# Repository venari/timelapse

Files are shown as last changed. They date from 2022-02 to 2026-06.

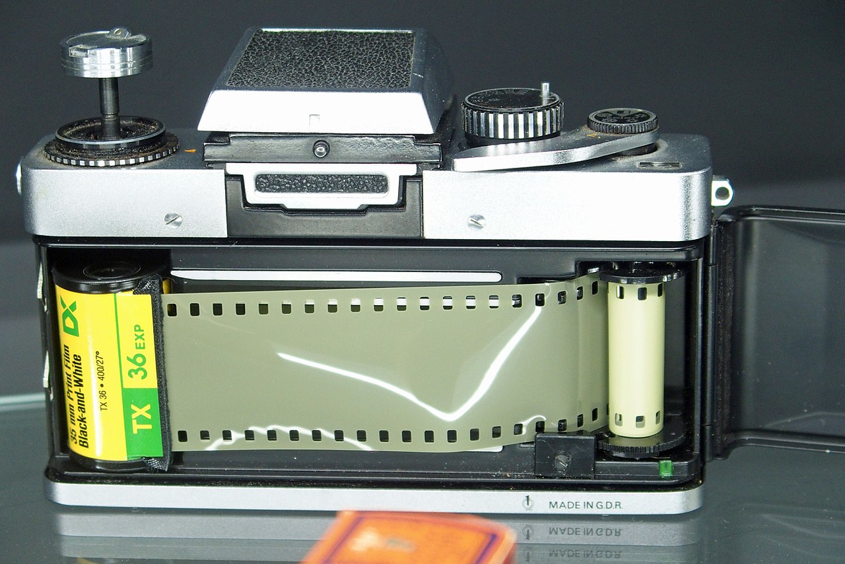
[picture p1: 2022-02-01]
timelapse.api/wwwroot/images/bg-404.jpg

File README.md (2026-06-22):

# timelapse
A set of tools/scripts to automate the taking and creation of timelapse videos and videos with a Raspberry Pi

# Current status of using PiJuice
> [!important]
> In November 2023, I posted an update regards the performance of the PiJuice, even when using PiSupply's own batteries.
>
> However, in the last month (November 2024) I've deployed one further camera that is not using a third party modem board [Waveshare SIM7600-H 4G HAT](https://www.waveshare.com/wiki/SIM7600X_4G_%26_LTE_Cat-1_HAT), but instead has reverted back to a USB thumb modem. Since swapping to this modem, the PiJuice board has behaved perfectly with no missed wakeups or random restarts.
> 
> In addition the ability to purchase PiSupply's PiJuice batteries seems to have returned (even if stock has not).
>
> TL;DR - as long as not combined with either a LiFePO4 battery chemistry or the Waveshare hat above, the PiJuice seems to perform well.
>
> As of June 2026, the PiJuice no longer appears to be being manufactured, an PiSupply appears to have been disolved.
> 
> This project is being migrated to use the PvPi 12V LiFePO4 solar battery charger.
> 
> Documentation will be updated in the coming months.

# PI Setup

Raspberry Pi OS Lite (32 bit - Pi Zero W)
Debian Bookworm - https://downloads.raspberrypi.org/raspios_lite_armhf/images/raspios_lite_armhf-2025-05-13/2025-05-13-raspios-bookworm-armhf-lite.img.xz

Raspberry Pi OS Lite (64 bit - Pi Zero 2 W
Debian Bookworm - https://downloads.raspberrypi.org/raspios_lite_arm64/images/raspios_lite_arm64-2025-05-13/2025-05-13-raspios-bookworm-arm64-lite.img.xz

Burn using Pi Imager. Give a default name, but you can change this inthe install script below.

Set username and password, and authentication methods as desired.

## All versions up to Bullseye.

Mount (reinsert) SD card
<!-- diskutil mount /dev/disk4s1 -->
```
cp ~/wpa_supplicant.conf /Volumes/bootfs
diskutil unmount /Volumes/bootfs
```

If updating the wpa_supplicant file, and you have network access:
```
scp ~/wpa_supplicant.conf pi@[pi name]:~
```
And then on the pi:
```
sudo cp ~/wpa_supplicant.conf /etc/wpa_supplicant/wpa_supplicant.conf
sudo reboot
```

## Bookworm onwards:
Bookworm uses NetorkManager rather than WPA Supplicant.

Ensure you have local wifi network access when you burn the image.

Individual network addition:
```
sudo nmcli dev wifi connect <wifi-ssid> password "<network-password>"
```

```
scp ~/nmcli-connect.sh pi@[pi name]:~
```
And then on the pi:
```
chmod u+x ~/nmcli-connect.sh
sudo ./nmcli-connect.sh
```

Note - this will only connect to WIFI networks that are present, so ensure modem stays with camera.

Turn on and find the pi
Pi Zero W 2:
```
arp -a | grep e4:5f
raspberrypi.lan (192.168.86.37) at e4:5f:1:5a:6e:b3 on en0 ifscope [ethernet]
```

Pi Zero W:
```
arp -a | grep b8:27
raspberrypi.lan (192.168.86.32) at b8:27:eb:94:ac:b1 on en0 ifscope [ethernet]

```

# Install (or update) software, (LiPo and LiFePO4, sedicam v2 configuration) config & code to new Pi:
```
sudo apt-get install byobu -y
byobu-enable
byobu
```
```
bash <(curl -fsSL "https://github.com/venari/timelapse/raw/main/install.sh?$RANDOM")
```

# Connect to intermitently connected Pi and tail log:
```
ssh -o ConnectTimeout=60 -o ConnectionAttempts=30 pi@sediment-pi-zero-w-v1-a 'tail -f -n 100 logs/timelapse.log'
```

Connect to intermitently connected Pi and trigger reboot:
```
ssh -o ConnectTimeout=60 -o ConnectionAttempts=30 pi@sediment-pi-zero-w-v1-a 'sudo reboot now'
```

Copy log files to local machine:
```
scp -o ConnectTimeout=60 -o ConnectionAttempts=30 pi@sediment-pi-zero-w-v1-a:/home/pi/logs/*.* .
```

# Review systemd job status
```
watch --color SYSTEMD_COLORS=1 systemctl status enviro*.service
```

# restart a systemd job
```
sudo systemctl restart envirocam-telemetry
sudo systemctl restart envirocam*
```

# Waveshare SIM6700X GSM/GPRS/GNSS HAT

- Enable Serial Communication
```
sudo raspi-config nonint do_serial 2        # Disable serial login shell and enable serial port hardware
sudo reboot
```

https://core-electronics.com.au/guides/raspberry-pi/raspberry-pi-4g-gps-hat/
```
sudo apt-get install minicom
pip3 install pyserial
wget https://www.waveshare.com/w/upload/2/29/SIM7600X-4G-HAT-Demo.7z
sudo apt-get install p7zip-full

7z x SIM7600X-4G-HAT-Demo.7z -r -o/home/pi

sudo chmod 777 -R /home/pi/SIM7600X-4G-HAT-Demo

sudo nano /etc/rc.local

```
Add following line, just above `exit 0`:

```
sh /home/pi/SIM7600X-4G-HAT-Demo/Raspberry/c/sim7600_4G_hat_init
```

```
cd /home/pi/SIM7600X-4G-HAT-Demo/Raspberry/c/bcm2835
chmod +x configure && ./configure && sudo make && sudo make install
```

Plug in USB cable, testing with minicom
CTRL-A, E to echo
CTRL-A, Q to exit
```
minicom -D /dev/ttyUSB2

AT+CPIN?
+CME ERROR:10 # No SIM card
```

Switch to RNDIS dial up mode
https://www.waveshare.com/wiki/Raspberry_Pi_RNDIS_dial-up_Internet_access
```
AT+CUSBPIDSWITCH=9011,1,1
```

Nope - prevents camera from working...

    Disable HDMI:
    https://picockpit.com/raspberry-pi/raspberry-pi-zero-2-battery/

    sudo raspi-config

    Then, go to Advanced Options -> GL Driver -> Legacy

    Add to /etc/rc.local:
    /usr/bin/tvservice -o

<!-- `camera.lensposition` - 1/distance in metres
- '0' - infinity
- '1': 1m
- `5`: 20cm
- `10`: 10cm -->

<!-- `camera.focus_m`: focus in metres -->

<!-- Add following to /boot/config.txt
```
dtoverlay=imx708
``` -->

# Waveshare 1.54" e-Paper Module
## Not may not work on Bookworm

https://github.com/waveshareteam/e-Paper/blob/master/RaspberryPi_JetsonNano/python/examples/epd_1in54b_V2_test.py

```
    sudo apt-get update
    sudo apt-get install python3-pip
    sudo apt-get install python3-pil
    sudo pip3 install RPi.GPIO
    sudo pip3 install waveshare-epaper
```

Onboard image resizing
```
sudo apt-get install imagemagick

convert pic/image.org.jpg -resize 200x200 -background white -gravity center -extent 200x200 pic/image.jpg 
```

- Enable Serial Communication
```
sudo raspi-config nonint do_spi 0        
sudo reboot
```

# Uptimed service

```
sudo apt-get install uptimed
sudo systemctl enable uptimed
```

# preview image over VNC
https://www.youtube.com/watch?v=dbBWyeHbGs0&ab_channel=WillyKjellstrom

Set screen VNC resolution:
sudo raspi-config
	-> 2 Display Options
		-> D5 VNC Resolution

To disable:
https://help.realvnc.com/hc/en-us/articles/5060068870813-Disabling-direct-capture-on-Raspberry-Pi-using-the-command-line
sudo sed -i '/CaptureTech/d' /root/.vnc/config.d/vncserver-x11
sudo vncserver-x11 -service -reload

Issues in Bullseye on Zero2? https://www.raspberrypi.com/news/bullseye-camera-system/

- related - possibly not - https://github.com/raspberrypi/libcamera-apps/issues/278
- 

# Access Hauwei thumb stick web interface (password is fiddly)
```
ssh -D 8080 pi@sediment-pi-[machine name]
```

Use FoxyProxy and setup proxy to localhost:8080

Browse to http://192.168.1.1/html/index.html or http://192.168.8.1/html/index.html

# On board timelapse generation

```
ffmpeg -r 30 -f image2 -pattern_type glob -i "./<YYYY-MM-DD>*.jpg" -s 1014x760 -vcodec libx264 <YYYY-MM-DD>.mp4
```

# Other timelapse generation examples

```
ffmpeg -r 30 -f image2 -pattern_type glob -i  "*11_2023-01-03*.jpg" -s 3280x1844 -vcodec libx264 output.mp4
```

## Overlay label and date/time in images:
```
mkdir -p mod

label="<Label for bottom left>"

for filename in <filter>_*.jpg; do 
    date_time="$(echo ${filename:3:10} ${filename:14:2}\\:${filename:16:2})"
    ffmpeg -i $filename -y -vf "drawtext=fontfile=/System/Library/Fonts/Avenir.ttc:text='$label':fontcolor=white:fontsize=90:box=1:boxcolor=black@0.3:boxborderw=5:x=10:y=h-th-10,drawtext=fontfile=/System/Library/Fonts/Avenir.ttc:text='$date_time':fontcolor=white:fontsize=90:box=1:boxcolor=black@0.3:boxborderw=5:x=w-tw-10:y=h-th-10" -hide_banner -loglevel error mod/$filename
done

ffmpeg  -pattern_type glob -i "mod/14_*.jpg" -vf "scale='min(1280,iw)':-2,format=yuv420p" -c:v libx264 -preset medium -profile:v main -c:a aac -shortest -movflags +faststart ../Output/<SiteName>.mp4
```

# Video stabilization

https://www.paulirish.com/2021/video-stabilization-with-ffmpeg-and-vidstab/

```
ffmpeg -i unstabilized.mp4 -vf vidstabdetect -f null -
ffmpeg -i unstabilized.mp4 -vf vidstabdetect=shakiness=1:tripod=1 -f null -
ffmpeg -i unstabilized.mp4 -vf vidstabtransform stabilized.mp4
```

Comparison video:
```
# vertically stacked
ffmpeg -i unstabilized.mp4 -i stabilized.mp4  -filter_complex vstack compare-stacked.mp4

# side-by-side
ffmpeg -i unstabilized.mp4 -i stabilized.mp4  -filter_complex hstack compare-sxs.mp4
```

# API Setup
Prerequisites:
- [Dotnet 6](https://dotnet.microsoft.com/en-us/download)
- [EFCore Tooling](https://docs.microsoft.com/en-au/ef/)
```
brew install dotnet-sdk
brew install pgadmin4
dotnet tool install --global dotnet-ef
```

Postgres DB Server:
```

docker pull postgres

mkdir ${HOME}/postgres-data/

docker run -d \
	--name dev-postgres \
	-e POSTGRES_PASSWORD=Pass2020! \
	-v ${HOME}/postgres-data/:/var/lib/postgresql/data \
        -p 5432:5432 \
        postgres

docker exec -it dev-postgres bash        
```

User Secrets:
```
dotnet tool install dotnet-user-secrets
dotnet user-secrets --project timelapse.api init
dotnet user-secrets --project timelapse.api set "ConnectionStrings:DefaultConnection" "Host=localhost;Port=5432;User ID=postgres;Password=Pass2020!;Database=timelapse"
```

When making changes to the objects in the code, add migrations and update the database script:
```
dotnet ef --project timelapse.api migrations add --context "AppDbContext" <migrationName>
dotnet ef --project timelapse.api migrations script -i --context "AppDbContext" -o timelapse.api/Migrations/scripts.sql
```

Updating database:
```
dotnet ef --project timelapse.api database update
```

# Enable Wake Up and set RTC Time

Note - Wake up should be automatically enabled in `saveTelemetry.py`, but you will need to set the RTC time during installation.
```
░░░░░░░░░░░░░░░░░░░░░░░░░░░░░░░░░░░░░░░░░░░░░░░░░░░░░░░░░░░░░░░░░░░░░░░░░░
░░░░░░░░░░░░░░░░░░░░░░░░░░░░░░░░░░░░░░░░░░░░░░░░░░░░░░░░░░░░░░░░░░░░░░░░░░
░░░░░░░░░░░░░░░░░░░░░░░░░░░░░░░░░░░░░░░░░░░░░░░░░░░░░░░░░░░░░░░░░░░░░░░░░░
░░░░░┌───────────────────────── PiJuice CLI ────────────────────────┐░░░░░
░░░░░│  Wakeup Alarm                                                │░░░░░
░░░░░│                                                              │░░░░░
░░░░░│  Status: OK                                                  │░░░░░
░░░░░│  UTC Time: Sun 2000-01-02 19:36:02                           │░░░░░
░░░░░│  [ ] Wakeup enabled                                          │░░░░░
░░░░░│  < Set RTC time    >                                         │░░░░░
░░░░░│                                                              │░░░░░
░░░░░│  (X) Day                      ( ) Weekday                    │░░░░░
░░░░░│  Day: 0                       [ ] Every day                  │░░░░░
░░░░░│  Hour: 0                      [ ] Every hour                 │░░░░░
░░░░░│                                                              │░░░░░
░░░░░│  (X) Minute                   ( ) Minutes period             │░░░░░
░░░░░│  Minute: 0                                                   │░░░░░
░░░░░│  Second: 0                                                   │░░░░░
░░░░░│                                                              │░░░░░
░░░░░│  < Set alarm >                                               │░░░░░
░░░░░│  < Back      >                                               │░░░░░
░░░░░│                                                              │░░░░░
░░░░░└──────────────────────────────────────────────────────────────┘░░░░░
░░░░░░░░░░░░░░░░░░░░░░░░░░░░░░░░░░░░░░░░░░░░░░░░░░░░░░░░░░░░░░░░░░░░░░░░░░
░░░░░░░░░░░░░░░░░░░░░░░░░░░░░░░░░░░░░░░░░░░░░░░░░░░░░░░░░░░░░░░░░░░░░░░░░░
░░░░░░░░░░░░░░░░░░░░░░░░░░░░░░░░░░░░░░░░░░░░░░░░░░░░░░░░░░░░░░░░░░░░░░░░░░
░░░░░░░░░░░░░░░░░░░░░░░░░░░░░░░░░░░░░░░░░░░░░░░░░░░░░░░░░░░░░░░░░░░░░░░░░░
〣 10 0:-*               3m 1.00 1.0GHz 367M13% 14G12% 2022-04-05 02:22:05

░░░░░░░░░░░░░░░░░░░░░░░░░░░░░░░░░░░░░░░░░░░░░░░░░░░░░░░░░░░░░░░░░░░░░░░░░░
░░░░░░░░░░░░░░░░░░░░░░░░░░░░░░░░░░░░░░░░░░░░░░░░░░░░░░░░░░░░░░░░░░░░░░░░░░
░░░░░░░░░░░░░░░░░░░░░░░░░░░░░░░░░░░░░░░░░░░░░░░░░░░░░░░░░░░░░░░░░░░░░░░░░░
░░░░░┌───────────────────────── PiJuice CLI ────────────────────────┐░░░░░
░░░░░│  Wakeup Alarm                                                │░░░░░
░░░░░│                                                              │░░░░░
░░░░░│  Status: OK                                                  │░░░░░
░░░░░│  UTC Time: Tue 2022-04-05 01:23:15                           │░░░░░
░░░░░│  [X] Wakeup enabled                                          │░░░░░  <---
░░░░░│  < Set RTC time    >                                         │░░░░░  <---
░░░░░│                                                              │░░░░░
░░░░░│  (X) Day                      ( ) Weekday                    │░░░░░
░░░░░│  Day: 0                       [ ] Every day                  │░░░░░
░░░░░│  Hour: 0                      [ ] Every hour                 │░░░░░
░░░░░│                                                              │░░░░░
░░░░░│  ( ) Minute                   (X) Minutes period             │░░░░░  <---
░░░░░│  Minute: 10                                                  │░░░░░  <---
░░░░░│  Second: 0                                                   │░░░░░
░░░░░│                                                              │░░░░░
░░░░░│  < Set alarm >                                               │░░░░░
░░░░░│  < Back      >                                               │░░░░░
░░░░░│                                                              │░░░░░
░░░░░└──────────────────────────────────────────────────────────────┘░░░░░
░░░░░░░░░░░░░░░░░░░░░░░░░░░░░░░░░░░░░░░░░░░░░░░░░░░░░░░░░░░░░░░░░░░░░░░░░░
░░░░░░░░░░░░░░░░░░░░░░░░░░░░░░░░░░░░░░░░░░░░░░░░░░░░░░░░░░░░░░░░░░░░░░░░░░
░░░░░░░░░░░░░░░░░░░░░░░░░░░░░░░░░░░░░░░░░░░░░░░░░░░░░░░░░░░░░░░░░░░░░░░░░░
░░░░░░░░░░░░░░░░░░░░░░░░░░░░░░░░░░░░░░░░░░░░░░░░░░░░░░░░░░░░░░░░░░░░░░░░░░
〣 10 0:-*               3m 1.00 1.0GHz 367M13% 14G12% 2022-04-05 02:23:15

```

# Battery min sleep/wake up levels:

```
░░░░░░░░░░░░░░░░░░░░░░░░░░░░░░░░░░░░░░░░░░░░░░░░░░░░░░░░░░░░░░░░░░░░░░░░░░░░░░░░░░░░░
░░░░░░░░░░░░░░░░░░░░░░░░░░░░░░░░░░░░░░░░░░░░░░░░░░░░░░░░░░░░░░░░░░░░░░░░░░░░░░░░░░░░░
░░░░░░░░░░┌───────────────────────── PiJuice CLI ────────────────────────┐░░░░░░░░░░░
░░░░░░░░░░│  System Task                                                 │░░░░░░░░░░░
░░░░░░░░░░│                                                              │░░░░░░░░░░░
░░░░░░░░░░│  [X] System task enabled                                     │░░░░░░░░░░░
░░░░░░░░░░│                                                              │░░░░░░░░░░░
░░░░░░░░░░│  [ ] Watchdog            Expire period          [ ] Restore  │░░░░░░░░░░░
░░░░░░░░░░│                          [minutes]: 4                        │░░░░░░░░░░░
░░░░░░░░░░│                                                              │░░░░░░░░░░░
░░░░░░░░░░│  [X] Wakeup on charge    Trigger level [%]: 20  [X] Restore  │░░░░░░░░░░░
░░░░░░░░░░│                                                              │░░░░░░░░░░░
░░░░░░░░░░│  [X] Min charge          Threshold [%]: 10                   │░░░░░░░░░░░
░░░░░░░░░░│                                                              │░░░░░░░░░░░
░░░░░░░░░░│  [ ] Min battery voltage 3.3                                 │░░░░░░░░░░░
░░░░░░░░░░│                                                              │░░░░░░░░░░░
░░░░░░░░░░│  [X] Software Halt Power Delay period [seconds]: 20          │░░░░░░░░░░░
░░░░░░░░░░│      Off                                                     │░░░░░░░░░░░
░░░░░░░░░░│                                                              │░░░░░░░░░░░
░░░░░░░░░░│  < Refresh        >                                          │░░░░░░░░░░░
░░░░░░░░░░│  < Apply settings >                                          │░░░░░░░░░░░
░░░░░░░░░░└──────────────────────────────────────────────────────────────┘░░░░░░░░░░░
░░░░░░░░░░░░░░░░░░░░░░░░░░░░░░░░░░░░░░░░░░░░░░░░░░░░░░░░░░░░░░░░░░░░░░░░░░░░░░░░░░░░░
░░░░░░░░░░░░░░░░░░░░░░░░░░░░░░░░░░░░░░░░░░░░░░░░░░░░░░░░░░░░░░░░░░░░░░░░░░░░░░░░░░░░░
```

# System Events

```
[X] Low Charge : <SYS_FUNC_HALT_POW_OFF>

```

# Battery Profiles

[Headway 38120s 10ah lifepo4 cell](https://evshop.eu/en/batteries/213-headway-lifepo4-38120s-32v-10ah.html)

```

░░░░░░░░░░░░░░░░░░░░░░░░░░░░░░░░░░░░░░░░░░░░░░░░░░░░░░░░░░░░░░░░░░░░░░░░░░
░░░░░┌───────────────────────── PiJuice CLI ────────────────────────┐░░░░░
░░░░░│  Battery settings                                            │░░░░░
░░░░░│                                                              │░░░░░
░░░░░│  Status: Custom profile by: HOST                             │░░░░░
░░░░░│  < Profile: CUSTOM       >                                   │░░░░░
░░░░░│                                                              │░░░░░
░░░░░│  [X] Custom                                                  │░░░░░  <-- Set to Custom
░░░░░│  Chemistry:                LIFEPO4                           │░░░░░  <-- Set to LIFEPO4
░░░░░│  Capacity [mAh]:           15000                             │░░░░░  <-- Set to 15000
░░░░░│  Charge current [mA]:      2500                              │░░░░░  <-- Set to 2500
░░░░░│  Termination current [mA]: 50                                │░░░░░
░░░░░│  Regulation voltage [mV]:  3600                              │░░░░░  <-- Set to 3600
░░░░░│  Cutoff voltage [mV]:      2500                              │░░░░░  <-- Set to 2500
░░░░░│  Cold temperature [C]:     0                                 │░░░░░
░░░░░│  Cool temperature [C]:     2                                 │░░░░░
░░░░░│  Warm temperature [C]:     49                                │░░░░░
░░░░░│  Hot temperature [C]:      65                                │░░░░░
░░░░░│  NTC B constant [1k]:      3450                              │░░░░░
░░░░░│  NTC resistance [ohm]:     10000                             │░░░░░
░░░░░│  OCV10 [mV]:               3131                              │░░░░░  <-- Set to 3131
░░░░░│  OCV50 [mV]:               3263                              │░░░░░  <-- Set to 3263
░░░░░│  OCV90 [mV]:               3303                              │░░░░░  <-- Set to 3303
░░░░░│  R10 [mOhm]:               91.0                              │░░░░░  <-- Set to 91
░░░░░│  R50 [mOhm]:               83.0                              │░░░░░  <-- Set to 83
░░░░░│  R90 [mOhm]:               76.0                              │░░░░░  <-- Set to 76
░░░░░│                                                              │░░░░░
░░░░░│  < Temperature sense: ON_BOARD    >                          │░░░░░  <-- Set to ON_BOARD
░░░░░│                                                              │░░░░░
░░░░░│  < Rsoc estimation: DIRECT_BY_MCU >                          │░░░░░  <-- Set to DIRECT_BY_MCU
░░░░░│                                                              │░░░░░
░░░░░│  < Refresh        >                                          │░░░░░
░░░░░│  < Apply settings >                                          │░░░░░
░░░░░│  < Back           >                                          │░░░░░
░░░░░└──────────────────────────────────────────────────────────────┘░░░░░
░░░░░░░░░░░░░░░░░░░░░░░░░░░░░░░░░░░░░░░░░░░░░░░░░░░░░░░░░░░░░░░░░░░░░░░░░░
░░░░░░░░░░░░░░░░░░░░░░░░░░░░░░░░░░░░░░░░░░░░░░░░░░░░░░░░░░░░░░░░░░░░░░░░░░

```

# Troubleshooting

## Troubleshooting PiJuice wakeup:

```
python3 /usr/bin/pijuice_log.py --enable WAKEUP_EVT
```

## Troubleshooting non-connecting camera:
- [Tailscale - machines connected in last week](https://login.tailscale.com/admin/machines?refreshed=true&q=lastseen%3A%3C1w)
- [Device Trends](https://timelapse-dev.azurewebsites.net/DeviceTrends)

### Failing to connect to Tailscale or timelapse-dev.azurewebsites.net:
- Consult Sediment camera troubleshooting/maintenance checklist.
- If you have physical access to the Pi.
  - Connect HDMI and USB adaptors, and connect keyboard and monitor.
  - Fire up Pi and watch for any error messages, for example complaining about corrupt filesystems, or kernel panics.
  - Log in as user:`pi`, password:`raspberry`.
    - Check network connection status:
      - `ifconfig`
      - `nmcli`
      - List devices: `nmcli device`
      - List known networks: `nmcli connection`
      - Check wireless is on: `nmcli radio`
      - List available wireless networks: `nmcli device wifi list`
      - Connect to CameraAP network: `nmcli device wifi connect CameraAP password GiveMeTheInternets`
    - If `nmcli` isn't available:
      - List wireless networks: `sudo iwlist wlan0 scan | grep ESSID`
      - To connect to network, edit the `/etc/wpa_supplicant/wpa_supplicant.conf` file to add a section, and then `sudo reboot` to restart:
      ````
      ctrl_interface=DIR=/var/run/wpa_supplicant GROUP=netdev
      update_config=1
      country=NZ

      network={
              ssid="CameraAP"
              psk="GiveMeTheInternets"
      }
      ````
    - Check tailscale status
      - `tailscale netcheck`
  - Further troubleshooting:
    - Check envirocam logs
      - `tail -f logs/intent.log`
      - `tail -f logs/timelapse.log`
      - `tail -f logs/intent.log`
      - `journalctl -u envirocam-telemetry.service`
    - Disconnect modem (to rule out data issues) and connect to working WiFi network, with SSID: `CameraAP`, password: `GiveMeTheInternets`.
    - Disconnect PiJuice to determine if that is causing issues.
    - Try fresh install of Raspbian on new SD card to rule out Pi Zero hardware issue.

# Battery notes

Naccon 3.7V 26650HP 5000mAh
On continuously
Charge from wall charger about 5 hours
Discharge 95 -> 5% about 12 hours.
Discharge 4 -> 1$ about 10 hours.

# Tailscale setup (optional)

Using [tailscale](https://github.com/tailscale/tailscale) to manage updates to pi's:

From https://tailscale.com/download/linux/rpi-bullseye:

```
curl -fsSL https://tailscale.com/install.sh | sh
```

```
sudo tailscale up
```

# To access modem/SMS messages

Use SSH to establish a dynamic port forwarding session to the pi.

```
ssh -D 8080 pi@<device name>
```

Use FoxyProxy to route local traffic on port 8080 through the SSH tunnel.

![Alt text](images/FoxyProxySettings.png)

Then browse to the modem's IP address (e.g. http://192.168.1.1)

# To check code versions
```
pssh --hosts ~/dev/venari/timelapse/hosts.txt -t 900 -i 'cd dev/timelapse; git log -1'
pssh --hosts ~/dev/venari/timelapse/hosts.txt -t 900 -x '-o ConnectTimeout=60 -o ConnectionAttempts=15' -i 'cd dev/timelapse; git log -1;git status'
pssh --hosts ~/dev/venari/timelapse/hosts.txt -t 900 -x '-o ConnectTimeout=60 -o ConnectionAttempts=15' -i 'cd dev/timelapse; git diff'
```

# Credits

3D models

- Raspberry Pi Camera Module v3 STL files: https://www.printables.com/model/368779-raspberry-pi-camera-module-3-v3/

# ESP32 version/links

https://www.waveshare.com/wiki/ESP32-S3-SIM7670G-4G

## Upload issue with CH34X driver
```
"/Users/leighhunt/Library/Arduino15/packages/esp32/tools/esptool_py/4.6/esptool" --chip esp32s3 --port "/dev/cu.usbmodem585A0118141" --baud 921600  --before default_reset --after hard_reset write_flash  -z --flash_mode keep --flash_freq keep --flash_size keep 0x0 "/private/var/folders/fx/2h8qyrk51114f5m1_x5dv7yc0000gn/T/arduino/sketches/E83F322CCBA20806EEF325130EA27172/take_photos.ino.bootloader.bin" 0x8000 "/private/var/folders/fx/2h8qyrk51114f5m1_x5dv7yc0000gn/T/arduino/sketches/E83F322CCBA20806EEF325130EA27172/take_photos.ino.partitions.bin" 0xe000 "/Users/leighhunt/Library/Arduino15/packages/esp32/hardware/esp32/3.0.1/tools/partitions/boot_app0.bin" 0x10000 "/private/var/folders/fx/2h8qyrk51114f5m1_x5dv7yc0000gn/T/arduino/sketches/E83F322CCBA20806EEF325130EA27172/take_photos.ino.bin" 
esptool.py v4.6
Serial port /dev/cu.usbmodem585A0118141
Connecting....
Chip is ESP32-S3 (revision v0.2)
Features: WiFi, BLE
Crystal is 40MHz
MAC: 84:fc:e6:51:84:68
Uploading stub...

A fatal error occurred: Failed to write to target RAM (result was 01070000: Operation timed out)
```

CH343 USB chip stuff: https://www.wch.cn/downloads/CH34XSER_MAC_ZIP.html
Arduino
- Board - ESP32S3 Dev Module
- Port - switch from /dev/cu.usbmodem585A0118141 Serial Port to /dev/cu.wchusbserial585A0118141 
- Serial Moonitor - /dev/cu.wchusbserial585A0118141, 115200 baud

VSCode with ESP-IDF
- Set board to ESP32S3
  - OpenOCD Configuration - ESP32-S3 chip (via ESP-PROG-2) seems to work
- Flash method to UART

Terminal attach to serial port:
```
screen /dev/cu.wchusbserial585A0118141 115200
```

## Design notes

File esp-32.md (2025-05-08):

# XAIO ESP32S3 Sense notes

[Getting Started with Seeed Studio XIAO ESP32S3 (Sense)](https://wiki.seeedstudio.com/xiao_esp32s3_getting_started/)
[Development board](https://wiki.seeedstudio.com/Seeeduino-XIAO-Expansion-Board/)
 - [U8g2 library](https://github.com/olikraus/U8g2_Arduino)
https://wiki.seeedstudio.com/xiao_esp32s3_camera_usage/

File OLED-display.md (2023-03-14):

# OLED display

OLED12864 - Digole 128x64 OLED display
I2C address 0x27.

```
sudo apt-get install i2c-tools
```

```
sudo raspi-config
```

3 Interface Options -> I5 I2C -> Yes

```
$ sudo i2cdetect -l
i2c-1	i2c       	bcm2835 (i2c@7e804000)          	I2C adapter
i2c-2	i2c       	bcm2835 (i2c@7e805000)          	I2C adapter
```

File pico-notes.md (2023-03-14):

# Wifi connect

```
import network
import time

wlan = network.WLAN(network.STA_IF)
wlan.active(True)

ssid = "<SSID>"
pw = "<Password>"

wlan.connect(ssid, pw)

def light_onboard_led():
    led = machine.Pin('LED', machine.Pin.OUT)
    led.on();

timeout = 10
while timeout > 0:
    if wlan.status() >= 3:
        light_onboard_led()
        break
    timeout -= 1
    print('Waiting for connection...')
    time.sleep(1)
   
wlan_status = wlan.status()

print("My IP address is", wlan.ifconfig())
print(wlan_status)
```

# On-board - temp sense

```
import machine
import time

temp_sensor = machine.ADC(4)

while True:
    adc_voltage = temp_sensor.read_u16() * 3.3 / 65535
    cpu_temp = 27 - (adc_voltage - 0.706)/0.001721 # Formula given in RP2040 Datasheet
    print(cpu_temp)
    time.sleep_ms(1_000)
```

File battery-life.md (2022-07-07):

Indicative battery timings:

4 days left charging - average weather but good view of sun - with 40W solar panel. June 23 - 26. 
Powered on continuously for 10 hours/day.
Detached 26th - 12V battery kept it charged until 10am Jun 29, thereafter onboard Lithium Ion took over and lasted a further [] hours.
4pm 26th -> 10am 29th = 2 complete days (including running to 3am on 29th)
Actual powered time: 36 hours from 12V 6.5AH battery.
Duty Cycle 50% (7am-7pm) would give 3 days/72 hours battery life with no sunlight.
Plus around 3 hours on SB-2299 2600mAh LiPo until shutdown. (scanning for updates to upload every 10 seconds)

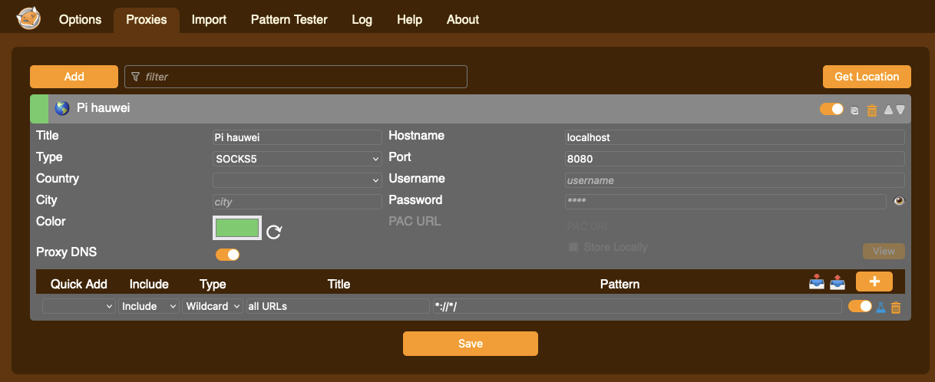
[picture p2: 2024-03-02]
images/FoxyProxySettings.png

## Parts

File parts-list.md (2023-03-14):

Parts list:

| Part | Link 
|---|---
|Enclosure: [Spelsberg TK PS 2518-9-o](https://www.spelsberg.com/industrial-housing/with-/-without-metric-knock-outs/11040801/) (254 x 180 x 90 mm), |via [RS](https://nz.rs-online.com/web/p/general-purpose-enclosures/0220462)
|3D layout enclosure insert | [Tinkercad - Timelapse camera plan v1](https://www.tinkercad.com/things/5YuyqixHnNj)
|18650 Battery | [SB2299 2600mAh Li-ion Protected Battery](https://www.jaycar.co.nz/18650-2600mah-li-ion-protected-battery/p/SB2299)
|18650 Battery Holder | [PH9205 - Single 18650 Battery Holder](https://www.jaycar.co.nz/single-18650-battery-holder/p/PH9205)
|LM2596/XC4514 DC-DC Buck Converter | [Arduino Compatible DC Voltage Regulator](https://www.jaycar.co.nz/arduino-compatible-dc-voltage-regulator/p/XC4514)
|Raspberry Pi Zero 2W |
|PiJuice Zero |
|Camera | [Raspberry Pi Camera Module v3](https://www.pbtech.co.nz/product/SEVRBP0396/Raspberry-Pi-Official-Camera-Module-3-Updated-Vers) 75 degrees
| | [Raspberry Pi Camera Module v3 Wide](https://www.pbtech.co.nz/product/SEVRBP0398/Raspberry-Pi-Official-Camera-Module-3-Wide-Version) 120 degrees
| | [Raspberry Pi Camera Module v3 NoIR](https://www.pbtech.co.nz/product/SEVRBP0397/Raspberry-Pi-Official-Camera-Module-3-NoIR-Updated) 75 degrees
| | [Raspberry Pi Camera Module v3 NoIR Wide](https://www.pbtech.co.nz/product/SEVRBP0399/Raspberry-Pi-Official-Camera-Module-3-NoIR-Wide-Ve) 120 degrees
|Solar Panel option 1 | [ZM9052 - 12V 20W](https://www.jaycar.co.nz/12v-20w-solar-panel-with-clips/p/ZM9052)
|Solar Panel option 2 | [ZM9056 - 12V 40W](https://www.jaycar.co.nz/12v-40w-monocrystalline-solar-panel/p/ZM9056)
|Solar Power connector - socket | [PS1017 - Waterproof IP67 XLR Line Socket](https://www.jaycar.co.nz/waterproof-ip67-xlr-line-socket/p/PS1017)
|Solar Power connector - plug | [PP1014 - IPX6 Surface Mount XLR Male Connector](https://www.jaycar.co.nz/ipx6-surface-mount-xlr-male-connector/p/PP1014)
| Old Parts |
|Camera | [Raspberry Pi HQ Camera](https://www.pbtech.co.nz/product/SEVRBP0263/Raspberry-Pi-HQ-Camera-123-MP-Official-High-Qualit)
|Lens | [CS-Mount 6mm Wide Angle](https://www.pbtech.co.nz/product/SEVRBP0265/Raspberry-Pi-Camera-Lenses-PT361060M3MP12-CS-Mount)
|12V SLA Battery | [SB2485 12V 6.5Ah SLA Battery](https://www.jaycar.co.nz/12v-6-5ah-sla-battery/p/SB2485)

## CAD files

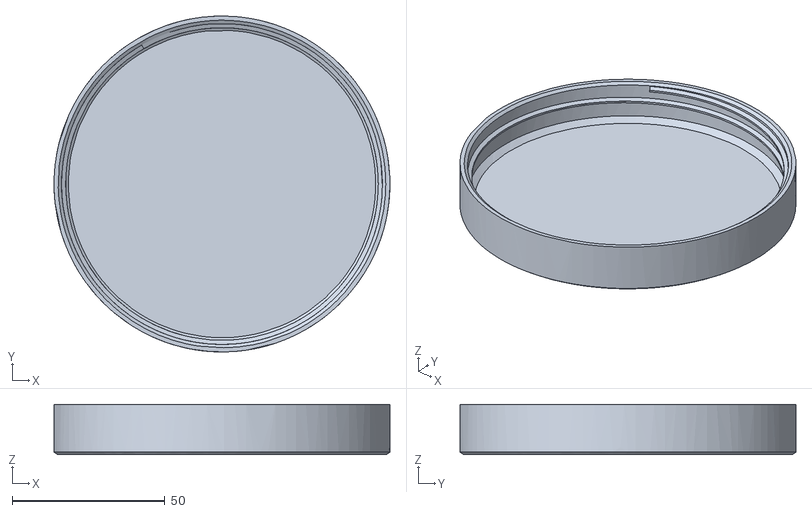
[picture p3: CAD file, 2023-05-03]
3d-models/top cap.110mm.stl
110.0 x 110.0 x 16.4

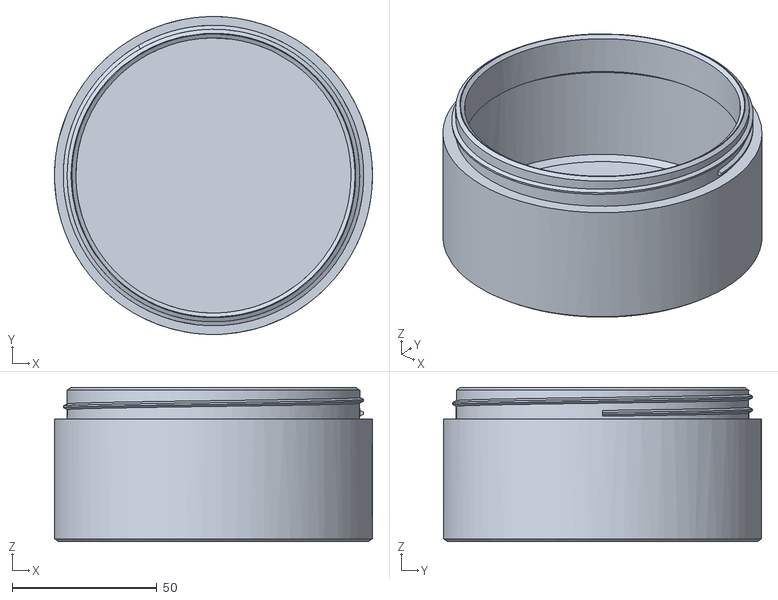
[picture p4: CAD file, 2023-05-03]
3d-models/end cap.110mm.stl
110.0 x 110.0 x 53.4

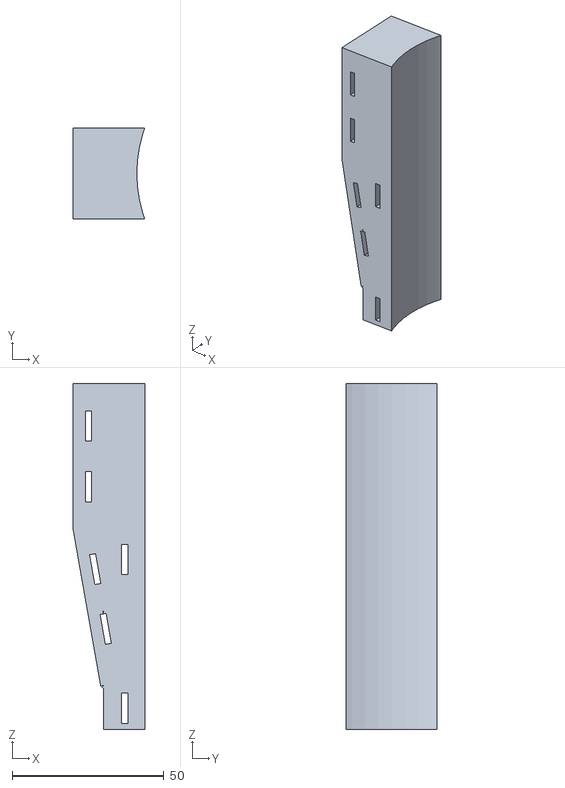
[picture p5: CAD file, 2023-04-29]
3d-models/mount.stl
23.6 x 30.0 x 114.0

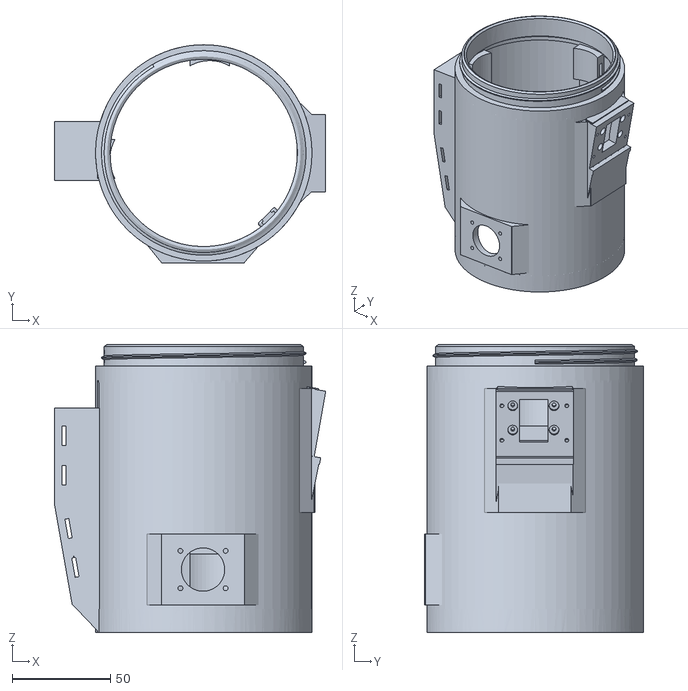
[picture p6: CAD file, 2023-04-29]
3d-models/enclosure.110mm.stl
138.0 x 111.1 x 146.4

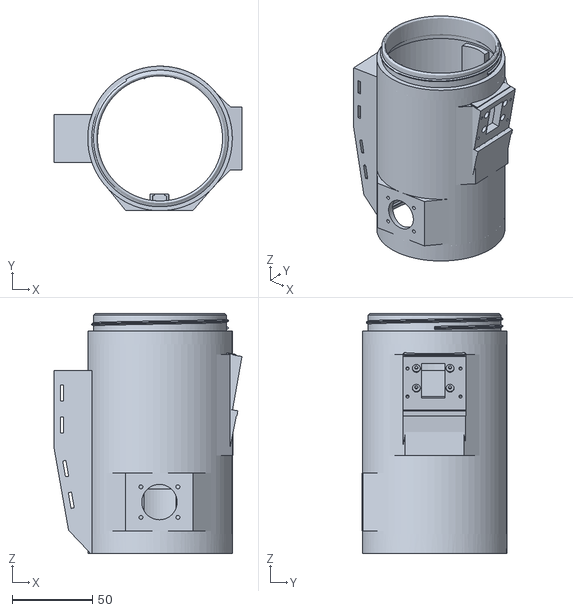
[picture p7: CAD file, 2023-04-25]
3d-models/enclosure.90mm.stl
117.0 x 90.1 x 149.4

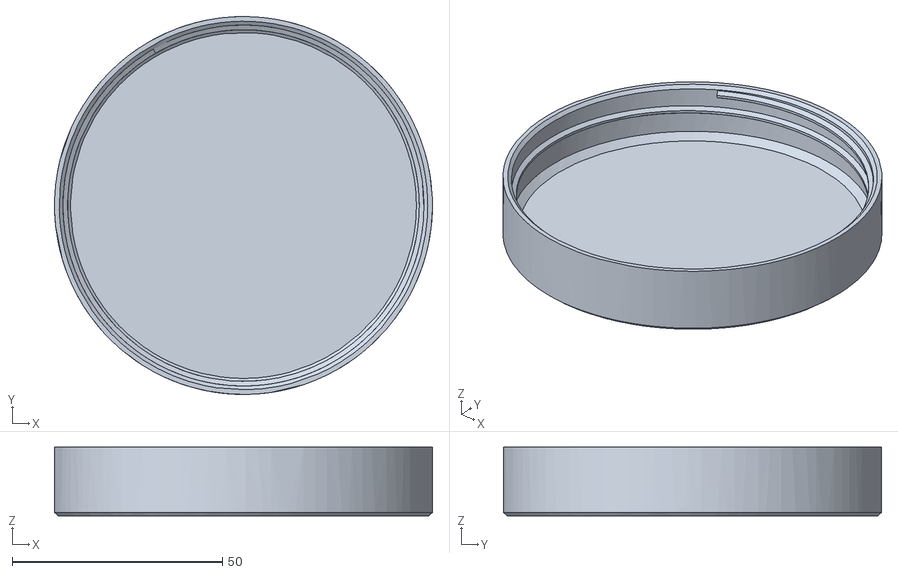
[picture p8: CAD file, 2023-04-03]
3d-models/top cap.90mm.stl
90.0 x 90.0 x 16.4

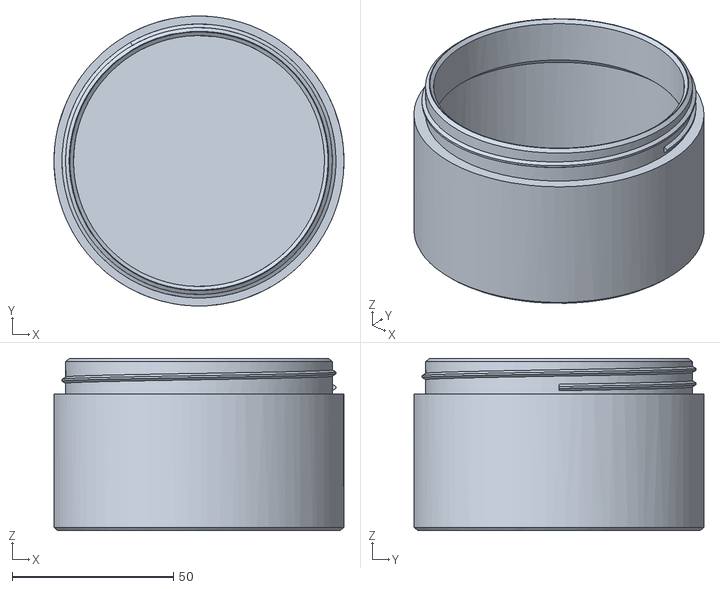
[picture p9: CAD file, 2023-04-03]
3d-models/end cap.90mm.stl
90.0 x 90.0 x 53.4

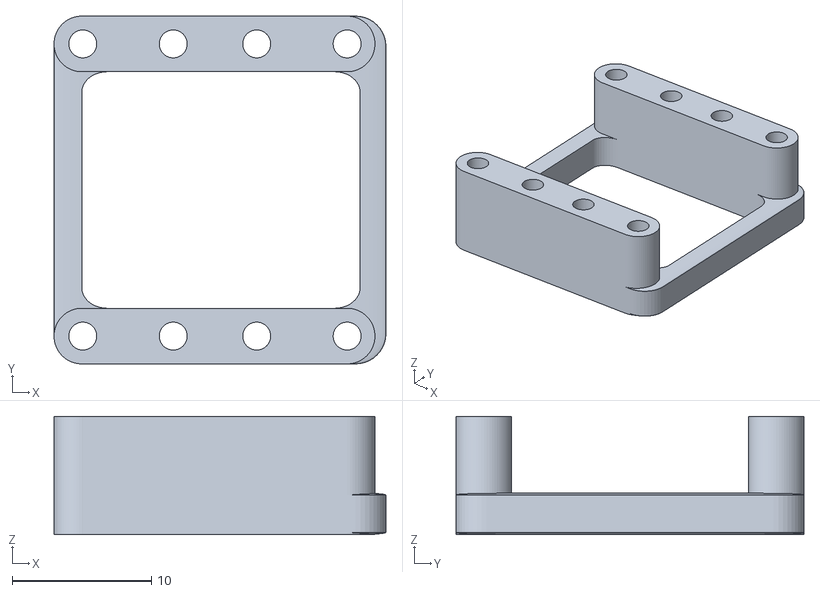
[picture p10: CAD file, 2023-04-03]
3d-models/camera mount.stl
23.9 x 25.0 x 8.50

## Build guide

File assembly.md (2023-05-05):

# Assembly

## Solar Power
Parts:
- [ZM9056 - 12V 40W](https://www.jaycar.co.nz/12v-40w-monocrystalline-solar-panel/p/ZM9056)
- [PS1017 - Waterproof IP67 XLR Line Socket](https://www.jaycar.co.nz/waterproof-ip67-xlr-line-socket/p/PS1017)

1. Cut solar power connectors off solar panel, and solder XLR socker to wires. Positive to Pin <1 - check> and Negative to Pin <check - 2 or 3>
1. Wrap with heat shrink tubing.

## Power in

Parts:
- [PP1014 - IPX6 Surface Mount XLR Male Connector](https://www.jaycar.co.nz/ipx6-surface-mount-xlr-male-connector/p/PP1014)
- LM2596 based [Arduino Compatible DC Voltage Regulator](https://www.jaycar.co.nz/arduino-compatible-dc-voltage-regulator/p/XC4514)
- Terminal block - 2 terminals

1. Connect positive wire between Pin 1 of XLR Male Connector and terminal 1 of terminal block.
1. Connect negative wire between Pin <check - 2 or 3> and terminal 2 of terminal block.
1. Connect another positive wire between terminal 1 of terminal block and Positive IN of LM2596.
1. Connect another negative wire between terminal 2 of terminal block and Negative IN of LM2596.
1. Connect positive wire terminated in Jumper socket to Positive OUT of LM2596. This goes to [Positive Pin of J4](https://github.com/PiSupply/PiJuice/tree/master/Hardware#connectors) on PiJuice Zero.
1. Connect negative wire terminated in Jumper socket to Negative OUT of LM2596. This goes to Negative Pin of J4 on PiJuice Zero.

## Pi mounting

4 x M2.5 x 6 screw
1 x Plastic mount
4 x M2.5 x 6 Pozi Pan (DIN7985)
4 x M2.5 nut (DIN934)
1 x Pi Zero
4 x Pi Juice Zero spacer
1 x Pi Juice Zero
4 x Pi Juice Zero M2.5 screw

## Camera mounting and connecting

4 x M2 x 6 screw 
1 x Camera
1 x Plastic mount

## Mount camera mount to enclosure
<Outside>
4 x M2 x 6 screw 
<enclosure>
1 x Plastic mount
<Inside>

## Mount window to enclosure
Drill out 4 holes in acrylic to 2.5mm so that M2.5 screws can pass through.
<Outside>
4 x M2.5 x 6 Pozi Pan (DIN7985)
<enclosure>

## Cellular 3.3V -> 5V power.

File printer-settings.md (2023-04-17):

Printer settings

PETG Attempt 1

FlashPrint
Printer
 - Material Type - Flashforge-PETG
 - Extruder Temperature - 240
- Raft
 - General 
  - Disable Raft

Not bad, but a bit of stringing on internal walls

PETG Attempt 2

As above, plus:
- General
 - Speed
  - Base Print Speed 50mm/s -> 30mm/s

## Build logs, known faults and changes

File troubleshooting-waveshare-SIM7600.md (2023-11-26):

$ pip3 install atcom

$ atcom --port /dev/ttyUSB2 "AT+CPIN?"
AT+CPIN?
+CPIN: READY

OK

$ python3 dev/timelapse/scripts/PowerOnSIM7600.py 

$ atcom --port /dev/serial0 "AT+CPIN?"
AT+CPIN?
+CPIN: READY

OK

# Set text mode
```
$ atcom --port /dev/serial0 "AT+CMGF=1"

OK

```

# Check message storage
```
$ atcom --port /dev/serial0 "AT+CPMS?"

+CPMS: "SM",10,10,"SM",10,10,"SM",10,10

OK
```

# Read all messages
```
$ atcom --port /dev/serial0 'AT+CMGL="ALL"'
+CMGL: 0,"REC READ","791101017890","","23/09/13,14:38:05+48"
You have no Prepay credit. For easy ways to top up check out one.nz/topup or view your balance and top up from our My One NZ app.
+CMGL: 2,"REC READ","+64xxxxxxxxx","","23/09/14,17:01:14+48"
Hello
+CMGL: 3,"REC READ","+64xxxxxxxxx","","23/09/14,17:17:16+48"
Hello 2

OK
```

# Delete message at index 0
```
$ atcom --port /dev/serial0 'AT+CMGD=0'

OK
```

# Delete all messages
```
$ atcom --port /dev/serial0 'AT+CMGD=0,1'

OK
```

pi@timelapse-camera-ethan:~ $ lsusb
Bus 001 Device 003: ID 1e0e:9011 Qualcomm / Option SimTech, Incorporated
Bus 001 Device 001: ID 1d6b:0002 Linux Foundation 2.0 root hub

https://www.waveshare.com/wiki/Raspberry_Pi_RNDIS_dial-up_Internet_access

ls /dev/ttyUSB*
sudo apt-get install minicom
sudo minicom -D /dev/ttyUSB2

    Send the following command through minicom, then wait for the module to restart

AT+CUSBPIDSWITCH=9011,1,1

```
$ atcom --port /dev/serial0 'AT+CUSBPIDSWITCH=9011,1,1'

OK
```

$ ifconfig
lo: flags=73<UP,LOOPBACK,RUNNING>  mtu 65536
        inet 127.0.0.1  netmask 255.0.0.0
        inet6 ::1  prefixlen 128  scopeid 0x10<host>
        loop  txqueuelen 1000  (Local Loopback)
        RX packets 34  bytes 5388 (5.2 KiB)
        RX errors 0  dropped 0  overruns 0  frame 0
        TX packets 34  bytes 5388 (5.2 KiB)
        TX errors 0  dropped 0 overruns 0  carrier 0  collisions 0

tailscale0: flags=4305<UP,POINTOPOINT,RUNNING,NOARP,MULTICAST>  mtu 1280
        inet 100.99.137.23  netmask 255.255.255.255  destination 100.99.137.23
        inet6 fd7a:115c:a1e0:ab12:4843:cd96:6263:8917  prefixlen 128  scopeid 0x0<global>
        inet6 fe80::5ead:5c8d:818f:9505  prefixlen 64  scopeid 0x20<link>
        unspec 00-00-00-00-00-00-00-00-00-00-00-00-00-00-00-00  txqueuelen 500  (UNSPEC)
        RX packets 336  bytes 32152 (31.3 KiB)
        RX errors 0  dropped 0  overruns 0  frame 0
        TX packets 265  bytes 151544 (147.9 KiB)
        TX errors 0  dropped 0 overruns 0  carrier 0  collisions 0

wlan0: flags=4163<UP,BROADCAST,RUNNING,MULTICAST>  mtu 1500
        inet 172.20.10.189  netmask 255.255.255.0  broadcast 172.20.10.255
        inet6 fe80::3c49:882d:b422:dc54  prefixlen 64  scopeid 0x20<link>
        ether b8:27:eb:f2:b7:bf  txqueuelen 1000  (Ethernet)
        RX packets 1307  bytes 226152 (220.8 KiB)
        RX errors 0  dropped 0  overruns 0  frame 0
        TX packets 2143  bytes 1913408 (1.8 MiB)
        TX errors 0  dropped 0 overruns 0  carrier 0  collisions 0

wwan0: flags=4163<UP,BROADCAST,RUNNING,MULTICAST>  mtu 1500
        inet 169.254.224.15  netmask 255.255.0.0  broadcast 169.254.255.255
        inet6 fe80::745e:2070:1e49:c19b  prefixlen 64  scopeid 0x20<link>
        ether 9a:43:75:56:8f:7e  txqueuelen 1000  (Ethernet)
        RX packets 0  bytes 0 (0.0 B)
        RX errors 0  dropped 0  overruns 0  frame 0
        TX packets 32  bytes 5180 (5.0 KiB)
        TX errors 0  dropped 0 overruns 0  carrier 0  collisions 0

curl -s http://icanhazip.com

Verify IP address is different to wireless network.

sudo apt-get install libqmi-utils

./

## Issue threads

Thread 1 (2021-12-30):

Create script to log power and temperature every ten minutes

leighghunt, 2021-12-30:
Log battery power remaining, and temperature to a CSV log file.

Possibly helpful links:

- https://raspberrypi-guide.github.io/other/boot-automation-pijuice
-

ethandhunt, 2022-01-03:
Runs on restart with cron tab
Appends to log.csv in same dir as file in format yyy-mm-dd hh:mm:ss, battery%, temperatureInCelsius

```py
print('Logging...')

from pijuice import PiJuice
import time
import os

pj = PiJuice(1, 0x14) #?

log = f'{time.strftime("%Y-%m-%d %H:%M:%S", time.localtime())}, {pj.status.GetChargeLevel()["data"]}, {pj.status.GetBatteryTemperature()["data"]}\n'

outFile = os.path.dirname(os.path.realpath(__file__)) + '/log.csv'

with open(outFile, 'a') as f:
    f.write(log)

print('Logging complete')
```

Closed 2022-01-03.

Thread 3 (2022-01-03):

Update battery/temp logging code to also send data to API

leighghunt, 2022-01-03:
Use HTTP POST to send data to API.

I'll update the ticket when address and format are known.

Make sure that URL is configurable - so we have one API URL configured for main site.

Note: Dependant on #2

leighghunt, 2022-01-27:
API endpoints:

- https://timelapse-dev.azurewebsites.net/swagger/index.html

Example curl commands:

### Device:
```
curl -X 'POST' \
  'https://timelapse-dev.azurewebsites.net/api/Devices?Name=Pi%20unit%201&Description=Some%20descriptive%20text' \
  -H 'accept: text/plain' \
  -d ''
```
Response:
```
{
  "id": 2,
  "name": "Pi unit 1",
  "description": "Some descriptive text",
  "latestTelemetry": null
}
```

### Telemetry:
```
curl -X 'POST' \
  'https://timelapse-dev.azurewebsites.net/api/Telemetry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' \
  -H 'accept: text/plain' \
  -d ''
```
Response:
```
{
  "id": 0,
  "name": "string",
  "description": "string",
  "latestTelemetry": {
    "id": 0,
    "timestamp": "2022-01-27T09:18:46.503Z",
    "temperatureC": 0,
    "batteryPercent": 0,
    "diskSpaceFree": 0,
    "uptimeSeconds": 0,
    "deviceId": 0,
    "device": "string"
  }
}
```

Closed 2022-02-07.

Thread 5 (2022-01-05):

Seem to be having problems getting RTC to update time.

leighghunt, 2022-01-05:
Looks like the RTC isn't being read correctly by the `test.py` script.

Error when run interactively if I remember correctly is:

```
sudo hwclock -v
...
...
No usable clock interface found.
hwclock: Cannot access the Hardware Clock via any known method.
```

leighghunt, 2022-01-05:
Exact issue:

```
hwclock from util-linux 2.33.1
System Time: 1641344696.108635
Trying to open: /dev/rtc0
Trying to open: /dev/rtc
Trying to open: /dev/misc/rtc
No usable clock interface found.
hwclock: Cannot access the Hardware Clock via any known method.
```

leighghunt, 2022-01-05:
@ethandhunt take a peek here: https://github.com/PiSupply/PiJuice/blob/master/Software/README.md#pijuice-rtc

leighghunt, 2022-01-05:
Actually, it looks like it was working all along, and it was a permissions issue making my test results give me the wrong impression.

```
pi@raspberrypi:~$ hwclock -r
hwclock: Cannot access the Hardware Clock via any known method.
hwclock: Use the --verbose option to see the details of our search for an access method.
pi@raspberrypi:~$ sudo hwclock -r
2022-01-05 21:55:40.825376+13:00
```

leighghunt, 2022-05-25:
Running into this again on timelapse-pi-3 - a zero v2 with camera attached.

leighghunt, 2022-05-25:
`rpi-update` didn't work.

```
pi@timelapse-pi-3:~ $ sudo rpi-update
 *** Raspberry Pi firmware updater by Hexxeh, enhanced by AndrewS and Dom
 *** Performing self-update
 *** Relaunching after update
 *** Raspberry Pi firmware updater by Hexxeh, enhanced by AndrewS and Dom
 *** We're running for the first time
 *** Backing up files (this will take a few minutes)
 *** Backing up firmware
 *** Backing up modules 5.10.103-v7+
#############################################################
WARNING: This update bumps to rpi-5.15.y linux tree
See: https://forums.raspberrypi.com/viewtopic.php?t=322879

'rpi-update' should only be used if there is a specific
reason to do so - for example, a request by a Raspberry Pi
engineer or if you want to help the testing effort
and are comfortable with restoring if there are regressions.

DO NOT use 'rpi-update' as part of a regular update process.
##############################################################
Would you like to proceed? (y/N)
 *** Downloading specific firmware revision (this will take a few minutes)
  % Total    % Received % Xferd  Average Speed   Time    Time     Time  Current
                                 Dload  Upload   Total   Spent    Left  Speed
  0     0    0     0    0     0      0      0 --:--:-- --:--:-- --:--:--     0
100  111M  100  111M    0     0  3166k      0  0:00:36  0:00:36 --:--:-- 3539k
 *** Updating firmware
 *** Updating kernel modules
 *** depmod 5.15.41-v7+
 *** depmod 5.15.41-v8+
 *** depmod 5.15.41-v7l+
 *** depmod 5.15.41+
 *** Updating VideoCore libraries
 *** Using HardFP libraries
 *** Updating SDK
 *** Running ldconfig
 *** Storing current firmware revision
 *** Deleting downloaded files
 *** Syncing changes to disk
 *** If no errors appeared, your firmware was successfully updated to 8f5fae4c6cba16e3064ecfda7dc998bb8d430fdc
 *** A reboot is needed to activate the new firmware

pi@timelapse-pi-3:~ $ sudo shutdown -r now
Connection to timelapse-pi-3 closed by remote host.
Connection to timelapse-pi-3 closed.
```

```
Linux timelapse-pi-3 5.15.41-v7+ #1557 SMP Mon May 23 16:46:23 BST 2022 armv7l

The programs included with the Debian GNU/Linux system are free software;
the exact distribution terms for each program are described in the
individual files in /usr/share/doc/*/copyright.

Debian GNU/Linux comes with ABSOLUTELY NO WARRANTY, to the extent
permitted by applicable law.
Last login: Wed May 25 19:23:15 2022 from 192.168.86.239

SSH is enabled and the default password for the 'pi' user has not been changed.
This is a security risk - please login as the 'pi' user and type 'passwd' to set a new password.

pi@timelapse-pi-3:~ $ sudo hwclock -r
hwclock: Cannot access the Hardware Clock via any known method.
hwclock: Use the --verbose option to see the details of our search for an access method.
pi@timelapse-pi-3:~ $

```

leighghunt, 2022-05-26:
Tried adding the following to `/boot/config.txt' - looks like it may have worked?

```
dtoverlay=i2c-rtc,ds1307=1
```

Before reboot:
```
pi@timelapse-pi-3:~ $ i2cdetect -y 1
     0  1  2  3  4  5  6  7  8  9  a  b  c  d  e  f
00:          -- -- -- -- -- -- -- -- -- -- -- -- --
10: -- -- -- -- 14 -- -- -- -- -- -- -- -- -- -- --
20: -- -- -- -- -- -- -- -- -- -- -- -- -- -- -- --
30: -- -- -- -- -- -- -- -- -- -- -- -- -- -- -- --
40: -- -- -- -- -- -- -- -- -- -- -- -- -- -- -- --
50: -- -- -- -- -- -- -- -- -- -- -- -- -- -- -- --
60: -- -- -- -- -- -- -- -- 68 -- -- -- -- -- -- --
70: -- -- -- -- -- -- -- --            

pi@timelapse-pi-3:~ $ sudo hwclock -r --verbose
hwclock from util-linux 2.33.1
System Time: 1653523396.609578
Trying to open: /dev/rtc0
Trying to open: /dev/rtc
Trying to open: /dev/misc/rtc
No usable clock interface found.
hwclock: Cannot access the Hardware Clock via any known method.
```

After reboot:

```
pi@timelapse-pi-3:~ $ i2cdetect -y 1
     0  1  2  3  4  5  6  7  8  9  a  b  c  d  e  f
00:          -- -- -- -- -- -- -- -- -- -- -- -- --
10: -- -- -- -- 14 -- -- -- -- -- -- -- -- -- -- --
20: -- -- -- -- -- -- -- -- -- -- -- -- -- -- -- --
30: -- -- -- -- -- -- -- -- -- -- -- -- -- -- -- --
40: -- -- -- -- -- -- -- -- -- -- -- -- -- -- -- --
50: -- -- -- -- -- -- -- -- -- -- -- -- -- -- -- --
60: -- -- -- -- -- -- -- -- UU -- -- -- -- -- -- --
70: -- -- -- -- -- -- -- --     

pi@timelapse-pi-3:~ $ sudo hwclock -r --verbose
hwclock from util-linux 2.33.1
System Time: 1653525992.881547
Trying to open: /dev/rtc0
Using the rtc interface to the clock.
Assuming hardware clock is kept in UTC time.
Waiting for clock tick...
ioctl(4, RTC_UIE_ON, 0): Invalid argument
Waiting in loop for time from /dev/rtc0 to change
...got clock tick
Time read from Hardware Clock: 2022/05/26 00:46:33
Hw clock time : 2022/05/26 00:46:33 = 1653525993 seconds since 1969
Time since last adjustment is 1653525993 seconds
Calculated Hardware Clock drift is 0.000000 seconds
2022-05-26 12:46:32.877484+12:00

```

leighghunt, 2023-03-24:
Main resolution was to add `dtoverlay=i2c-rtc,ds1307=1` to `boot/config.txt`.

Closed 2023-03-24.

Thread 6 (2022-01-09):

Camera no longer working

leighghunt, 2022-01-09:
```
$ raspistill -vf -hf  -ISO 200 --nopreview -ss 6000000 -br 80 -co 100 -o out6s200ISO.jpeg

Camera control callback  cmd=0x4f525245mmal: No data received from sensor. Check all connections, including the Sunny one on the camera board
```

leighghunt, 2022-01-09:
Reconnecting battery and all connections seemed to resolve this. So was either a loose connection, or somehow the setup had got confused, and wasn't resetting as it continuously had power from the battery.

Closed 2022-01-09.

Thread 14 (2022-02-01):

Camera error

ethandhunt, 2022-02-01:
```
mmal: mmal_vc_component_enable: failed to enable component: ENOSPC
Camera component couldn't be enabled: Out of resources (other than memory)
```

ethandhunt, 2022-02-01:
found post here: [https://raspberrypi.stackexchange.com/questions/26829/picamera-not-working](url)

ethandhunt, 2022-02-01:
was making camera twice

ethandhunt, 2022-02-01:
```
@@ -60,12 +60,7 @@ def saveAndUploadPhoto():
                                                                                     
     txtTime = datetime.datetime.now().strftime('%Y-%m-%d %H:%M:%S')
                                     
-    camera.start_preview()
-    time.sleep(2)         
-    camera.capture(outputImageFolder + txtTime + '.jpg')
-                                 
     print('beginning capture')                     
-    camera = PiCamera()     
     camera.vflip = True                                     
     camera.hflip = True           
     #camera.resolution = (1024, 768)
     ```

Closed 2022-02-01.

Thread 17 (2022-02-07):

Pi stopped logging telemetry, battery seems drained

leighghunt, 2022-02-07:
Possibly something got corrupted in git directory, prevented from sleeping?

```
pi@raspberrypi:~/dev/timelapse$ ./scripts/startup.sh
~/dev/timelapse/scripts ~/dev/timelapse
++ ping -c 1 -W 1 venari.co.nz
PING venari.co.nz (185.199.108.153) 56(84) bytes of data.
64 bytes from cdn-185-199-108-153.github.com (185.199.108.153): icmp_seq=1 ttl=64 time=45.0 ms

--- venari.co.nz ping statistics ---
1 packets transmitted, 1 received, 0% packet loss, time 0ms
rtt min/avg/max/mdev = 44.955/44.955/44.955/0.000 ms
+++ date
++ echo Tue Feb 8 08:09:17 NZDT 2022
++ echo 'network interface seems to be up'
++ echo
++ date
++ /usr/bin/python3 coreScript.py
++ echo
++ date
++ echo '> git pull'
++ /usr/bin/git pull
error: object file .git/objects/a5/1a81f3a886a96db64ee8dcb36e3a369cd98f6a is empty
fatal: loose object a51a81f3a886a96db64ee8dcb36e3a369cd98f6a (stored in .git/objects/a5/1a81f3a886a96db64ee8dcb36e3a369cd98f6a) is corrupt
+++ date
++ echo Tue Feb 8 08:09:17 NZDT 2022
++ echo 'startup script finished'
++ popd
~/dev/timelapse
pi@raspberrypi:~/dev/timelapse$ ls -la .git/objects/a5/
1a81f3a886a96db64ee8dcb36e3a369cd98f6a  b6644c957c2a3c7abec189d66305666ecb702f
9a60b893059f9b05b70d89519a3102f5be9bd9  cc9b9f36113f688209d4f4937a49b51bc76266
pi@raspberrypi:~/dev/timelapse$ ls -la .git/objects/a5/1a81f3a886a96db64ee8dcb36e3a369cd98f6a
-r--r--r-- 1 pi pi 0 Feb  7 22:10 .git/objects/a5/1a81f3a886a96db64ee8dcb36e3a369cd98f6a
pi@raspberrypi:~/dev/timelapse$
```

leighghunt, 2022-02-07:
Replaced git directory. Possibly shutting down too quickly?

Closed 2022-02-07.

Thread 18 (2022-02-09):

Camera troubleshooting

leighghunt, 2022-02-09:
Logs:

```
1 packets transmitted, 1 received, 0% packet loss, time 0ms                     
rtt min/avg/max/mdev = 55.381/55.381/55.381/0.000 ms                            
+++ date
++ echo Wed Feb 9 16:24:59 NZDT 2022
++ echo 'network interface either up or we gave up'                             
++ echo
++ date
++ /usr/bin/python3 coreScript.py
Traceback (most recent call last):
  File "_ctypes/callbacks.c", line 232, in 'calling callback function'          
  File "/home/pi/.local/lib/python3.7/site-packages/picamera/camera.py", line 129, in _control_callback
    "Received unexpected camera control callback event, 0x%08x" % buf[0].cmd)   
picamera.exc.PiCameraRuntimeError: Received unexpected camera control callback event, 0x4f525245
Traceback (most recent call last):
  File "_ctypes/callbacks.c", line 232, in 'calling callback function'          
  File "/home/pi/.local/lib/python3.7/site-packages/picamera/camera.py", line 129, in _control_callback
    "Received unexpected camera control callback event, 0x%08x" % buf[0].cmd)   
picamera.exc.PiCameraRuntimeError: Received unexpected camera control callback event, 0x4f525245
Shutdown scheduled for Wed 2022-02-09 16:27:10 NZDT, use 'shutdown -c' to cancel.
+++ date
++ echo Wed Feb 9 16:26:10 NZDT 2022
++ echo 'startup script finished'

```

leighghunt, 2022-04-08:
Sometimes seems to get hung up when battery goes flat, and only way to reset it was to disconnect battery and power.

Closed 2022-04-08.

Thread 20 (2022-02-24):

Pi didn't shut down

leighghunt, 2022-02-24:
Caused by Server returning 502?

`coreScript.py.out`:

```
Tue Feb 22 20:40:28 NZDT 2022
{'batteryPercent': 87, 'temperatureC': 30, 'diskSpaceFree': 50, 'uptimeSeconds': 26, 'status': "{'status': {'isFault': True, 'isButton': False, 'battery': 'NORMAL', 'powerInput': 'NOT_PRESENT', 'powerInput5vIo': 'NOT_PRESENT'}, 'batteryVoltage': 3912, 'batteryCurrent': 999, 'ioVoltage': 5013, 'ioCurrent': 628}", 'SerialNumber': '00000000f3c2ec94'}
<Response [200]>
2022-02-22 20:40:32.459953 Logged to API.
2022-02-22 20:40:32.470425 warming up... waiting 30s
2022-02-22 20:41:02.032217 Setting failsafe power off for 2 minutes from now.
{'batteryPercent': 86, 'temperatureC': 30, 'diskSpaceFree': 50, 'uptimeSeconds': 57, 'status': "{'status': {'isFault': True, 'isButton': False, 'battery': 'NORMAL', 'powerInput': 'NOT_PRESENT', 'powerInput5vIo': 'NOT_PRESENT'}, 'batteryVoltage': 3897, 'batteryCurrent': 1096, 'ioVoltage': 5015, 'ioCurrent': 1654}", 'SerialNumber': '00000000f3c2ec94'}
<Response [200]>
2022-02-22 20:41:07.772559 Logged to API.
2022-02-22 20:41:08.770940 beginning capture
2022-02-22 20:41:08.800173 warming up camera...
2022-02-22 20:41:13.805378 ready
2022-02-22 20:41:14.556806 image saved
data:
{'SerialNumber': '00000000f3c2ec94'}
Response code: 200
Response text:
{
    "id": 1714,
    "timestamp": "2022-02-22T07:41:20.5035049Z",
    "blobUri": "https://venaritimelapse.blob.core.windows.net/timelapse/1_2022-02-22_204113.jpg",
    "deviceId": 1,
    "device": {
        "id": 1,
        "serialNumber": "00000000f3c2ec94",
        "name": "Pi HQ 1",
        "description": "Raspberry Pi Zero W2 with HQ camera, 16mm lens"
    }
}
{'batteryPercent': 86, 'temperatureC': 30, 'diskSpaceFree': 50, 'uptimeSeconds': 76, 'status': "{'status': {'isFault': True, 'isButton': False, 'battery': 'NORMAL', 'powerInput': 'NOT_PRESENT', 'powerInput5vIo': 'NOT_PRESENT'}, 'batteryVoltage': 3898, 'batteryCurrent': 1088, 'ioVoltage': 5013, 'ioCurrent': 834}", 'SerialNumber': '00000000f3c2ec94'}
<Response [200]>
2022-02-22 20:41:26.658491 Logged to API.
2022-02-22 20:41:26.665001 scheduling shutdown
Alarm set for {'data': {'second': 0, 'minute_period': 10, 'hour': 'EVERY_HOUR', 'day': 'EVERY_DAY'}, 'error': 'NO_ERROR'}
2022-02-22 20:41:26.871232 Shutting down...
2022-02-22 20:41:26.922984 Power off scheduled for 30s from now

Tue Feb 22 20:50:23 NZDT 2022
                                                                                                                                                                                                                                                                                                                                                                                                                                                                                                                                                                                                                                                                                                                                                                                                                                                                                                                                                                                                                                                                                                                                                                                                                                                                                                                                                                                                                                                                                                                                                                                                                                                                                                                                                                                                                                                  
Tue Feb 22 21:00:22 NZDT 2022
                                                                                                                                                                                                                                                                                                                                                                                                                                                                                                                                                                                                                                                                                                                                                                                                                                                                                                                                                                                                                                                                                                                                                                                                                                                                                                                                                                                                                                                                                                                                                                                                                                                                                                                                                                                                                                                                                                                                                                                                                                                                                                                                                                                                                                                                                                                    
Wed Feb 23 07:00:24 NZDT 2022
{'batteryPercent': 80, 'temperatureC': 26, 'diskSpaceFree': 50, 'uptimeSeconds': 22, 'status': "{'status': {'isFault': True, 'isButton': False, 'battery': 'NORMAL', 'powerInput': 'NOT_PRESENT', 'powerInput5vIo': 'NOT_PRESENT'}, 'batteryVoltage': 3935, 'batteryCurrent': 626, 'ioVoltage': 5031, 'ioCurrent': 833}", 'SerialNumber': '00000000f3c2ec94'}
<Response [502]>
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
leighghunt, 2022-02-24:
Move telemetry upload until after failsafe shutdown.

Test with API down to verify behaviour.

Closed 2022-02-25.

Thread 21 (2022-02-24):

coreScript error following merge

leighghunt, 2022-02-24:
Testing with API server down to force error.

`startup.sh.out`:

```
~/dev/timelapse/scripts ~/dev/timelapse
++ tries=0
++ ping -c 1 -W 1 venari.co.nz
PING venari.co.nz (185.199.108.153) 56(84) bytes of data.
64 bytes from 185.199.108.153: icmp_seq=1 ttl=64 time=31.0 ms

--- venari.co.nz ping statistics ---
1 packets transmitted, 1 received, 0% packet loss, time 0ms
rtt min/avg/max/mdev = 31.023/31.023/31.023/0.000 ms
+++ date
++ echo Fri Feb 25 11:28:46 NZDT 2022
++ echo 'network interface either up or we gave up'
++ echo
++ date
++ /usr/bin/python3 coreScript.py
Traceback (most recent call last):
  File "coreScript.py", line 166, in <module>
    uploadTelemetry()
  File "coreScript.py", line 154, in uploadTelemetry
    assert postResponse.status_code == 200, "API returned error code"
AssertionError: API returned error code

During handling of the above exception, another exception occurred:

Traceback (most recent call last):
  File "coreScript.py", line 179, in <module>
    print(str(datetime.datetime.now()) + e)
TypeError: can only concatenate str (not "AssertionError") to str
+++ date
++ echo Fri Feb 25 11:28:54 NZDT 2022
++ echo 'startup script finished'
++ popd
~/dev/timelapse

```

`coreScipt.py.out`:

```
Fri Feb 25 11:28:46 NZDT 2022
{'batteryPercent': 29, 'temperatureC': 40, 'diskSpaceFree': 50, 'uptimeSeconds': 524, 'status': "{'status': {'isFault': True, 'isButton': False, 'battery': 'NORMAL', 'powerInput': 'BAD', 'powerInput5vIo': 'NOT_PRESENT'}, 'batteryVoltage': 3748, 'batteryCurrent': 875, 'ioVoltage': 5025, 'ioCurrent': 564}", 'SerialNumber': '00000000f3c2ec94'}
<Response [403]>
```

Closed 2022-02-25.

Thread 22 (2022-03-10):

Issues with images and telemetry not uploading

leighghunt, 2022-03-10:
Possibly caused by Vodafone account lapsing?

```
{'batteryPercent': 49, 'temperatureC': 44, 'diskSpaceFree': 50, 'uptimeSeconds': 5038, 'status': "{'status': {'isFault': False, 'isButton': False, 'battery': 'NORMAL', 'powerInput': 'NOT_PRESENT', 'powerInput5vIo': 'NOT_PRESENT'}, 'batteryVoltage': 3650, 'batteryCurrent': 378, 'ioVoltage': 5020, 'ioCurrent': 968}", 'SerialNumber': '00000000f3c2ec94'}
HTTPSConnectionPool(host='timelapse-dev.azurewebsites.net', port=443): Max retries exceeded with url: /api/Telemetry (Caused by SSLError(SSLError("bad handshake: SysCallError(110, 'ETIMEDOUT')")))
{'batteryPercent': 49, 'temperatureC': 44, 'diskSpaceFree': 50, 'uptimeSeconds': 5098, 'status': "{'status': {'isFault': False, 'isButton': False, 'battery': 'NORMAL', 'powerInput': 'NOT_PRESENT', 'powerInput5vIo': 'NOT_PRESENT'}, 'batteryVoltage': 3658, 'batteryCurrent': 388, 'ioVoltage': 5020, 'ioCurrent': 664}", 'SerialNumber': '00000000f3c2ec94'}
HTTPSConnectionPool(host='timelapse-dev.azurewebsites.net', port=443): Max retries exceeded with url: /api/Telemetry (Caused by SSLError(SSLError("bad handshake: SysCallError(110, 'ETIMEDOUT')")))
```

Topped up data and restarted Pi.

leighghunt, 2022-03-10:
Removed modem and is working again.

leighghunt, 2022-04-08:
Modem and/or data expiry seem to be the cause of this. 4GTLE modem seems worse than the Huawai one.

Closed 2022-04-08.

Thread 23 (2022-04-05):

Errors encountered running on Pi Zero W (1.1) without camera attached

leighghunt, 2022-04-05:
Need to fail more gracefully from this situation - ends up with pi powering off with failsafe after 2min30, and not being set to wake up.

```
pi@timelapse-pi-2:~/dev/timelapse/scripts$ python3 coreScript.py
hwclock: Cannot access the Hardware Clock via any known method.
hwclock: Use the --verbose option to see the details of our search for an access method.
2022-04-05 02:51:59.238670 Setting failsafe power off for 2 minutes 30 seconds from now.
{'batteryPercent': 15, 'temperatureC': 45, 'diskSpaceFree': 11, 'uptimeSeconds': 63, 'status': "{'status': {'isFault': False, 'isButton': False, 'battery': 'CHARGING_FROM_IN', 'powerInput': 'PRESENT', 'powerInput5vIo': 'NOT_PRESENT'}, 'batteryVoltage': 3953, 'batteryCurrent': -1134, 'ioVoltage': 5070, 'ioCurrent': 174}", 'SerialNumber': '00000000dcc1f9e4'}
<Response [200]>
2022-04-05 02:52:00.356392 Logged to API.
2022-04-05 02:52:00.377430 warming up... waiting 30s
{'batteryPercent': 16, 'temperatureC': 45, 'diskSpaceFree': 11, 'uptimeSeconds': 94, 'status': "{'status': {'isFault': False, 'isButton': False, 'battery': 'CHARGING_FROM_IN', 'powerInput': 'PRESENT', 'powerInput5vIo': 'NOT_PRESENT'}, 'batteryVoltage': 3951, 'batteryCurrent': -1119, 'ioVoltage': 5070, 'ioCurrent': 213}", 'SerialNumber': '00000000dcc1f9e4'}
<Response [200]>
2022-04-05 02:52:31.423089 Logged to API.
mmal: mmal_vc_component_create: failed to create component 'vc.ril.camera' (1:ENOMEM)
mmal: mmal_component_create_core: could not create component 'vc.ril.camera' (1)
Traceback (most recent call last):
  File "/home/pi/.local/lib/python3.7/site-packages/picamera/camera.py", line 456, in _init_camera
    self._camera = mo.MMALCamera()
  File "/home/pi/.local/lib/python3.7/site-packages/picamera/mmalobj.py", line 2279, in __init__
    super(MMALCamera, self).__init__()
  File "/home/pi/.local/lib/python3.7/site-packages/picamera/mmalobj.py", line 633, in __init__
    prefix="Failed to create MMAL component %s" % self.component_type)
  File "/home/pi/.local/lib/python3.7/site-packages/picamera/exc.py", line 184, in mmal_check
    raise PiCameraMMALError(status, prefix)
picamera.exc.PiCameraMMALError: Failed to create MMAL component b'vc.ril.camera': Out of memory

During handling of the above exception, another exception occurred:

Traceback (most recent call last):
  File "coreScript.py", line 185, in <module>
    savePhoto()
  File "coreScript.py", line 79, in savePhoto
    with PiCamera() as camera:
  File "/home/pi/.local/lib/python3.7/site-packages/picamera/camera.py", line 431, in __init__
    self._init_camera(camera_num, stereo_mode, stereo_decimate)
  File "/home/pi/.local/lib/python3.7/site-packages/picamera/camera.py", line 460, in _init_camera
    "Camera is not enabled. Try running 'sudo raspi-config' "
picamera.exc.PiCameraError: Camera is not enabled. Try running 'sudo raspi-config' and ensure that the camera has been enabled.

During handling of the above exception, another exception occurred:

Traceback (most recent call last):
  File "coreScript.py", line 190, in <module>
    print(str(datetime.datetime.now()) + e)
TypeError: can only concatenate str (not "PiCameraError") to str
1 pi@timelapse-pi-2:~/dev/timelapse/scripts$
```

leighghunt, 2022-04-05:
Note - even after enabling camera interface - but still having no camera connected, get the same error:

```
hwclock: Cannot access the Hardware Clock via any known method.
hwclock: Use the --verbose option to see the details of our search for an access method.
2022-04-05 03:04:50.030330 Setting failsafe power off for 2 minutes 30 seconds from now.
{'batteryPercent': 18, 'temperatureC': 47, 'diskSpaceFree': 11, 'uptimeSeconds': 137, 'status': "{'status': {'isFault': False, 'isButton': False, 'battery': 'CHARGING_FROM_IN', 'powerInput': 'PRESENT', 'powerInput5vIo': 'NOT_PRESENT'}, 'batteryVoltage': 3978, 'batteryCurrent': -1191, 'ioVoltage': 5070, 'ioCurrent': 201}", 'SerialNumber': '00000000dcc1f9e4'}
<Response [200]>
2022-04-05 03:04:50.866536 Logged to API.
2022-04-05 03:04:50.885609 warming up... waiting 30s
{'batteryPercent': 18, 'temperatureC': 48, 'diskSpaceFree': 11, 'uptimeSeconds': 167, 'status': "{'status': {'isFault': False, 'isButton': False, 'battery': 'CHARGING_FROM_IN', 'powerInput': 'PRESENT', 'powerInput5vIo': 'NOT_PRESENT'}, 'batteryVoltage': 3979, 'batteryCurrent': -1198, 'ioVoltage': 5081, 'ioCurrent': 168}", 'SerialNumber': '00000000dcc1f9e4'}
<Response [200]>
2022-04-05 03:05:21.743166 Logged to API.
mmal: mmal_vc_component_create: failed to create component 'vc.ril.camera' (1:ENOMEM)
mmal: mmal_component_create_core: could not create component 'vc.ril.camera' (1)
Traceback (most recent call last):
  File "/home/pi/.local/lib/python3.7/site-packages/picamera/camera.py", line 456, in _init_camera
    self._camera = mo.MMALCamera()
  File "/home/pi/.local/lib/python3.7/site-packages/picamera/mmalobj.py", line 2279, in __init__
    super(MMALCamera, self).__init__()
  File "/home/pi/.local/lib/python3.7/site-packages/picamera/mmalobj.py", line 633, in __init__
    prefix="Failed to create MMAL component %s" % self.component_type)
  File "/home/pi/.local/lib/python3.7/site-packages/picamera/exc.py", line 184, in mmal_check
    raise PiCameraMMALError(status, prefix)
picamera.exc.PiCameraMMALError: Failed to create MMAL component b'vc.ril.camera': Out of memory

During handling of the above exception, another exception occurred:

Traceback (most recent call last):
  File "coreScript.py", line 185, in <module>
    savePhoto()
  File "coreScript.py", line 79, in savePhoto
    with PiCamera() as camera:
  File "/home/pi/.local/lib/python3.7/site-packages/picamera/camera.py", line 431, in __init__
    self._init_camera(camera_num, stereo_mode, stereo_decimate)
  File "/home/pi/.local/lib/python3.7/site-packages/picamera/camera.py", line 460, in _init_camera
    "Camera is not enabled. Try running 'sudo raspi-config' "
picamera.exc.PiCameraError: Camera is not enabled. Try running 'sudo raspi-config' and ensure that the camera has been enabled.

During handling of the above exception, another exception occurred:

Traceback (most recent call last):
  File "coreScript.py", line 190, in <module>
    print(str(datetime.datetime.now()) + e)
TypeError: can only concatenate str (not "PiCameraError") to str
```

leighghunt, 2022-04-05:
After - getting the following - shutdown scheduled - but perhaps wrong timezone?

```
hwclock: Cannot access the Hardware Clock via any known method.
hwclock: Use the --verbose option to see the details of our search for an access method.
2022-04-05 03:07:16.802291 Setting failsafe power off for 2 minutes 30 seconds from now.
{'batteryPercent': 18, 'temperatureC': 48, 'diskSpaceFree': 11, 'uptimeSeconds': 283, 'status': "{'status': {'isFault': False, 'isButton': False, 'battery': 'CHARGING_FROM_IN', 'powerInput': 'PRESENT', 'powerInput5vIo': 'NOT_PRESENT'}, 'batteryVoltage': 3981, 'batteryCurrent': -1191, 'ioVoltage': 5070, 'ioCurrent': 227}", 'SerialNumber': '00000000dcc1f9e4'}
<Response [200]>
2022-04-05 03:07:17.576912 Logged to API.
2022-04-05 03:07:17.597217 warming up... waiting 30s
{'batteryPercent': 19, 'temperatureC': 48, 'diskSpaceFree': 11, 'uptimeSeconds': 314, 'status': "{'status': {'isFault': False, 'isButton': False, 'battery': 'CHARGING_FROM_IN', 'powerInput': 'PRESENT', 'powerInput5vIo': 'NOT_PRESENT'}, 'batteryVoltage': 3982, 'batteryCurrent': -1198, 'ioVoltage': 5082, 'ioCurrent': 109}", 'SerialNumber': '00000000dcc1f9e4'}
<Response [200]>
2022-04-05 03:07:48.346559 Logged to API.
mmal: mmal_vc_component_create: failed to create component 'vc.ril.camera' (1:ENOMEM)
mmal: mmal_component_create_core: could not create component 'vc.ril.camera' (1)
2022-04-05 03:07:48.469855Catastrophic failure
2022-04-05 03:07:48.473644 scheduling shutdown
Alarm set for {'data': {'second': 0, 'minute_period': 10, 'hour': 18, 'day': 'EVERY_DAY'}, 'error': 'NO_ERROR'}
2022-04-05 03:07:48.691718 Shutting down...

Broadcast message from root@timelapse-pi-2 on pts/1 (Tue 2022-04-05 03:07:48 BST):
```

Fixed in 0606f5f, and changing timezone.
```
sudo timedatectl set-timezone Pacific/Auckland
```

leighghunt, 2022-04-06:
Actually still seems to be having probs, and looks like it's not managed to update the wakeup alarm, so is carrying on waking up every 10 minutes.

UploadTelemetry log:

```
Wed  6 Apr 21:45:01 NZST 2022
A
67
35
11
279
{'status': {'isFault': False, 'isButton': False, 'battery': 'NORMAL', 'powerInput': 'NOT_PRESENT', 'powerInput5vIo': 'NOT_PRESENT'}, 'batteryVoltage': 3921, 'batteryCurrent': 402, 'ioVoltage': 5072, 'ioCurrent': 150}
00000000dcc1f9e4
Z
{'batteryPercent': 67, 'temperatureC': 35, 'diskSpaceFree': 11, 'uptimeSeconds': 279, 'status': "{'status': {'isFault': False, 'isButton': False, 'battery': 'NORMAL', 'powerInput': 'NOT_PRESENT', 'powerInput5vIo': 'NOT_PRESENT'}, 'batteryVoltage': 3921, 'batteryCurrent': 402, 'ioVoltage': 5067, 'ioCurrent': 187}", 'SerialNumber': '00000000dcc1f9e4'}
<Response [200]>
2022-04-06 21:45:04.995990 Logged to API.

Wed  6 Apr 21:46:01 NZST 2022
A
'data'

Wed  6 Apr 21:47:02 NZST 2022
A
'data'

Wed  6 Apr 21:48:01 NZST 2022
A
'data'

Wed  6 Apr 21:49:01 NZST 2022
A
'data'

Wed  6 Apr 21:51:29 NZST 2022
A
67
36
11
67
{'status': {'isFault': False, 'isButton': False, 'battery': 'NORMAL', 'powerInput': 'NOT_PRESENT', 'powerInput5vIo': 'NOT_PRESENT'}, 'batteryVoltage': 3913, 'batteryCurrent': 454, 'ioVoltage': 5067, 'ioCurrent': 191}
00000000dcc1f9e4
Z
{'batteryPercent': 67, 'temperatureC': 36, 'diskSpaceFree': 11, 'uptimeSeconds': 67, 'status': "{'status': {'isFault': False, 'isButton': False, 'battery': 'NORMAL', 'powerInput': 'NOT_PRESENT', 'powerInput5vIo': 'NOT_PRESENT'}, 'batteryVoltage': 3913, 'batteryCurrent': 454, 'ioVoltage': 5062, 'ioCurrent': 191}", 'SerialNumber': '00000000dcc1f9e4'}
<Response [200]>
2022-04-06 21:51:33.280898 Logged to API.

Wed  6 Apr 21:51:33 NZST 2022
A
67
35
11
71
{'status': {'isFault': False, 'isButton': False, 'battery': 'NORMAL', 'powerInput': 'NOT_PRESENT', 'powerInput5vIo': 'NOT_PRESENT'}, 'batteryVoltage': 3916, 'batteryCurrent': 432, 'ioVoltage': 5067, 'ioCurrent': 236}
00000000dcc1f9e4
Z
{'batteryPercent': 67, 'temperatureC': 35, 'diskSpaceFree': 11, 'uptimeSeconds': 71, 'status': "{'status': {'isFault': False, 'isButton': False, 'battery': 'NORMAL', 'powerInput': 'NOT_PRESENT', 'powerInput5vIo': 'NOT_PRESENT'}, 'batteryVoltage': 3916, 'batteryCurrent': 432, 'ioVoltage': 5067, 'ioCurrent': 236}", 'SerialNumber': '00000000dcc1f9e4'}
<Response [200]>
2022-04-06 21:51:36.806380 Logged to API.

Wed  6 Apr 21:52:01 NZST 2022
A
'data'

Wed  6 Apr 21:53:01 NZST 2022
A
'data'

Wed  6 Apr 21:54:01 NZST 2022
A
'data'

Wed  6 Apr 21:55:02 NZST 2022
A
'data'
```

coreScipt log:
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
leighghunt, 2022-04-07:
`Cannot set alarm`, and other communication issues with this Pi/PiJuice combination.

```
pi@timelapse-pi-2:~$ python3
Python 3.7.3 (default, Jan 22 2021, 20:04:44)
[GCC 8.3.0] on linux
Type "help", "copyright", "credits" or "license" for more information.
>>> import pijuice
^[[Apj = pijuice.PiJuice(1, 0x14)
>>> print (pj.status.GetChargeLevel())
{'error': 'COMMUNICATION_ERROR'}
>>> print (pj.status.GetChargeLevel()['data'])
76
```

leighghunt, 2022-04-07:
Possibly linked issue to investigate: https://github.com/PiSupply/PiJuice/issues/610

leighghunt, 2022-04-07:
Also possibly relevant: https://github.com/raspberrypi/linux/issues/3064

leighghunt, 2022-04-07:
Think it might have been resolved by updating the ubuntu install.

```
sudo apt-get update
sudo apt-get upgrade
```

Closed 2022-04-07.

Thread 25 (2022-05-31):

balena push fails - Unable to locate package pijuice-base

leighghunt, 2022-05-31:
```
➜  timelapse git:(feature/balena) ✗ balena push gh_leighghunt/timelapse_zero2
--------------------------------------------------------------------------------
[Warn] Node.js version "14.19.3" does not satisfy requirement ">=12.8.0 <13.0.0"
[Warn] This may cause unexpected behavior.
--------------------------------------------------------------------------------
[Info]          Starting build for timelapse_zero2, user gh_leighghunt
[Info]          Dashboard link: https://dashboard.balena-cloud.com/apps/1887284/devices
[Info]          Building on arm05
[Info]          Pulling previous images for caching purposes...
[Success]       Successfully pulled cache images
[sample]        Step 1/4 : FROM balenalib/raspberrypi0-2w-64-python:3-stretch-run
[sample]        manifest for balenalib/raspberrypi0-2w-64-python:3-stretch-run not found: manifest unknown: manifest unknown
[pijuice]       Step 1/8 : FROM balenalib/raspberrypi0-2w-64-python:3-stretch-build
[pijuice]       manifest for balenalib/raspberrypi0-2w-64-python:3-stretch-build not found: manifest unknown: manifest unknown
[Info]          Uploading images
[Success]       Successfully uploaded images
[Error]         Some services failed to build:
[Error]           Service: pijuice
[Error]             Error: manifest for balenalib/raspberrypi0-2w-64-python:3-stretch-build not found: manifest unknown: manifest unknown
[Error]           Service: sample
[Error]             Error: manifest for balenalib/raspberrypi0-2w-64-python:3-stretch-run not found: manifest unknown: manifest unknown
[Info]          Built on arm05
[Error]         Not deploying release.
Remote build failed

➜  timelapse git:(feature/balena) ✗ balena push gh_leighghunt/timelapse_zero2
--------------------------------------------------------------------------------
[Warn] Node.js version "14.19.3" does not satisfy requirement ">=12.8.0 <13.0.0"
[Warn] This may cause unexpected behavior.
--------------------------------------------------------------------------------
[Info]          Starting build for timelapse_zero2, user gh_leighghunt
[Info]          Dashboard link: https://dashboard.balena-cloud.com/apps/1887284/devices
[Info]          Building on arm04
[Info]          Pulling previous images for caching purposes...
[Success]       Successfully pulled cache images
[pijuice]       Step 1/8 : FROM balenalib/aarch64-python:3-stretch-build
[sample]        Step 1/4 : FROM balenalib/aarch64-python:3-stretch-run
[sample]         ---> 3f4674791325
[sample]        Step 2/4 : WORKDIR /usr/src/app
[sample]         ---> Running in 048b0f52bb16
[sample]        Removing intermediate container 048b0f52bb16
[sample]         ---> e3e3e49ceef1
[sample]        Step 3/4 : COPY . ./
[sample]         ---> 44359d013a90
[sample]        Step 4/4 : CMD ["python","-u","src/main.py"]
[sample]         ---> Running in b53905ed844f
[sample]        Removing intermediate container b53905ed844f
[sample]         ---> 82e3f2d30d30
[sample]        Successfully built 82e3f2d30d30
[Info]          Still Working...
[pijuice]        ---> 2592ad5430c4
[pijuice]       Step 2/8 : RUN install_packages pijuice-base jq curl
[pijuice]        ---> Running in ec96f0058c72
[pijuice]       Here are a few details about this Docker image (For more information please visit https://www.balena.io/docs/reference/base-images/base-images/):
[pijuice]       Architecture: ARM v8
[pijuice]       OS: Debian Stretch
[pijuice]       Variant: build variant
[pijuice]       Default variable(s): UDEV=off
[pijuice]       The following software stack is preinstalled:
[pijuice]       Python v3.6.14, Pip v21.2.3, Setuptools v57.4.0
[pijuice]       Extra features:
[pijuice]       - Easy way to install packages with `install_packages <package-name>` command
[pijuice]       - Run anywhere with cross-build feature  (for ARM only)
[pijuice]       - Keep the container idling with `balena-idle` command
[pijuice]       - Show base image details with `balena-info` command
[pijuice]       Reading package lists...
[pijuice]       Building dependency tree...
[pijuice]       Reading state information...
[pijuice]       E: Unable to locate package pijuice-base
[pijuice]
[pijuice]       apt failed, retrying
[pijuice]       Reading package lists...
[pijuice]       Building dependency tree...
[pijuice]       Reading state information...
[pijuice]       E: Unable to locate package pijuice-base
[pijuice]
[pijuice]       apt failed, retrying
[pijuice]       Reading package lists...
[pijuice]       Building dependency tree...
[pijuice]       Reading state information...
[pijuice]       E: Unable to locate package pijuice-base
[pijuice]
[pijuice]       Removing intermediate container ec96f0058c72
[pijuice]       The command '/bin/sh -c install_packages pijuice-base jq curl' returned a non-zero code: 100
[Info]          Uploading images
[Success]       Successfully uploaded images
[Error]         Some services failed to build:
[Error]           Service: pijuice
[Error]             Error: The command '/bin/sh -c install_packages pijuice-base jq curl' returned a non-zero code: 100
[Info]          Built on arm04
[Error]         Not deploying release.
Remote build failed
```

leighghunt, 2022-05-31:
Attempting to build the freshly cloned https://github.com/balenalabs-incubator/balena-pijuice repo for a RPI:

*ERROR: Failed building wheel for cryptography* (similar/same issue here: https://forums.balena.io/t/how-to-push-pijuice-to-balenaos/39402/9)

Seems to resolve to balenalib/raspberry-pi-python:3-stretch-build, which ends up being
```
Get:1 http://archive.raspberrypi.org/debian stretch/main armhf pijuice-base all 1.7 [104 kB]
```

```
➜  balena-pijuice git:(master) balena push gh_leighghunt/timelapse_zero
--------------------------------------------------------------------------------
[Warn] Node.js version "14.19.3" does not satisfy requirement ">=12.8.0 <13.0.0"
[Warn] This may cause unexpected behavior.
--------------------------------------------------------------------------------
[Info]     Starting build for timelapse_zero, user gh_leighghunt
[Info]     Dashboard link: https://dashboard.balena-cloud.com/apps/1922558/devices
[Info]     Building on arm04
[Info]     No suitable previous release for caching, skipping cache pull
[pijuice]  Step 1/8 : FROM balenalib/raspberry-pi-python:3-stretch-build
[sample]   Step 1/4 : FROM balenalib/raspberry-pi-python:3-stretch-run
[sample]    ---> 00420fb732cc
[sample]   Step 2/4 : WORKDIR /usr/src/app
[sample]    ---> Running in 760884f7f8bc
[sample]   Removing intermediate container 760884f7f8bc
[sample]    ---> 07f8224e70b3
[sample]   Step 3/4 : COPY . ./
[sample]    ---> f8128e18f3b9
[sample]   Step 4/4 : CMD ["python","-u","src/main.py"]
[sample]    ---> Running in 097d25d19b27
[sample]   Removing intermediate container 097d25d19b27
[sample]    ---> 644546424eb8
[sample]   Successfully built 644546424eb8
[pijuice]   ---> 84a99ff123d7
[pijuice]  Step 2/8 : RUN install_packages pijuice-base jq curl
[pijuice]   ---> Running in e7bde11956cc
[pijuice]  Here are a few details about this Docker image (For more information please visit https://www.balena.io/docs/reference/base-images/base-images/):
[pijuice]  Architecture: ARM v6
[pijuice]  OS: Debian Stretch
[pijuice]  Variant: build variant
[pijuice]  Default variable(s): UDEV=off
[pijuice]  The following software stack is preinstalled:
[pijuice]  Python v3.6.14, Pip v21.2.3, Setuptools v57.4.0
[pijuice]  Extra features:
[pijuice]  - Easy way to install packages with `install_packages <package-name>` command
[pijuice]  - Run anywhere with cross-build feature  (for ARM only)
[pijuice]  - Keep the container idling with `balena-idle` command
[pijuice]  - Show base image details with `balena-info` command
[pijuice]  Reading package lists...
[pijuice]  Building dependency tree...
[pijuice]  Reading state information...
[pijuice]  The following additional packages will be installed:
[pijuice]    libcurl3 libcurl4-openssl-dev libjq1 libonig4 python3-smbus python3-urwid
[pijuice]  Suggested packages:
[pijuice]    libcurl4-doc libcurl3-dbg libidn11-dev libkrb5-dev libldap2-dev librtmp-dev
[pijuice]    libssh2-1-dev libssl1.0-dev | libssl-dev
[pijuice]  The following NEW packages will be installed:
[pijuice]    jq libjq1 libonig4 pijuice-base python3-smbus python3-urwid
[pijuice]  The following packages will be upgraded:
[pijuice]    curl libcurl3 libcurl4-openssl-dev
[pijuice]  3 upgraded, 6 newly installed, 0 to remove and 59 not upgraded.
[pijuice]  Need to get 1411 kB of archives.
[pijuice]  After this operation, 2285 kB of additional disk space will be used.
[pijuice]  Get:1 http://archive.raspberrypi.org/debian stretch/main armhf pijuice-base all 1.7 [104 kB]
[pijuice]  Get:2 http://archive.raspbian.org/raspbian stretch/main armhf libcurl4-openssl-dev armhf 7.52.1-5+deb9u16 [334 kB]
[pijuice]  Get:3 http://archive.raspbian.org/raspbian stretch/main armhf curl armhf 7.52.1-5+deb9u16 [221 kB]
[pijuice]  Get:4 http://archive.raspbian.org/raspbian stretch/main armhf libcurl3 armhf 7.52.1-5+deb9u16 [267 kB]
[pijuice]  Get:5 http://archive.raspbian.org/raspbian stretch/main armhf libonig4 armhf 6.1.3-2+deb9u2 [128 kB]
[pijuice]  Get:6 http://archive.raspbian.org/raspbian stretch/main armhf libjq1 armhf 1.5+dfsg-1.3 [119 kB]
[pijuice]  Get:7 http://archive.raspbian.org/raspbian stretch/main armhf jq armhf 1.5+dfsg-1.3 [58.9 kB]
[pijuice]  Get:8 http://archive.raspbian.org/raspbian stretch/main armhf python3-smbus armhf 3.1.2-3 [9774 B]
[pijuice]  Get:9 http://archive.raspbian.org/raspbian stretch/main armhf python3-urwid armhf 1.3.1-2 [169 kB]
[pijuice]  debconf: delaying package configuration, since apt-utils is not installed
[pijuice]
[pijuice]  Fetched 1411 kB in 0s (1995 kB/s)
[pijuice]  (Reading database ...
(Reading database ... 10%ase ... 5%
(Reading database ... 20%ase ... 15%
(Reading database ... 50%ase ... 25%
(Reading database ... 65%ase ... 55%
[pijuice]  (Reading database ... 70%
[pijuice]  (Reading database ... 75%
[pijuice]  (Reading database ... 80%
[pijuice]  (Reading database ... 85%
[pijuice]  (Reading database ... 90%
[pijuice]  (Reading database ... 95%
(Reading database ... 19974 files and directories currently installed.)
[pijuice]  Preparing to unpack .../0-libcurl4-openssl-dev_7.52.1-5+deb9u16_armhf.deb ...
[pijuice]  Unpacking libcurl4-openssl-dev:armhf (7.52.1-5+deb9u16) over (7.52.1-5+deb9u15) ...
[pijuice]  Preparing to unpack .../1-curl_7.52.1-5+deb9u16_armhf.deb ...
[pijuice]  Unpacking curl (7.52.1-5+deb9u16) over (7.52.1-5+deb9u15) ...
[pijuice]  Preparing to unpack .../2-libcurl3_7.52.1-5+deb9u16_armhf.deb ...
[pijuice]  Unpacking libcurl3:armhf (7.52.1-5+deb9u16) over (7.52.1-5+deb9u15) ...
[pijuice]  Selecting previously unselected package libonig4:armhf.
[pijuice]  Preparing to unpack .../3-libonig4_6.1.3-2+deb9u2_armhf.deb ...
[pijuice]  Unpacking libonig4:armhf (6.1.3-2+deb9u2) ...
[pijuice]  Selecting previously unselected package libjq1:armhf.
[pijuice]  Preparing to unpack .../4-libjq1_1.5+dfsg-1.3_armhf.deb ...
[pijuice]  Unpacking libjq1:armhf (1.5+dfsg-1.3) ...
[pijuice]  Selecting previously unselected package jq.
[pijuice]  Preparing to unpack .../5-jq_1.5+dfsg-1.3_armhf.deb ...
[pijuice]  Unpacking jq (1.5+dfsg-1.3) ...
[pijuice]  Selecting previously unselected package python3-smbus:armhf.
[pijuice]  Preparing to unpack .../6-python3-smbus_3.1.2-3_armhf.deb ...
[pijuice]  Unpacking python3-smbus:armhf (3.1.2-3) ...
[pijuice]  Selecting previously unselected package python3-urwid.
[pijuice]  Preparing to unpack .../7-python3-urwid_1.3.1-2_armhf.deb ...
[pijuice]  Unpacking python3-urwid (1.3.1-2) ...
[pijuice]  Selecting previously unselected package pijuice-base.
[pijuice]  Preparing to unpack .../8-pijuice-base_1.7_all.deb ...
[pijuice]  Unpacking pijuice-base (1.7) ...
[pijuice]  Setting up libcurl3:armhf (7.52.1-5+deb9u16) ...
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

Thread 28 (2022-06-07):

Balena power usage issues

leighghunt, 2022-06-07:
Balena seems to use a bit more power (maybe 10+%) than native python scripts.

Check to see if moving to docker and Apache Guacamole addresses this.
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

leighghunt, 2023-03-24:
Closing as no longer using Balena

Closed 2023-03-24.

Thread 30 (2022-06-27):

Setup SSH reverse tunnel

leighghunt, 2022-06-27:

leighghunt, 2022-09-28:
Using tailscale for now - seems to work well, albeit limited to 20 devices - but also looks like it's free for open source projects.

Closed 2022-09-28.

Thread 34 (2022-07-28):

Pending telemetry not getting uploaded

leighghunt, 2022-07-28:
Noticed that old telemetry ism't getting uploaded.

```
2022-07-28 22:22:56,430 ERROR: 2022-07-28 22:22:56.430234 uploadPendingTelemetry() failed.
2022-07-28 22:22:56,431 ERROR: Expecting value: line 1 column 1 (char 0)
```

```logs/timelapse.log```:
```
2022-07-28 22:22:56,426 INFO:  uploading 2022-07-10_040055.json
2022-07-28 22:22:56,427 DEBUG: telemetryTimestamp:
2022-07-28 22:22:56,427 DEBUG: 2022-07-10 04:00:55
2022-07-28 22:22:56,430 ERROR: 2022-07-28 22:22:56.430234 uploadPendingTelemetry() failed.
2022-07-28 22:22:56,431 ERROR: Expecting value: line 1 column 1 (char 0)
2022-07-28 22:22:56,432 INFO:  uploading 2022-07-28_222252.jpg
2022-07-28 22:22:56,438 DEBUG: imageTimestamp:
2022-07-28 22:22:56,438 DEBUG: 2022-07-28 22:22:52
2022-07-28 22:22:56,439 DEBUG: data:
2022-07-28 22:22:56,440 DEBUG: {'SerialNumber': '00000000638a42a2', 'Timestamp': '2022-07-28T22:22:52+12:00'}
2022-07-28 22:22:56,440 DEBUG: Posting image to API...
2022-07-28 22:22:56,458 DEBUG: Starting new HTTPS connection (1): timelapse-dev.azurewebsites.net:443
2022-07-28 22:22:57,333 DEBUG: https://timelapse-dev.azurewebsites.net:443 "POST /api/Image HTTP/1.1" 200 None
2022-07-28 22:22:57,338 DEBUG: Response code: 200
2022-07-28 22:22:57,338 DEBUG: Image uploaded successfully
2022-07-28 22:22:57,339 DEBUG: Response text:
2022-07-28 22:22:57,340 DEBUG: {
    "id": 111152,
    "timestamp": "2022-07-28T10:22:52Z",
    "blobUri": "https://venaritimelapse.blob.core.windows.net/timelapse/11_2022-07-28_222252.jpg",
    "deviceId": 11,
    "device": {
        "id": 11,
        "serialNumber": "00000000638a42a2",
        "name": "Pi Zero W 2 number 3",
        "description": "3rd camera"
    }
}
2022-07-28 22:23:07,447 INFO:  uploading 2022-07-10_040055.json
2022-07-28 22:23:07,449 DEBUG: telemetryTimestamp:
2022-07-28 22:23:07,450 DEBUG: 2022-07-10 04:00:55
2022-07-28 22:23:07,454 ERROR: 2022-07-28 22:23:07.454565 uploadPendingTelemetry() failed.
2022-07-28 22:23:07,455 ERROR: Expecting value: line 1 column 1 (char 0)
2022-07-28 22:23:17,546 INFO:  uploading 2022-07-10_040055.json
2022-07-28 22:23:17,548 DEBUG: telemetryTimestamp:
2022-07-28 22:23:17,548 DEBUG: 2022-07-10 04:00:55
2022-07-28 22:23:17,551 ERROR: 2022-07-28 22:23:17.551433 uploadPendingTelemetry() failed.
2022-07-28 22:23:17,552 ERROR: Expecting value: line 1 column 1 (char 0)
2022-07-28 22:23:23,180 DEBUG: beginning capture
2022-07-28 22:23:23,227 DEBUG: warming up camera...
```

ethandhunt, 2022-08-02:
traceback.print_exc() at the end of the uploadPendingTelemetry returns
```
Traceback (most recent call last):                                                                                 
  File "uploadPending.py", line 109, in uploadPendingTelemetry                                                     
    api_data = json.load(open(pendingTelemetryFolder + telemetryFilename, 'rb'))                                                       
  File "/usr/lib/python3.7/json/__init__.py", line 296, in load                                                    
    parse_constant=parse_constant, object_pairs_hook=object_pairs_hook, **kw)                                      
  File "/usr/lib/python3.7/json/__init__.py", line 348, in loads                                                   
    return _default_decoder.decode(s)                                                                              
  File "/usr/lib/python3.7/json/decoder.py", line 337, in decode                                                   
    obj, end = self.raw_decode(s, idx=_w(s, 0).end())                                                              
  File "/usr/lib/python3.7/json/decoder.py", line 355, in raw_decode                                               
    raise JSONDecodeError("Expecting value", s, err.value) from None                                               
json.decoder.JSONDecodeError: Expecting value: line 1 column 1 (char 0)
```

ethandhunt, 2022-08-02:
`pendingTelemetryFolder + telemetryFilename` evaluates to `../output/telemetry/pending/2022-07-10_040055.json`

ethandhunt, 2022-08-02:
```
$ file 2022-07-10_040055.json                                                                                                  
2022-07-10_040055.json: empty
```

ethandhunt, 2022-08-02:
it seems like the file is empty and that's making the script throw a json decoding error
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
ethandhunt, 2022-08-02:
the pi could be running out of power while writing to files, this would explain the null bytes

ethandhunt, 2022-08-02:
looks like that's hat's happening
```
2022-07-02 08:00:56,297 DEBUG: {'batteryPercent': 2
```

ethandhunt, 2022-08-02:
looks like skipping empty files has worked

ethandhunt, 2022-08-02:
files that were empty:
```
$ file *
2022-07-02_080200.json: empty
2022-07-04_000054.json: empty
2022-07-04_080052.json: empty
2022-07-05_030054.json: empty
2022-07-05_050117.json: empty
2022-07-05_070105.json: empty
2022-07-05_143027.json: empty
2022-07-06_210054.json: empty
2022-07-06_220053.json: empty
2022-07-07_030058.json: empty
2022-07-07_070054.json: empty
2022-07-07_180104.json: empty
2022-07-07_190101.json: empty
2022-07-07_200054.json: empty
2022-07-07_230059.json: empty
2022-07-08_115021.json: empty
2022-07-09_180019.json: empty
2022-07-09_190100.json: empty
2022-07-09_200115.json: empty
2022-07-09_210054.json: empty
2022-07-10_010054.json: empty
2022-07-10_030101.json: empty
2022-07-10_040055.json: empty
2022-07-10_115654.json: empty
2022-07-10_180018.json: empty
2022-07-10_190111.json: empty
2022-07-10_210053.json: empty
2022-07-10_220052.json: empty
2022-07-10_230058.json: empty
2022-07-11_010105.json: empty
2022-07-11_020052.json: empty
2022-07-11_030054.json: empty
2022-07-11_050054.json: empty
2022-07-11_060053.json: empty
2022-07-11_111732.json: empty
2022-07-13_190105.json: empty
2022-07-13_200054.json: empty
2022-07-13_210054.json: empty
2022-07-13_220053.json: empty
2022-07-14_010053.json: empty
2022-07-14_020056.json: empty
2022-07-14_040054.json: empty
2022-07-14_070105.json: empty
2022-07-14_180011.json: empty
2022-07-14_220052.json: empty
2022-07-14_230054.json: empty
2022-07-15_010055.json: empty
2022-07-15_020052.json: empty
2022-07-15_030054.json: empty
2022-07-15_040104.json: empty
2022-07-15_050054.json: empty
2022-07-15_060054.json: empty
2022-07-15_140243.json: empty
2022-07-15_180021.json: empty
2022-07-15_190113.json: empty
2022-07-15_230054.json: empty
2022-07-16_000054.json: empty
2022-07-16_040053.json: empty
2022-07-16_060054.json: empty
2022-07-16_133853.json: empty
2022-07-16_180020.json: empty
2022-07-16_200054.json: empty
2022-07-16_210054.json: empty
2022-07-17_010054.json: empty
2022-07-17_020101.json: empty
2022-07-17_030054.json: empty
2022-07-17_040054.json: empty
2022-07-17_180011.json: empty
2022-07-17_190112.json: empty
2022-07-17_200052.json: empty
2022-07-17_210053.json: empty
2022-07-17_230054.json: empty
2022-07-18_000102.json: empty
2022-07-18_010053.json: empty
2022-07-18_050054.json: empty
2022-07-18_190105.json: empty
2022-07-18_210054.json: empty
2022-07-18_220055.json: empty
2022-07-19_030053.json: empty
2022-07-19_040053.json: empty
2022-07-19_060059.json: empty
2022-07-19_070054.json: empty
2022-07-20_180009.json: empty
2022-07-20_200059.json: empty
2022-07-21_000058.json: empty
2022-07-21_010054.json: empty
2022-07-21_030053.json: empty
2022-07-21_060057.json: empty
2022-07-21_070100.json: empty
2022-07-21_180022.json: empty
2022-07-21_190112.json: empty
2022-07-21_200053.json: empty
2022-07-21_220053.json: empty
2022-07-22_040054.json: empty
2022-07-22_114217.json: empty
2022-07-23_210054.json: empty
2022-07-23_220054.json: empty
2022-07-24_020053.json: empty
2022-07-24_030059.json: empty
2022-07-24_040100.json: empty
2022-07-24_060053.json: empty
2022-07-24_175105.json: empty
2022-07-24_180033.json: empty
2022-07-24_190107.json: empty
2022-07-24_200101.json: empty
2022-07-25_220058.json: empty
2022-07-25_230054.json: empty
2022-07-26_010052.json: empty
2022-07-26_040054.json: empty
2022-07-26_060054.json: empty
2022-07-28_222252.json: empty
2022-07-28_230053.json: empty
2022-07-29_050119.json: empty
2022-07-29_060116.json: empty
2022-07-29_070053.json: empty
2022-07-29_083236.json: empty
```

Closed 2022-09-28.

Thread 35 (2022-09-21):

Get arducam cameras working

leighghunt, 2022-09-21:
I started work here but didn't get it working: https://github.com/venari/timelapse/tree/feature/arducam

leighghunt, 2023-03-24:
No longer doing as using Pi camera module 3

Closed 2023-03-24.

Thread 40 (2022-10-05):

Wakeup issue when no internet

leighghunt, 2022-10-05:
Looks like RTC clock is being overwritten incorrectly if waking up with no network.

Means it continues to think it's the middle of the night, so keeps on waking up every hour

leighghunt, 2022-10-06:
Normal operation:

```

2022-10-03 20:02:31,798 DEBUG: scheduleShutdown
2022-10-03 20:02:31,799 INFO: Night time so we're scheduling shutdown
2022-10-03 20:02:31,799 INFO: scheduleShutdown - we're setting the shutdown...
2022-10-03 20:02:32,009 DEBUG: Alarm set for {'data': {'second': 0, 'minute': 0, 'hour': 'EVERY_HOUR', 'day': 'EVERY_DAY'}, 'error': 'NO_ERROR'}
2022-10-03 20:02:32,014 DEBUG: Alarm set for {'data': {'second': 0, 'minute': 0, 'hour': 'EVERY_HOUR', 'day': 'EVERY_DAY'}, 'error': 'NO_ERROR'}
2022-10-03 20:02:32,015 INFO: Shutting down...
2022-10-03 20:02:32,089 INFO: Power off scheduled for 30s from now
2022-10-03 20:02:35,449 INFO:  uploading ../output/telemetry/pending/2022-10-03_200231.json
2022-10-03 20:02:35,472 DEBUG: telemetryTimestamp:
2022-10-03 20:02:35,472 DEBUG: 2022-10-03 20:02:31
2022-10-03 20:02:35,473 DEBUG: {'batteryPercent': 97, 'temperatureC': 33, 'diskSpaceFree': 105, 'uptimeSeconds': 53, 'status': "{'status': {'isFault': False, 'isButton': False, 'battery': 'CHARGING_FROM_IN', 'powerInput': 'PRESENT', 'powerInput5vIo': 'NOT_PRESENT'}, 'batteryVoltage': 4147, 'batteryCurrent': -1857, 'ioVoltage': 5035, 'ioCurrent': 889}", 'SerialNumber': '00000000638a42a2', 'Timestamp': '2022-10-03T20:02:31+13:00'}
2022-10-03 20:02:35,485 DEBUG: Starting new HTTPS connection (1): timelapse-dev.azurewebsites.net:443
2022-10-03 20:02:36,706 DEBUG: https://timelapse-dev.azurewebsites.net:443 "POST /api/Telemetry HTTP/1.1" 200 None
2022-10-03 20:02:36,714 DEBUG: <Response [200]>
2022-10-03 20:02:36,714 DEBUG: Telemetry uploaded successfully
2022-10-03 20:02:36,715 DEBUG: Logged to API.
2022-10-03 20:02:36,729 INFO:  uploading ../output/images/pending/2022-10-03_200231.jpg
2022-10-03 20:02:36,731 DEBUG: imageTimestamp:
2022-10-03 20:02:36,731 DEBUG: 2022-10-03 20:02:31
2022-10-03 20:02:36,732 DEBUG: data:
2022-10-03 20:02:36,732 DEBUG: {'SerialNumber': '00000000638a42a2', 'Timestamp': '2022-10-03T20:02:31+13:00'}
2022-10-03 20:02:36,733 DEBUG: Posting image to API...
2022-10-03 20:02:36,768 DEBUG: Starting new HTTPS connection (1): timelapse-dev.azurewebsites.net:443
2022-10-03 20:02:41,404 DEBUG: https://timelapse-dev.azurewebsites.net:443 "POST /api/Image HTTP/1.1" 200 None
2022-10-03 20:02:41,411 DEBUG: Response code: 200
2022-10-03 20:02:41,412 DEBUG: Image uploaded successfully
2022-10-03 20:02:41,413 DEBUG: Response text:
2022-10-03 20:02:41,415 DEBUG: {
    "id": 201062,
    "timestamp": "2022-10-03T07:02:31Z",
    "blobUri": "https://venaritimelapse.blob.core.windows.net/timelapse/11_2022-10-03_200231.jpg",
    "deviceId": 11,
    "device": {
        "id": 11,
        "serialNumber": "00000000638a42a2",
        "name": "Pi Zero W 2 number 3",
        "description": "3rd camera"
    }
}
2022-10-03 20:02:57,725 INFO: Starting up coreScript.py...
2022-10-03 20:02:57,737 DEBUG: setting sys clock from RTC...
2022-10-03 20:02:57,753 INFO: Starting up uploadPending.py...
2022-10-03 20:02:57,915 DEBUG: sudo hwclock --hctosys succeeded
2022-10-03 20:02:57,916 INFO: In coreScript.py
2022-10-03 21:02:06,729 DEBUG: creating camera object...
2022-10-03 21:02:07,801 DEBUG: beginning capture
2022-10-03 21:02:07,830 DEBUG: warming up camera...
                                                                                                                                                               2022-10-03 21:02:39,008 INFO: Starting up coreScript.py...
2022-10-03 21:02:39,011 DEBUG: setting sys clock from RTC...
2022-10-03 21:02:39,028 INFO: Starting up uploadPending.py...
2022-10-03 21:02:39,172 DEBUG: sudo hwclock --hctosys succeeded
2022-10-03 21:02:39,173 INFO: In coreScript.py
2022-10-03 22:02:06,530 DEBUG: creating camera object...
2022-10-03 22:02:07,556 DEBUG: beginning capture
2022-10-03 22:02:07,581 DEBUG: warming up camera...
                                                                                                                                                                                                                                                                                                                                                                                                                                                                                                                                                                                                                                                                                                                                                                                                                                                                                                                                                                                                                                                                                                                                                                                                                                                                                                                                                                                                                                                                                                                                                                                                                                                                                                                                                                                                                                                                                                                                                                                                                                                                                                                                                                                                                                                                                                                                                                                                                                                                                                                                                                                                                                                                                                                                                                                                                                                                                                                                                                                                                                                                                                                                                                                                    2022-10-03 22:02:39,137 INFO: Starting up coreScript.py...
2022-10-03 22:02:39,149 DEBUG: setting sys clock from RTC...
2022-10-03 22:02:39,166 INFO: Starting up uploadPending.py...
2022-10-03 22:02:39,311 DEBUG: sudo hwclock --hctosys succeeded
2022-10-03 22:02:39,311 INFO: In coreScript.py
2022-10-03 23:02:07,174 DEBUG: creating camera object...
2022-10-03 23:02:08,210 DEBUG: beginning capture
2022-10-03 23:02:08,237 DEBUG: warming up camera...
2022-10-03 23:02:13,243 DEBUG: ready
2022-10-03 23:02:13,963 DEBUG: image saved
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
leighghunt, 2022-10-06:
Operation this time - seems to just keep on waking up every hour until the internet came back

```
2022-10-05 22:03:26,076 INFO: Night time so we're scheduling shutdown
2022-10-05 22:03:26,076 INFO: scheduleShutdown - we're setting the shutdown...
2022-10-05 22:03:26,286 DEBUG: Alarm set for {'data': {'second': 0, 'minute': 0, 'hour': 'EVERY_HOUR', 'day': 'EVERY_DAY'}, 'error': 'NO_ERROR'}
2022-10-05 22:03:26,291 DEBUG: Alarm set for {'data': {'second': 0, 'minute': 0, 'hour': 'EVERY_HOUR', 'day': 'EVERY_DAY'}, 'error': 'NO_ERROR'}
2022-10-05 22:03:26,292 INFO: Shutting down...
2022-10-05 22:03:26,360 INFO: Power off scheduled for 30s from now
2022-10-05 22:02:48,925 INFO: Starting up coreScript.py...
2022-10-05 22:02:48,930 DEBUG: setting sys clock from RTC...
2022-10-05 22:02:48,952 INFO: Starting up uploadPending.py...
2022-10-05 22:02:49,112 DEBUG: sudo hwclock --hctosys succeeded
2022-10-05 22:02:49,113 INFO: In coreScript.py
2022-10-05 22:02:49,244 INFO:  uploading ../output/telemetry/pending/2022-10-05_220326.json
2022-10-05 22:02:49,264 DEBUG: telemetryTimestamp:
2022-10-05 22:02:49,264 DEBUG: 2022-10-05 22:03:26
2022-10-05 22:02:49,285 INFO:  uploading ../output/images/pending/2022-10-05_220325.jpg
2022-10-05 22:02:49,286 DEBUG: imageTimestamp:
2022-10-05 22:02:49,286 DEBUG: 2022-10-05 22:03:25
2022-10-05 22:02:49,287 ERROR: Empty file - deleting
2022-10-05 22:02:49,287 INFO:  uploading ../output/images/pending/2022-10-05_195456.jpg
2022-10-05 22:02:49,288 DEBUG: imageTimestamp:
2022-10-05 22:02:49,288 DEBUG: 2022-10-05 19:54:56
2022-10-05 22:02:49,288 DEBUG: data:
2022-10-05 22:02:49,289 DEBUG: {'SerialNumber': '00000000638a42a2', 'Timestamp': '2022-10-05T19:54:56+13:00'}
2022-10-05 22:02:49,289 DEBUG: Posting image to API...
2022-10-05 22:02:49,665 DEBUG: Starting new HTTPS connection (1): timelapse-dev.azurewebsites.net:443
2022-10-05 22:02:49,669 ERROR: 2022-10-05 22:02:49.669496 uploadPendingPhotos() failed.
2022-10-05 22:02:49,670 ERROR: HTTPSConnectionPool(host='timelapse-dev.azurewebsites.net', port=443): Max retries exceeded with url: /api/Image (Caused by NewConnectionError('<urllib3.connection.VerifiedHTTPSConnection object at 0x75ea9a50>: Failed to establish a new connection: [Errno -3] Temporary failure in name resolution'))
2022-10-05 22:02:59,741 INFO:  uploading ../output/images/pending/2022-10-05_195456.jpg
2022-10-05 22:02:59,742 DEBUG: imageTimestamp:
2022-10-05 22:02:59,742 DEBUG: 2022-10-05 19:54:56
2022-10-05 22:02:59,743 DEBUG: data:
2022-10-05 22:02:59,743 DEBUG: {'SerialNumber': '00000000638a42a2', 'Timestamp': '2022-10-05T19:54:56+13:00'}
2022-10-05 22:02:59,744 DEBUG: Posting image to API...
2022-10-05 22:02:59,771 DEBUG: Starting new HTTPS connection (1): timelapse-dev.azurewebsites.net:443
2022-10-05 22:03:09,783 ERROR: 2022-10-05 22:03:09.783801 uploadPendingPhotos() failed.
2022-10-05 22:03:09,784 ERROR: HTTPSConnectionPool(host='timelapse-dev.azurewebsites.net', port=443): Max retries exceeded with url: /api/Image (Caused by NewConnectionError('<urllib3.connection.VerifiedHTTPSConnection object at 0x75ea9190>: Failed to establish a new connection: [Errno -3] Temporary failure in name resolution'))
2022-10-05 22:03:19,144 DEBUG: creating camera object...
2022-10-05 22:03:19,894 INFO:  uploading ../output/images/pending/2022-10-05_195456.jpg
2022-10-05 22:03:19,895 DEBUG: imageTimestamp:
2022-10-05 22:03:19,895 DEBUG: 2022-10-05 19:54:56
2022-10-05 22:03:19,896 DEBUG: data:
2022-10-05 22:03:19,896 DEBUG: {'SerialNumber': '00000000638a42a2', 'Timestamp': '2022-10-05T19:54:56+13:00'}
2022-10-05 22:03:19,897 DEBUG: Posting image to API...
2022-10-05 22:03:19,927 DEBUG: Starting new HTTPS connection (1): timelapse-dev.azurewebsites.net:443
2022-10-05 22:03:20,203 DEBUG: beginning capture
2022-10-05 22:03:20,227 DEBUG: warming up camera...
2022-10-05 22:03:25,233 DEBUG: ready
2022-10-05 22:03:25,972 DEBUG: image saved
2022-10-05 22:03:25,998 DEBUG: telemetry saved
2022-10-05 22:03:25,999 DEBUG: scheduleShutdown
2022-10-05 22:03:26,000 INFO: Night time so we're scheduling shutdown
2022-10-05 22:03:26,000 INFO: scheduleShutdown - we're setting the shutdown...
2022-10-05 22:03:26,210 DEBUG: Alarm set for {'data': {'second': 0, 'minute': 0, 'hour': 'EVERY_HOUR', 'day':
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

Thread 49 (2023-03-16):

PIJuice comms issue - zero-w-v1-j

leighghunt, 2023-03-16:
PiJuice not communicating with Pi.

- PiJuice doesn’t have any power lights.
- Camera not connecting, even with PiJuice disconnected.
- Solder joints appear OK. But PiJuice has minor signs of heat damage around SW1/J5 - not where we’ve worked.
- Following troubleshooting instructions at https://github.com/PiSupply/PiJuice/tree/master/Firmware#faq

leighghunt, 2023-03-16:
Photos of possible heat damage, and next to another PiJuice that is working fine.

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

leighghunt, 2023-03-16:
Camera looks like it was a loose connector on the camera board.

leighghunt, 2023-03-16:
Supplying power to PiJuice ends up powering Pi - but no PiJuice leds illuminated.

Plugged in battery and registered and reported voltage. Flashing blue at 49% - perhaps red LED is out?

leighghunt, 2023-03-17:
Was working, and now doesn't seem to be - have swapped out for another PiJuice.

Closed 2023-03-17.

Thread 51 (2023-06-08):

Pi continuously restarting every couple if minutes

leighghunt, 2023-06-08:
Log extract:

```
pi@sediment-pi-zero-w-v1-e:~$ tail -f logs/timelapse.log -n 1000

2023-06-08 09:58:05,678 savePhotos INFO Starting up savePhotos.py...
2023-06-08 09:58:05,681 savePhotos INFO In savePhotos.py
2023-06-08 09:58:05,694 savePhotos DEBUG creating camera object...
2023-06-08 09:58:06,446 savePhotos DEBUG (4608, 2592)
2023-06-08 09:58:06,447 savePhotos DEBUG focus_m is 100
2023-06-08 09:58:06,449 savePhotos DEBUG setting lens position to 0.01
2023-06-08 09:58:06,586 savePhotos DEBUG beginning capture
2023-06-08 09:58:06,983 savePhotos DEBUG warming up camera...
2023-06-08 09:58:11,987 savePhotos DEBUG ready

<Restart>

2023-06-08 09:58:49,657 saveTelemetry INFO Starting up saveTelemetry.py...
2023-06-08 10:05:16,264 saveTelemetry INFO Starting up saveTelemetry.py 3b...
2023-06-08 10:05:16,267 saveTelemetry INFO dev rtc doesn't exist - waiting... 0
2023-06-08 10:05:18,586 saveTelemetry INFO dev rtc doesn't exist - waiting... 1
2023-06-08 10:05:21,567 saveTelemetry DEBUG setting sys clock from RTC...
2023-06-08 10:05:22,082 saveTelemetry DEBUG sudo hwclock --hctosys succeeded
2023-06-08 10:05:22,084 saveTelemetry INFO In saveTelemetry.py
2023-06-08 10:05:22,675 saveTelemetry DEBUG telemetry saved
2023-06-08 10:05:26,281 savePhotos INFO Starting up savePhotos.py...
2023-06-08 10:05:26,284 savePhotos INFO In savePhotos.py
2023-06-08 10:05:26,286 savePhotos DEBUG creating camera object...
2023-06-08 10:05:26,968 savePhotos DEBUG (4608, 2592)
2023-06-08 10:05:26,969 savePhotos DEBUG focus_m is 100
2023-06-08 10:05:26,981 savePhotos DEBUG setting lens position to 0.01
2023-06-08 10:05:27,114 savePhotos DEBUG beginning capture
2023-06-08 10:05:27,588 savePhotos DEBUG warming up camera...
2023-06-08 10:05:32,595 savePhotos DEBUG ready
2023-06-08 10:05:37,835 savePhotos DEBUG image saved to working folder
2023-06-08 10:05:37,846 savePhotos DEBUG image moved to pending folder
2023-06-08 10:05:38,360 savePhotos DEBUG destroying camera object

<Restart>

2023-06-08 10:05:59,575 uploadPending INFO Starting up uploadPending.py...
2023-06-08 09:58:49,207 saveTelemetry INFO Starting up saveTelemetry.py...
2023-06-08 10:12:54,070 saveTelemetry INFO Starting up saveTelemetry.py 3b...
2023-06-08 10:12:54,073 saveTelemetry INFO dev rtc doesn't exist - waiting... 0
2023-06-08 10:12:56,594 saveTelemetry DEBUG setting sys clock from RTC...
2023-06-08 10:12:58,490 saveTelemetry DEBUG sudo hwclock --hctosys succeeded
2023-06-08 10:12:58,491 saveTelemetry INFO In saveTelemetry.py
2023-06-08 10:12:58,745 saveTelemetry DEBUG telemetry saved
2023-06-08 10:13:03,269 savePhotos INFO Starting up savePhotos.py...
2023-06-08 10:13:03,281 savePhotos INFO In savePhotos.py
2023-06-08 10:13:03,284 savePhotos DEBUG creating camera object...
2023-06-08 10:13:04,030 savePhotos DEBUG (4608, 2592)
2023-06-08 10:13:04,032 savePhotos DEBUG focus_m is 100
2023-06-08 10:13:04,033 savePhotos DEBUG setting lens position to 0.01
2023-06-08 10:13:04,161 savePhotos DEBUG beginning capture
2023-06-08 10:13:04,564 savePhotos DEBUG warming up camera...
2023-06-08 10:13:09,570 savePhotos DEBUG ready
2023-06-08 10:13:15,575 savePhotos DEBUG image saved to working folder
2023-06-08 10:13:15,588 savePhotos DEBUG image moved to pending folder
2023-06-08 10:13:16,004 savePhotos DEBUG destroying camera object

<Restart>

2023-06-08 10:13:40,520 uploadPending INFO Starting up uploadPending.py...
2023-06-08 10:13:50,527 uploadPending INFO Starting up uploadPending.py 2...
2023-06-08 10:13:50,604 uploadPending INFO System Voltage looks good at 3588mV
2023-06-08 10:13:50,605 uploadPending INFO Current System Power Switch:
2023-06-08 10:13:50,612 uploadPending INFO {'data': 500, 'error': 'NO_ERROR'}
2023-06-08 10:13:50,614 uploadPending INFO Setting System Power Switch to 500:
2023-06-08 10:13:50,638 uploadPending INFO Waiting 50s for modem to warm up...
2023-06-08 10:13:58,807 saveTelemetry DEBUG scheduleShutdown
2023-06-08 10:13:58,824 saveTelemetry DEBUG skipping shutdown scheduling because of config.json
2023-06-08 10:13:58,954 saveTelemetry DEBUG telemetry saved
2023-06-08 10:14:16,057 savePhotos DEBUG creating camera object...
2023-06-08 10:14:16,848 savePhotos DEBUG (4608, 2592)
2023-06-08 10:14:16,850 savePhotos DEBUG focus_m is 100
2023-06-08 10:14:16,851 savePhotos DEBUG setting lens position to 0.01
2023-06-08 10:14:17,297 savePhotos DEBUG beginning capture
2023-06-08 10:14:17,755 savePhotos DEBUG warming up camera...
2023-06-08 10:14:22,762 savePhotos DEBUG ready
2023-06-08 10:14:33,151 savePhotos DEBUG image saved to working folder
2023-06-08 10:14:33,158 savePhotos DEBUG image moved to pending folder
2023-06-08 10:14:33,529 savePhotos DEBUG destroying camera object
2023-06-08 10:14:40,689 uploadPending INFO Waiting for network....
2023-06-08 10:14:40,799 uploadPending INFO Network connection established.
2023-06-08 10:14:40,915 uploadPending INFO  uploading ../output/telemetry/pending/2023-06-08_101358.json
2023-06-08 10:14:41,009 uploadPending DEBUG telemetryTimestamp:
2023-06-08 10:14:41,013 uploadPending DEBUG 2023-06-08 10:13:58
2023-06-08 10:14:41,021 uploadPending DEBUG {'batteryPercent': 99, 'temperatureC': 42, 'diskSpaceFree': 24, 'pendingImages': 66, 'uploadedImages': 80, 'pendingTelemetry': 14, 'uploadedTelemetry': 158, 'uptimeSeconds': 115, 'status': "{'status': {'isFault': True, 'isButton': False, 'battery': 'CHARGING_FROM_IN', 'powerInput': 'PRESENT', 'powerInput5vIo': 'NOT_PRESENT'}, 'batteryVoltage': 3604, 'batteryCurrent': -3301, 'ioVoltage': 5058, 'ioCurrent': 960}", 'SerialNumber': '000000003219e846', 'Timestamp': '2023-06-08T10:13:58+12:00'}
2023-06-08 10:14:43,038 uploadPending DEBUG <Response [200]>
2023-06-08 10:14:43,044 uploadPending DEBUG Telemetry uploaded successfully
2023-06-08 10:14:43,051 uploadPending DEBUG Logged to API.
2023-06-08 10:14:43,056 uploadPending INFO  uploading ../output/telemetry/pending/2023-06-08_101258.json
2023-06-08 10:14:43,063 uploadPending DEBUG telemetryTimestamp:
2023-06-08 10:14:43,066 uploadPending DEBUG 2023-06-08 10:12:58
2023-06-08 10:14:43,075 uploadPending DEBUG {'batteryPercent': 99, 'temperatureC': 41, 'diskSpaceFree': 24, 'pendingImages': 65, 'uploadedImages': 80, 'pendingTelemetry': 13, 'uploadedTelemetry': 158, 'uptimeSeconds': 55, 'status': "{'status': {'isFault': True, 'isButton': False, 'battery': 'CHARGING_FROM_IN', 'powerInput': 'PRESENT', 'powerInput5vIo': 'NOT_PRESENT'}, 'batteryVoltage': 3598, 'batteryCurrent': -3223, 'ioVoltage': 5061, 'ioCurrent': 980}", 'SerialNumber': '000000003219e846', 'Timestamp': '2023-06-08T10:12:58+12:00'}
2023-06-08 10:14:43,499 uploadPending DEBUG <Response [200]>
2023-06-08 10:14:43,504 uploadPending DEBUG Telemetry uploaded successfully
2023-06-08 10:14:43,511 uploadPending DEBUG Logged to API.
2023-06-08 10:14:43,516 uploadPending INFO  uploading ../output/telemetry/pending/2023-06-08_101149.json
2023-06-08 10:14:43,522 uploadPending DEBUG telemetryTimestamp:
2023-06-08 10:14:43,528 uploadPending DEBUG 2023-06-08 10:11:49
2023-06-08 10:14:43,534 uploadPending INFO  uploading ../output/telemetry/pending/2023-06-08_101038.json
2023-06-08 10:14:43,539 uploadPending DEBUG telemetryTimestamp:
2023-06-08 10:14:43,544 uploadPending DEBUG 2023-06-08 10:10:38
2023-06-08 10:14:43,550 uploadPending INFO  uploading ../output/telemetry/pending/2023-06-08_100846.json
2023-06-08 10:14:43,555 uploadPending DEBUG telemetryTimestamp:
2023-06-08 10:14:43,560 uploadPending DEBUG 2023-06-08 10:08:46
2023-06-08 10:14:43,563 uploadPending INFO  uploading ../output/telemetry/pending/2023-06-08_100738.json
2023-06-08 10:14:43,573 uploadPending DEBUG telemetryTimestamp:
2023-06-08 10:14:43,579 uploadPending DEBUG 2023-06-08 10:07:38
2023-06-08 10:14:43,583 uploadPending INFO  uploading ../output/telemetry/pending/2023-06-08_100622.json
2023-06-08 10:14:43,591 uploadPending DEBUG telemetryTimestamp:
2023-06-08 10:14:43,594 uploadPending DEBUG 2023-06-08 10:06:22
2023-06-08 10:14:43,600 uploadPending INFO  uploading ../output/telemetry/pending/2023-06-08_100522.json
2023-06-08 10:14:43,605 uploadPending DEBUG telemetryTimestamp:
2023-06-08 10:14:43,610 uploadPending DEBUG 2023-06-08 10:05:22
2023-06-08 10:14:43,619 uploadPending DEBUG {'batteryPercent': 99, 'temperatureC': 40, 'diskSpaceFree': 24, 'pendingImages': 64, 'uploadedImages': 80, 'pendingTelemetry': 7, 'uploadedTelemetry': 158, 'uptimeSeconds': 57, 'status': "{'status': {'isFault': True, 'isButton': False, 'battery': 'CHARGING_FROM_IN', 'powerInput': 'PRESENT', 'powerInput5vIo': 'NOT_PRESENT'}, 'batteryVoltage': 3599, 'batteryCurrent': -3236, 'ioVoltage': 5056, 'ioCurrent': 442}", 'SerialNumber': '000000003219e846', 'Timestamp': '2023-06-08T10:05:22+12:00'}
2023-06-08 10:14:43,955 uploadPending DEBUG <Response [200]>
2023-06-08 10:14:43,962 uploadPending DEBUG Telemetry uploaded successfully
2023-06-08 10:14:43,970 uploadPending DEBUG Logged to API.
2023-06-08 10:14:43,975 uploadPending INFO  uploading ../output/telemetry/pending/2023-06-08_100413.json
2023-06-08 10:14:43,991 uploadPending DEBUG telemetryTimestamp:
2023-06-08 10:14:43,995 uploadPending DEBUG 2023-06-08 10:04:13
2023-06-08 10:14:44,007 uploadPending INFO  uploading ../output/telemetry/pending/2023-06-08_100307.json
2023-06-08 10:14:44,010 uploadPending DEBUG telemetryTimestamp:
2023-06-08 10:14:44,012 uploadPending DEBUG 2023-06-08 10:03:07
2023-06-08 10:14:44,015 uploadPending INFO  uploading ../output/telemetry/pending/2023-06-08_100202.json
2023-06-08 10:14:44,028 uploadPending DEBUG telemetryTimestamp:
2023-06-08 10:14:44,030 uploadPending DEBUG 2023-06-08 10:02:02
2023-06-08 10:14:44,032 uploadPending INFO  uploading ../output/telemetry/pending/2023-06-08_100056.json
2023-06-08 10:14:44,035 uploadPending DEBUG telemetryTimestamp:
2023-06-08 10:14:44,039 uploadPending DEBUG 2023-06-08 10:00:56
2023-06-08 10:14:44,047 uploadPending INFO  uploading ../output/telemetry/pending/2023-06-08_095948.json
2023-06-08 10:14:44,050 uploadPending DEBUG telemetryTimestamp:
2023-06-08 10:14:44,051 uploadPending DEBUG 2023-06-08 09:59:48
2023-06-08 10:14:44,057 uploadPending INFO  uploading ../output/telemetry/pending/2023-06-08_095801.json
2023-06-08 10:14:44,060 uploadPending DEBUG telemetryTimestamp:
2023-06-08 10:14:44,066 uploadPending DEBUG 2023-06-08 09:58:01
2023-06-08 10:14:44,071 uploadPending DEBUG {'batteryPercent': 99, 'temperatureC': 41, 'diskSpaceFree': 24, 'pendingImages': 63, 'uploadedImages': 80, 'pendingTelemetry': 1, 'uploadedTelemetry': 158, 'uptimeSeconds': 55, 'status': "{'status': {'isFault': True, 'isButton': False, 'battery': 'CHARGING_FROM_IN', 'powerInput': 'PRESENT', 'powerInput5vIo': 'NOT_PRESENT'}, 'batteryVoltage': 3599, 'batteryCurrent': -3236, 'ioVoltage': 5061, 'ioCurrent': 878}", 'SerialNumber': '000000003219e846', 'Timestamp': '2023-06-08T09:58:01+12:00'}
2023-06-08 10:14:44,438 uploadPending DEBUG <Response [200]>
2023-06-08 10:14:44,442 uploadPending DEBUG Telemetry uploaded successfully
2023-06-08 10:14:44,444 uploadPending DEBUG Logged to API.
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
leighghunt, 2023-06-08:
Seems to vary - frequently every few minutes, sometimes to nearly one hour.

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

leighghunt, 2023-06-08:
Seems sporadic - affected a different camera a couple of days ago - didn't notice. Doesn't appear to be related to connection issues.

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

leighghunt, 2023-06-08:
Wondering if it's related to a new battery gaining charge - looking back over some other cameras, there may be a possible correlation with low battery voltage - perhaps the modem powering up is triggering a reboot?

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

leighghunt, 2023-06-08:
There's a definite correlation with uploading data/photos and the restarts - you can see shortly after all but two or three upload periods, there's a restart. Could explain why it started very badly in the morning as it never cleared the image backlog.
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

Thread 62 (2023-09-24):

Refactor logging

leighghunt, 2023-09-24:
Logging currently has a threading issue which causes file contents to be lost when files are rotated.

leighghunt, 2023-11-27:
https://docs.python.org/3/howto/logging-cookbook.html#sending-and-receiving-logging-events-across-a-network

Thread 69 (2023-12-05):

Further PiJuice waking issues

leighghunt, 2023-12-05:
PiJuice still having wakeup reliability issues when no external power.

Some errors logged in `startup.sh.out` include:

```
hwclock: ioctl(RTC_RD_TIME) to /dev/rtc0 to read the time failed: Invalid argument
...
hwclock: RTC read returned an invalid value.
```

leighghunt, 2023-12-05:
Comparison of PiJuice that's working, and one that's not, both shutdown at same time and expected to wake after 10 minutes, one without power, and one with:

```
pi@sediment-pi-zero-w-v1-g:~$ python3 /usr/bin/pijuice_log.py
0 WAKEUP_EVT   2023-12-05 02:58:00.992187, Battery: 40.0%, 3.227V, 26C, NORMAL
        GPIO_5V: REGULATOR: ON, 5.085V, -2.369A, NOT_PRESENT
        TRIGGERS:  RTC
        WAKEUP_ON_CHARGE: DISABLED

1 WAKEUP_EVT   2023-12-05 03:44:00.777343, Battery: 41.6%, 3.597V, 29C, CHARGING_FROM_IN
        GPIO_5V: REGULATOR: OFF, 0.249V, 0.000A, NOT_PRESENT
        TRIGGERS:  RTC
        WAKEUP_ON_CHARGE: DISABLED

2 WAKEUP_EVT   2023-12-05 04:17:00.738281, Battery: 55.6%, 3.598V, 31C, CHARGING_FROM_IN
        GPIO_5V: REGULATOR: OFF, 0.254V, 0.000A, NOT_PRESENT
        TRIGGERS:  RTC
        WAKEUP_ON_CHARGE: DISABLED

pi@sediment-pi-zero-w-v1-g:~$
```

```
pi@sediment-pi-zero-w-v1-e:~$ python3 /usr/bin/pijuice_log.py
0 WAKEUP_EVT   2023-12-05 02:58:00.738281, Battery: 99.6%, 3.581V, 26C, NORMAL
        GPIO_5V: REGULATOR: OFF, 0.238V, 0.000A, NOT_PRESENT
        TRIGGERS:  RTC
        WAKEUP_ON_CHARGE: DISABLED

1 WAKEUP_EVT   2023-12-05 03:44:00.996093, Battery: 99.6%, 3.497V, 24C, NORMAL
        GPIO_5V: REGULATOR: OFF, 0.362V, 0.000A, NOT_PRESENT
        TRIGGERS:  RTC
        WAKEUP_ON_CHARGE: DISABLED

2 WAKEUP_EVT   2023-12-05 04:17:00.996093, Battery: 97.2%, 3.344V, 26C, NORMAL
        GPIO_5V: REGULATOR: OFF, 0.383V, 0.000A, NOT_PRESENT
        TRIGGERS:  RTC
        WAKEUP_ON_CHARGE: DISABLED

3 WAKEUP_EVT   2023-12-05 05:04:33.257812, Battery: 99.6%, 3.375V, 22C, NORMAL
        GPIO_5V: REGULATOR: OFF, 0.267V, 0.000A, NOT_PRESENT
        TRIGGERS: POWER_BUTTON
        WAKEUP_ON_CHARGE: DISABLED

4 WAKEUP_EVT   2023-12-05 05:04:36.949218, Battery: 99.6%, 3.361V, 23C, NORMAL
        GPIO_5V: REGULATOR: OFF, 1.086V, 0.000A, NOT_PRESENT
        TRIGGERS: POWER_BUTTON
        WAKEUP_ON_CHARGE: DISABLED

5 WAKEUP_EVT   2023-12-05 05:04:39.707031, Battery: 99.6%, 3.376V, 24C, NORMAL
        GPIO_5V: REGULATOR: OFF, 0.924V, 0.000A, NOT_PRESENT
        TRIGGERS: POWER_BUTTON
        WAKEUP_ON_CHARGE: DISABLED

6 WAKEUP_EVT   2023-12-05 05:04:39.406250, Battery: 99.6%, 3.374V, 24C, NORMAL
        GPIO_5V: REGULATOR: OFF, 1.965V, 0.000A, NOT_PRESENT
        TRIGGERS: POWER_BUTTON
        WAKEUP_ON_CHARGE: DISABLED

7 WAKEUP_EVT   2023-12-05 05:04:41.335937, Battery: 99.6%, 3.361V, 27C, NORMAL
        GPIO_5V: REGULATOR: OFF, 1.144V, 0.000A, NOT_PRESENT
        TRIGGERS: POWER_BUTTON
        WAKEUP_ON_CHARGE: DISABLED

8 WAKEUP_EVT   2023-12-05 05:04:41.019531, Battery: 99.6%, 3.376V, 27C, NORMAL
        GPIO_5V: REGULATOR: OFF, 1.951V, 0.000A, NOT_PRESENT
        TRIGGERS: POWER_BUTTON
        WAKEUP_ON_CHARGE: DISABLED

9 WAKEUP_EVT   2023-12-05 05:04:42.839843, Battery: 99.6%, 3.377V, 27C, NORMAL
        GPIO_5V: REGULATOR: OFF, 2.120V, 0.000A, NOT_PRESENT
        TRIGGERS: POWER_BUTTON
        WAKEUP_ON_CHARGE: DISABLED

10 WAKEUP_EVT   2023-12-05 05:04:59.613281, Battery: 99.6%, 3.594V, 24C, CHARGING_FROM_IN
        GPIO_5V: REGULATOR: OFF, 0.252V, 0.000A, NOT_PRESENT
        TRIGGERS: POWER_BUTTON
        WAKEUP_ON_CHARGE: DISABLED

pi@sediment-pi-zero-w-v1-e:~$

 @  11 0:-*                                                               89! 13m 1.06 1.0GHz 429M18% 29G11% 2023-12-05 18:18:48

```

You can see the second one only wakes after power is applied (event 10) - looks like RTCC event 2 fired but didn't seem to result in waking.

leighghunt, 2023-12-05:
Shut both down again - with E powered, G not, at 18:27:20

leighghunt, 2023-12-06:
Behaviour of camera E - has not managed to wake today - but seems like multiple RTC events fired - seems like Pi is just failing to finish booting.

```
pi@sediment-pi-zero-w-v1-e:~$ python3 /usr/bin/pijuice_log.py
15 WAKEUP_EVT   2023-12-05 08:39:00.996093, Battery: 99.6%, 3.559V, 25C, NORMAL
        GPIO_5V: REGULATOR: OFF, 0.354V, 0.000A, NOT_PRESENT
        TRIGGERS:  RTC
        WAKEUP_ON_CHARGE: DISABLED

16 WAKEUP_EVT   2023-12-05 09:03:00.996093, Battery: 99.2%, 3.404V, 23C, NORMAL
        GPIO_5V: REGULATOR: OFF, 0.373V, 0.000A, NOT_PRESENT
        TRIGGERS:  RTC
        WAKEUP_ON_CHARGE: DISABLED

17 WAKEUP_EVT   2023-12-05 09:49:53.820312, Battery: 99.6%, 3.409V, 21C, NORMAL
        GPIO_5V: REGULATOR: OFF, 0.262V, 0.000A, NOT_PRESENT
        TRIGGERS: POWER_BUTTON
        WAKEUP_ON_CHARGE: DISABLED

18 WAKEUP_EVT   2023-12-05 10:14:00.996093, Battery: 97.6%, 3.355V, 22C, NORMAL
        GPIO_5V: REGULATOR: OFF, 0.378V, 0.000A, NOT_PRESENT
        TRIGGERS:  RTC
        WAKEUP_ON_CHARGE: DISABLED

19 WAKEUP_EVT   2023-12-05 10:31:28.972656, Battery: 98.4%, 3.351V, 21C, NORMAL
        GPIO_5V: REGULATOR: OFF, 0.264V, 0.000A, NOT_PRESENT
        TRIGGERS: POWER_BUTTON
        WAKEUP_ON_CHARGE: DISABLED

20 WAKEUP_EVT   2023-12-05 10:31:30.484375, Battery: 98.4%, 3.352V, 22C, NORMAL
        GPIO_5V: REGULATOR: OFF, 1.057V, 0.000A, NOT_PRESENT
        TRIGGERS: POWER_BUTTON
        WAKEUP_ON_CHARGE: DISABLED

21 WAKEUP_EVT   2023-12-05 10:31:31.828125, Battery: 98.4%, 3.368V, 22C, NORMAL
        GPIO_5V: REGULATOR: OFF, 1.682V, 0.000A, NOT_PRESENT
        TRIGGERS: POWER_BUTTON
        WAKEUP_ON_CHARGE: DISABLED

22 WAKEUP_EVT   2023-12-05 11:00:00.996093, Battery: 98.0%, 3.326V, 21C, NORMAL
        GPIO_5V: REGULATOR: OFF, 0.380V, 0.000A, NOT_PRESENT
        TRIGGERS:  RTC
        WAKEUP_ON_CHARGE: DISABLED

23 WAKEUP_EVT   2023-12-05 12:00:00.996093, Battery: 99.2%, 3.344V, 20C, NORMAL
        GPIO_5V: REGULATOR: OFF, 0.267V, 0.000A, NOT_PRESENT
        TRIGGERS:  RTC
        WAKEUP_ON_CHARGE: DISABLED

24 WAKEUP_EVT   2023-12-05 13:00:00.996093, Battery: 99.6%, 3.341V, 21C, NORMAL
        GPIO_5V: REGULATOR: OFF, 0.265V, 0.000A, NOT_PRESENT
        TRIGGERS:  RTC
        WAKEUP_ON_CHARGE: DISABLED

25 WAKEUP_EVT   2023-12-05 14:00:00.996093, Battery: 99.6%, 3.342V, 20C, NORMAL
        GPIO_5V: REGULATOR: OFF, 0.265V, 0.000A, NOT_PRESENT
        TRIGGERS:  RTC
        WAKEUP_ON_CHARGE: DISABLED

26 WAKEUP_EVT   2023-12-05 15:00:00.996093, Battery: 99.6%, 3.330V, 20C, NORMAL
        GPIO_5V: REGULATOR: OFF, 0.265V, 0.000A, NOT_PRESENT
        TRIGGERS:  RTC
        WAKEUP_ON_CHARGE: DISABLED

27 WAKEUP_EVT   2023-12-05 16:00:00.996093, Battery: 99.6%, 3.327V, 20C, NORMAL
        GPIO_5V: REGULATOR: OFF, 0.265V, 0.000A, NOT_PRESENT
        TRIGGERS:  RTC
        WAKEUP_ON_CHARGE: DISABLED

28 WAKEUP_EVT   2023-12-05 17:00:00.996093, Battery: 99.6%, 3.323V, 20C, NORMAL
        GPIO_5V: REGULATOR: OFF, 0.264V, 0.000A, NOT_PRESENT
        TRIGGERS:  RTC
        WAKEUP_ON_CHARGE: DISABLED

29 WAKEUP_EVT   2023-12-05 18:00:00.996093, Battery: 99.2%, 3.337V, 19C, NORMAL
        GPIO_5V: REGULATOR: OFF, 0.264V, 0.000A, NOT_PRESENT
        TRIGGERS:  RTC
        WAKEUP_ON_CHARGE: DISABLED

30 WAKEUP_EVT   2023-12-05 19:00:00.996093, Battery: 99.2%, 3.337V, 19C, NORMAL
        GPIO_5V: REGULATOR: OFF, 0.265V, 0.000A, NOT_PRESENT
        TRIGGERS:  RTC
        WAKEUP_ON_CHARGE: DISABLED

31 WAKEUP_EVT   2023-12-05 20:00:00.996093, Battery: 99.2%, 3.338V, 20C, NORMAL
        GPIO_5V: REGULATOR: OFF, 0.265V, 0.000A, NOT_PRESENT
        TRIGGERS:  RTC
        WAKEUP_ON_CHARGE: DISABLED

32 WAKEUP_EVT   2023-12-05 21:00:00.996093, Battery: 99.2%, 3.326V, 20C, NORMAL
        GPIO_5V: REGULATOR: OFF, 0.265V, 0.000A, NOT_PRESENT
        TRIGGERS:  RTC
        WAKEUP_ON_CHARGE: DISABLED

33 WAKEUP_EVT   2023-12-05 22:00:00.996093, Battery: 99.2%, 3.324V, 21C, NORMAL
        GPIO_5V: REGULATOR: OFF, 0.267V, 0.000A, NOT_PRESENT
        TRIGGERS:  RTC
        WAKEUP_ON_CHARGE: DISABLED

34 WAKEUP_EVT   2023-12-05 23:00:00.996093, Battery: 99.2%, 3.322V, 21C, NORMAL
        GPIO_5V: REGULATOR: OFF, 0.267V, 0.000A, NOT_PRESENT
        TRIGGERS:  RTC
        WAKEUP_ON_CHARGE: DISABLED

35 WAKEUP_EVT   2023-12-06 00:00:00.996093, Battery: 99.2%, 3.329V, 21C, NORMAL
        GPIO_5V: REGULATOR: OFF, 0.267V, 0.000A, NOT_PRESENT
        TRIGGERS:  RTC
        WAKEUP_ON_CHARGE: DISABLED

36 WAKEUP_EVT   2023-12-06 01:00:00.996093, Battery: 99.2%, 3.336V, 22C, NORMAL
        GPIO_5V: REGULATOR: OFF, 0.267V, 0.000A, NOT_PRESENT
        TRIGGERS:  RTC
        WAKEUP_ON_CHARGE: DISABLED

37 WAKEUP_EVT   2023-12-06 02:00:00.996093, Battery: 99.2%, 3.323V, 23C, NORMAL
        GPIO_5V: REGULATOR: OFF, 0.270V, 0.000A, NOT_PRESENT
        TRIGGERS:  RTC
        WAKEUP_ON_CHARGE: DISABLED

38 WAKEUP_EVT   2023-12-06 03:00:00.996093, Battery: 99.2%, 3.320V, 23C, NORMAL
        GPIO_5V: REGULATOR: OFF, 0.270V, 0.000A, NOT_PRESENT
        TRIGGERS:  RTC
        WAKEUP_ON_CHARGE: DISABLED

39 WAKEUP_EVT   2023-12-06 04:00:00.996093, Battery: 99.2%, 3.320V, 23C, NORMAL
        GPIO_5V: REGULATOR: OFF, 0.270V, 0.000A, NOT_PRESENT
        TRIGGERS:  RTC
        WAKEUP_ON_CHARGE: DISABLED

40 WAKEUP_EVT   2023-12-06 05:00:00.996093, Battery: 99.2%, 3.329V, 22C, NORMAL
        GPIO_5V: REGULATOR: OFF, 0.269V, 0.000A, NOT_PRESENT
        TRIGGERS:  RTC
        WAKEUP_ON_CHARGE: DISABLED

41 WAKEUP_EVT   2023-12-06 06:00:00.996093, Battery: 99.2%, 3.331V, 23C, NORMAL
        GPIO_5V: REGULATOR: OFF, 0.267V, 0.000A, NOT_PRESENT
        TRIGGERS:  RTC
        WAKEUP_ON_CHARGE: DISABLED

42 WAKEUP_EVT   2023-12-06 07:00:00.996093, Battery: 99.2%, 3.333V, 22C, NORMAL
        GPIO_5V: REGULATOR: OFF, 0.269V, 0.000A, NOT_PRESENT
        TRIGGERS:  RTC
        WAKEUP_ON_CHARGE: DISABLED

43 WAKEUP_EVT   2023-12-06 08:00:00.996093, Battery: 99.2%, 3.319V, 22C, NORMAL
        GPIO_5V: REGULATOR: OFF, 0.269V, 0.000A, NOT_PRESENT
        TRIGGERS:  RTC
        WAKEUP_ON_CHARGE: DISABLED

44 WAKEUP_EVT   2023-12-06 08:54:25.562500, Battery: 98.8%, 3.345V, 21C, NORMAL
        GPIO_5V: REGULATOR: OFF, 0.267V, 0.000A, NOT_PRESENT
        TRIGGERS: POWER_BUTTON
        WAKEUP_ON_CHARGE: DISABLED

45 WAKEUP_EVT   2023-12-06 08:54:28.699218, Battery: 98.8%, 3.327V, 24C, NORMAL
        GPIO_5V: REGULATOR: OFF, 1.019V, 0.000A, NOT_PRESENT
        TRIGGERS: POWER_BUTTON
        WAKEUP_ON_CHARGE: DISABLED

46 WAKEUP_EVT   2023-12-06 08:54:40.812500, Battery: 99.2%, 3.607V, 24C, CHARGING_FROM_IN
        GPIO_5V: REGULATOR: OFF, 0.295V, 0.000A, NOT_PRESENT
        TRIGGERS: POWER_BUTTON
        WAKEUP_ON_CHARGE: DISABLED
```

Reviewing logs however, no indication of even the start of a boot up, unlike the previous day where several unssucessful attempts were logged.

leighghunt, 2023-12-19:
Another set of issues waking.

Pijuice_log:

```
109 WAKEUP_EVT   2023-12-18 11:02:00.992187, Battery: 35.6%, 3.209V, 27C, NORMAL
	GPIO_5V: REGULATOR: ON, 5.114V, -0.321A, NOT_PRESENT
	TRIGGERS:  RTC
	WAKEUP_ON_CHARGE: DISABLED

110 WAKEUP_EVT   2023-12-18 12:02:00.511718, Battery: 34.8%, 3.225V, 27C, NORMAL
	GPIO_5V: REGULATOR: ON, 5.112V, 0.057A, NOT_PRESENT
	TRIGGERS:  RTC
	WAKEUP_ON_CHARGE: DISABLED

111 WAKEUP_EVT   2023-12-18 13:02:00.992187, Battery: 34.0%, 3.226V, 27C, NORMAL
	GPIO_5V: REGULATOR: ON, 5.115V, -0.301A, NOT_PRESENT
	TRIGGERS:  RTC
	WAKEUP_ON_CHARGE: DISABLED

112 WAKEUP_EVT   2023-12-18 14:02:00.992187, Battery: 33.6%, 3.226V, 27C, NORMAL
	GPIO_5V: REGULATOR: ON, 5.114V, -0.382A, NOT_PRESENT
	TRIGGERS:  RTC
	WAKEUP_ON_CHARGE: DISABLED

113 WAKEUP_EVT   2023-12-18 15:02:00.992187, Battery: 32.8%, 3.225V, 27C, NORMAL
	GPIO_5V: REGULATOR: ON, 5.114V, -0.443A, NOT_PRESENT
	TRIGGERS:  RTC
	WAKEUP_ON_CHARGE: DISABLED

114 WAKEUP_EVT   2023-12-18 16:02:00.519531, Battery: 32.4%, 3.220V, 27C, NORMAL
	GPIO_5V: REGULATOR: ON, 5.112V, 0.065A, NOT_PRESENT
	TRIGGERS:  RTC
	WAKEUP_ON_CHARGE: DISABLED
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

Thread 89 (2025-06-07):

Camera issues following latest update

leighghunt, 2025-06-07:
```
libcamera-hello: symbol lookup error: /lib/arm-linux-gnueabihf/libcamera.so.0.3: undefined symbol: _ZN7libpisp22compute_optimal_strideER24pisp_image_format_config
```

leighghunt, 2025-06-07:
Tried doing another updated and noticed this:

```
127 pi@envirocam-a:~$ sudo apt-get update
Hit:1 http://archive.raspberrypi.com/debian bookworm InRelease
Hit:2 http://raspbian.raspberrypi.com/raspbian bookworm InRelease
Get:3 https://pkgs.tailscale.com/stable/raspbian bookworm InRelease
Fetched 6,581 B in 11s (626 B/s)
Reading package lists... Done
W: http://raspbian.raspberrypi.com/raspbian/dists/bookworm/InRelease: Key is stored in legacy trusted.gpg keyring (/etc/apt/trusted.gpg), see the DEPRECATION section in apt-key(8) for details.
pi@envirocam-a:~$ sudo apt-get upgrade -y
Reading package lists... Done
Building dependency tree... Done
Reading state information... Done
Calculating upgrade... Done
The following packages were automatically installed and are no longer required:
  libcamera0.2 libdrm-amdgpu1 libdrm-nouveau2 libdrm-radeon1 libllvm15 libsensors-config libsensors5 libz3-4
Use 'sudo apt autoremove' to remove them.
The following packages have been kept back:
  firmware-libertas firmware-misc-nonfree libcamera-ipa libgbm1 libglapi-mesa libglx-mesa0 linux-headers-rpi-v6 linux-headers-rpi-v7 linux-headers-rpi-v7l linux-image-rpi-v6
  linux-image-rpi-v7 linux-image-rpi-v7l linux-image-rpi-v8:arm64 python3-libcamera raspi-config raspi-utils rpi-eeprom rpicam-apps-lite
0 upgraded, 0 newly installed, 0 to remove and 18 not upgraded.
pi@envirocam-a:~$ sudo apt autoremove
Reading package lists... Done
Building dependency tree... Done
Reading state information... Done
The following packages will be REMOVED:
  libcamera0.2 libdrm-amdgpu1 libdrm-nouveau2 libdrm-radeon1 libllvm15 libsensors-config libsensors5 libz3-4
0 upgraded, 0 newly installed, 8 to remove and 18 not upgraded.
After this operation, 126 MB disk space will be freed.
Do you want to continue? [Y/n] y
(Reading database ... 71373 files and directories currently installed.)
Removing libcamera0.2:armhf (0.2.0+rpt20240418-1) ...
Removing libdrm-amdgpu1:armhf (2.4.123-1~bpo12+1+rpt1) ...
Removing libdrm-nouveau2:armhf (2.4.123-1~bpo12+1+rpt1) ...
Removing libdrm-radeon1:armhf (2.4.123-1~bpo12+1+rpt1) ...
Removing libllvm15:armhf (1:15.0.6-4+rpi1+b1) ...
Removing libsensors5:armhf (1:3.6.0-7.1) ...
Removing libsensors-config (1:3.6.0-7.1) ...
Removing libz3-4:armhf (4.8.12-3.1) ...
Processing triggers for libc-bin (2.36-9+rpt2+deb12u10) ...
```

Wonder if it's related to https://github.com/raspberrypi/libcamera/issues/272?

leighghunt, 2025-06-08:
Also affecting ```rpicam-hello```:

```
rpicam-hello: symbol lookup error: /lib/arm-linux-gnueabihf/libcamera.so.0.3: undefined symbol: _ZN7libpisp22compute_optimal_strideER24pisp_image_format_config
```

leighghunt, 2025-06-08:
```
127 pi@envirocam-a:~$ apt policy libcamera0.3
libcamera0.3:
  Installed: 0.3.2+rpt20241119-1
  Candidate: 0.3.2+rpt20241119-1
  Version table:
 *** 0.3.2+rpt20241119-1 500
        500 http://archive.raspberrypi.com/debian bookworm/main armhf Packages
        100 /var/lib/dpkg/status
pi@envirocam-a:~$
```

leighghunt, 2025-06-08:
Part way through full upgrade, images started getting saved again.

Note update takes > half an hour on wireless, so may encounter issues running remotely, especially with 30 min restart trigger if no images are detected.

Closed 2025-06-08.

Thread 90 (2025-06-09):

Install issues on enviroeye-b

leighghunt, 2025-06-09:
Some errors possibly caused by partially being run from within `dev` folder, but also looks like git may have been interrupted.

```
Requirement already satisfied: numpy in /usr/lib/python3/dist-packages (from suncalc) (1.24.2)
Installing collected packages: suncalc
Successfully installed suncalc-0.1.3

The Byobu window manager will be launched automatically at each text login.

To disable this behavior later, just run:
  byobu-disable

Generating locales (this might take a while)...
  en_GB.UTF-8... done
  en_NZ.UTF-8...^[[B^[[C done
Generation complete.
Setting timezone...
Cloning repo...
Cloning into 'timelapse'...
remote: Enumerating objects: 6067, done.
remote: Counting objects: 100% (308/308), done.
remote: Compressing objects: 100% (123/123), done.
error: RPC failed; curl 56 Recv failure: Connection reset by peer
error: 5305 bytes of body are still expected
fetch-pack: unexpected disconnect while reading sideband packet
fatal: early EOF
fatal: fetch-pack: invalid index-pack output
/dev/fd/63: line 95: cd: timelapse: No such file or directory
fatal: not in a git directory
fatal: not a git repository (or any of the parent directories): .git
sed: can't read /home/pi/dev/timelapse/scripts/config.json: No such file or directory
Checking RTC module is enabled in config.txt
Checking static domain_name_servers entry etc/dhcpcd.conf
no crontab for pi
Installing systemd services...
cp: cannot stat '/home/pi/dev/timelapse/systemd/system/*.*': No such file or directory
chmod: cannot access '/etc/systemd/system/enviro*.*': No such file or directory
Failed to enable unit: Unit file envirocam-logging.service does not exist.
Failed to enable unit: Unit file envirocam-telemetry.service does not exist.
Failed to enable unit: Unit file envirocam-photos.timer does not exist.
Failed to enable unit: Unit file envirocam-upload.timer does not exist.
Failed to enable unit: Unit file envirocam-detect-hang.timer does not exist.
Overwriting pijuice config...
Installing Tailscale...
Installing Tailscale for raspbian bookworm, using method apt
+ sudo mkdir -p --mode=0755 /usr/share/keyrings
+ + curlsudo -fsSL https://pkgs.tailscale.com/stable/raspbian/bookworm.noarmor.gpg
 tee /usr/share/keyrings/tailscale-archive-keyring.gpg
+ sudo chmod 0644 /usr/share/keyrings/tailscale-archive-keyring.gpg
+ + curl -fsSL https://pkgs.tailscale.com/stable/raspbian/bookworm.tailscale-keyring.listsudo
 tee /etc/apt/sources.list.d/tailscale.list
# Tailscale packages for raspbian bookworm
deb [signed-by=/usr/share/keyrings/tailscale-archive-keyring.gpg] https://pkgs.tailscale.com/stable/raspbian bookworm main
+ sudo chmod 0644 /etc/apt/sources.list.d/tailscale.list
+ sudo apt-get update
Hit:1 http://archive.raspberrypi.com/debian bookworm InRelease
Hit:2 http://raspbian.raspberrypi.com/raspbian bookworm InRelease
Get:3 https://pkgs.tailscale.com/stable/raspbian bookworm InRelease
Fetched 6,581 B in 20s (334 B/s)ttps://github.com/venari/timelapse/raw/main/install.sh?$RANDOM")
Reading package lists... 29%ithub.com/venari/timelapse/raw/main/install.sh?$RANDOM")
```

leighghunt, 2025-06-09:
Resolved by correcting folder, and running installation again.

Closed 2025-06-09.

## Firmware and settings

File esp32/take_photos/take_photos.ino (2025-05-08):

#include "esp_camera.h"
#include "FS.h"
#include "SPI.h"
// #include <U8x8lib.h>
#include <Wire.h>
#include <NTPClient.h>
#include <WiFiUdp.h>
#include "RTClib.h"
#include <EEPROM.h>
// #include <HTTPClient.h>
#include <WiFiClientSecure.h>
#include <ArduinoJson.h>

#define CAMERA_MODEL_XIAO_ESP32S3  // Has PSRAM
#define WAVESHARE_ESP32_S3_SIM7670G_4G // Waveshare board

#define MAX17048_I2C_ADDRESS 0x36

#include "camera_pins.h"
#include "wifi_functions.h"
#include "log_functions.h"
#include "sd_functions.h"
#include "status_functions.h"

#define PIN_WIRE_SDA (4u)
#define PIN_WIRE_SCL (5u)

// U8X8_SSD1306_128X64_NONAME_HW_I2C u8x8(/* reset=*/U8X8_PIN_NONE);



// #define U8LOG_WIDTH 16
// #define U8LOG_HEIGHT 8
// uint8_t u8log_buffer[U8LOG_WIDTH * U8LOG_HEIGHT];
// U8X8LOG u8x8log;

char MACAddress[25] = "Not set";

WiFiUDP ntpUDP;
NTPClient timeClient(ntpUDP, "pool.ntp.org");

#define uS_TO_S_FACTOR 1000000ULL /* Conversion factor for micro seconds to seconds */
#define TIME_TO_SLEEP 60          /* Time ESP32 will go to sleep (in seconds) */

#if CONFIG_IDF_TARGET_ESP32
#define THRESHOLD 40   /* Greater the value, more the sensitivity */
#else                  //ESP32-S2 and ESP32-S3 + default for other chips (to be adjusted) */
#define THRESHOLD 5000 /* Lower the value, more the sensitivity */
#endif


// RTC_PCF8563 rtc;
RTC_DS1307 rtc;
// Pin Out definition: https://www.waveshare.com/esp32-s3-sim7670g-4g.htm
// Including pins that are used by caemra/TF card/modem, etc.
// const int RTC_DS1037_SDA = 12;
// const int RTC_DS1037_SCL = 11;
const int RTC_DS1037_SDA = 1;// ;
const int RTC_DS1037_SCL = 21; //5;
// DateTime rtcBootTime = DateTime(2000, 1, 1);



// RTC_DATA_ATTR int bootCount = 0;

touch_pad_t touchPin;

const bool enableSleep = true;
const bool TPL5110 = false;
const int TPL5110_Reset_PIN = Y9_GPIO_NUM;

unsigned long lastCaptureTime = 0;  // Last shooting time
int imageCounter = 1;               // File Counter
int telemetryCounter = 1;

// int epochPseudoRTC = 0;             // Save time of last sleep in case we don't have a real RTC.

bool camera_sign = false;  // Check camera status

const char *serverName = "timelapse-dev.azurewebsites.net";
const int port = 443;
const char *apiPostImageURL = "/api/Image";
// const char *apiPostImageURL = "https://webhook.site/fc3e2df5-bb36-48a5-8e04-148c41a03839";
#define CHUNK_SIZE 4096  // Adjust this to a smaller size if needed

const char *ISO8061FormatString = "%04d-%02d-%02dT%02d:%02d:%02dZ";
const char *YYYYMMDDHHMMSSFormatString = "%04d-%02d-%02d_%02d%02d%02d";


// void displayMessage(const char *message) {
//   u8x8log.print(message);
//   u8x8log.print("\n");
// }

// void displayMessageNoNewline(const char *message) {
//   u8x8log.print(message);
// }




void saveTelemetry() {

  Serial.println("saveTelemetry()...");
  logRTC();
  currentStatus = STATUS_SAVING_TELEMETRY;

  char filename[100];
  char rtcTime[25];

  DateTime now = rtc.now();
  sprintf(rtcTime, YYYYMMDDHHMMSSFormatString, now.year(), now.month(), now.day(), now.hour(), now.minute(), now.second());

  sprintf(filename, "%s/telemetry.%08d.%s.json", pendingTelemetryFolder, telemetryCounter, rtcTime);
  // Serial.printf("Telemetry filename: %s", filename);

  digitalWrite(LED_BUILTIN, LOW);  // XIAO ESP32S3 LOW = on

  // https://wiki.seeedstudio.com/check_battery_voltage/
  // https://forum.seeedstudio.com/t/battery-voltage-monitor-and-ad-conversion-for-xiao-esp32c/267535
  logRTC();
  // Serial.println("About to check voltage");
  uint32_t Vbatt = 0;
  // for (int i = 0; i < 16; i++) {
  //   Vbatt = Vbatt + analogReadMilliVolts(A0);  // ADC with correction
  // }
  int Vbattf = 2 * Vbatt / 16;  /// 1000.0;     // attenuation ratio 1/2, mV --> V
  float batteryLevel = getBatteryLevel();
  logRTC();
  // Serial.println(Vbattf, 3);

  // const int capacity = JSON_ARRAY_SIZE(1) + 2*JSON_OBJECT_SIZE(4);
  const int capacity = JSON_OBJECT_SIZE(8);
  StaticJsonDocument<capacity> doc;

  // JsonDocument doc;

  doc["BatteryPercent"] = batteryLevel;
  doc["TemperatureC"] = 21;
  doc["DiskSpaceFree"] = 0;
  doc["PendingImages"] = countFiles(pendingImageFolder);
  doc["PendingTelemetry"] = countFiles(pendingTelemetryFolder);
  doc["UptimeSeconds"] = millis() / 1000;

  // doc['status']['batteryVoltage'] = Vbattf;
  // String status = "{\'status':\"OK\", \"batteryVoltage\":" + String(Vbattf) + "}";
  // String status = "{'status': {'isFault': False, 'isButton': False, 'battery': 'UNKNOWN', 'powerInput': 'UNKNOWN', 'powerInput5vIo': 'NOT_PRESENT'}, 'batteryVoltage': " + String(Vbattf) + ", 'batteryCurrent': 0, 'ioVoltage': 0, 'ioCurrent': 0}";
  String status = "{'status': {'isFault': False, 'isButton': False, 'battery': 'UNKNOWN', 'powerInput': 'UNKNOWN', 'powerInput5vIo': 'NOT_PRESENT'}, 'batteryVoltage': " + String(Vbattf) + ", 'batteryCurrent': 0, 'ioVoltage': 0, 'ioCurrent': 0}";


  doc["Status"] = status;
  doc["SerialNumber"] = MACAddress;

  File file = SD_MMC.open(filename, FILE_WRITE);
  String strJSON;
  serializeJsonPretty(doc, strJSON);
  // Serial.printf("strJSON");
  // Serial.printf(strJSON.c_str());
  file.print(strJSON);

  digitalWrite(LED_BUILTIN, HIGH);

  // Serial.printf("Saved telemetry: %s\r\n", filename);
  updateCounter(counterFilenameTelemetry, ++telemetryCounter);
}

float getBatteryLevel(){
  Wire.beginTransmission(MAX17048_I2C_ADDRESS);
  Wire.write(0x02);
  Wire.endTransmission();

  Wire.requestFrom(MAX17048_I2C_ADDRESS, 2);
  uint16_t soc = (Wire.read() << 8) | Wire.read();

  if (soc > 65535) {
    soc = 65535;
  }

  // float batteryLevel = (float)soc / 65535.0 * 100.0;
  float batteryLevel = (float)soc / 65535.0 * 5;

  Serial.print("Battery Level: ");
  Serial.print(batteryLevel);
  Serial.println("%");

  return batteryLevel;
}

void savePhoto() {

  Serial.println("savePhoto()");
  logRTC();

  currentStatus = STATUS_SAVING_PHOTO;


  char filename[100];
  char rtcTime[25];

  DateTime now = rtc.now();
  sprintf(rtcTime, YYYYMMDDHHMMSSFormatString, now.year(), now.month(), now.day(), now.hour(), now.minute(), now.second());

  sprintf(filename, "%s/image.%08d.%s.jpg", pendingImageFolder, imageCounter, rtcTime);
  Serial.printf("Save Photo filename: %s\n", filename);
  logRTC();


  // Serial.println("Starting photo_save()");
  digitalWrite(LED_BUILTIN, LOW);  // XIAO ESP32S3 LOW = on
  Serial.printf("Taking photo... %5d\n", millis());
  // delay(500);

  camera_fb_t *fb = esp_camera_fb_get();
  if (!fb) {
    logError("Failed to get camera frame buffer");
    return;
  }

  Serial.printf("Writing file... %5d\n", millis());
  // Serial.printf("Writing file...", millis());
  // Save photo to file
  writeFile(SD_MMC, filename, fb->buf, fb->len);
  Serial.printf("File written %5d\n", millis());

  // Release image buffer
  esp_camera_fb_return(fb);
  Serial.printf("image buffer released %5d\n", millis());

  digitalWrite(LED_BUILTIN, HIGH);

  Serial.printf("Saved picture: %s\r\n", filename);
  updateCounter(counterFilenameImages, ++imageCounter);
}



void print_wakeup_reason() {
  esp_sleep_wakeup_cause_t wakeup_reason;

  wakeup_reason = esp_sleep_get_wakeup_cause();

  switch (wakeup_reason) {
    case ESP_SLEEP_WAKEUP_EXT0: Serial.println("Wakeup caused by external signal using RTC_IO"); break;
    case ESP_SLEEP_WAKEUP_EXT1: Serial.println("Wakeup caused by external signal using RTC_CNTL"); break;
    case ESP_SLEEP_WAKEUP_TIMER: Serial.println("Wakeup caused by timer"); break;
    case ESP_SLEEP_WAKEUP_TOUCHPAD: Serial.println("Wakeup caused by touchpad"); break;
    case ESP_SLEEP_WAKEUP_ULP: Serial.println("Wakeup caused by ULP program"); break;
    default: Serial.printf("Wakeup was not caused by deep sleep: %d\n", wakeup_reason); break;
  }
}

void print_wakeup_touchpad() {
  touchPin = esp_sleep_get_touchpad_wakeup_status();

#if CONFIG_IDF_TARGET_ESP32
  switch (touchPin) {
    case 0: Serial.println("Touch detected on GPIO 4"); break;
    case 1: Serial.println("Touch detected on GPIO 0"); break;
    case 2: Serial.println("Touch detected on GPIO 2"); break;
    case 3: Serial.println("Touch detected on GPIO 15"); break;
    case 4: Serial.println("Touch detected on GPIO 13"); break;
    case 5: Serial.println("Touch detected on GPIO 12"); break;
    case 6: Serial.println("Touch detected on GPIO 14"); break;
    case 7: Serial.println("Touch detected on GPIO 27"); break;
    case 8: Serial.println("Touch detected on GPIO 33"); break;
    case 9: Serial.println("Touch detected on GPIO 32"); break;
    default: Serial.println("Wakeup not by touchpad"); break;
  }
#else
  if (touchPin < TOUCH_PAD_MAX) {
    Serial.printf("Touch detected on GPIO %d\n", touchPin);
  } else {
    Serial.println("Wakeup not by touchpad");
  }
#endif
}



void getNTPTime() {

  timeClient.begin();
  // timeClient.setTimeOffset(19800);
  timeClient.update();

  // Get NTP time....
  if (timeClient.isTimeSet()) {

    // Do all of this without logging/displaying to avoid introducing a few seconds delay.
    time_t epochTime = timeClient.getEpochTime();
    struct tm *ptm = gmtime(&epochTime);
    int monthDay = ptm->tm_mday;
    int currentMonth = ptm->tm_mon + 1;
    // String currentMonthName = months[currentMonth - 1];
    int currentYear = ptm->tm_year + 1900;

    // DateTime now = rtc.now();

    // Compare the time from the NTP server with the RTC time, and report the discrepancy in seconds.
    int timeDiscrepancy = rtc.now().unixtime() - epochTime;
    if (abs(timeDiscrepancy) > 5) {
      Serial.println("updating time....");
      logRTC();
      rtc.adjust(DateTime(currentYear, currentMonth, monthDay, ptm->tm_hour, ptm->tm_min, ptm->tm_sec));
      Serial.printf("RTC/NTP Time discrepancy was %d seconds\n", timeDiscrepancy);
      Serial.println("Updated RTC Time:");
      logRTC();
    }

  } else {
    logError("NTP Time is not set");
  }
}

int uploadPendingImages() {
  // returns true if all pending images have been uploaded.
  Serial.println("uploadPendingImages()");

  // Scan folder, retrieving most recent files first
  String *sortedFiles = listAndSortFiles(pendingImageFolder);
  int filesUploaded = 0;
  int filesToUpload = 0;

  // Array will be 100 large, with empty entries if files don't exist.
  for (int fileIndex = 0; fileIndex < FileArraySize; ++fileIndex) {
    if (sortedFiles[fileIndex].length() > 0) {
      ++filesToUpload;
    }
  }

  Serial.printf("Uploading: %d images\n", filesToUpload);

  for (int fileIndex = 0; fileIndex < FileArraySize && fileIndex < filesToUpload; ++fileIndex) {
    if (fileIndex >= ImageFileBatchSize) {
      Serial.printf("Batch size: %d (%d files remaining)\n", ImageFileBatchSize, filesToUpload - fileIndex);
      break;
    } else {
      // Serial.printf("Uploading %d/%d...", fileIndex + 1, filesToUpload);
      // displayMessageNoNewline(".");
      Serial.print(".");
    }

    String pendingFilename = pendingImageFolder;
    pendingFilename += "/";
    pendingFilename += sortedFiles[fileIndex];

    File file = SD_MMC.open(pendingFilename);

    if (!file.isDirectory()) {

      // Serial.printf(file.name());

      String boundary = "----WebKitFormBoundary" + String(random(0xFFFFFF), HEX);

      WiFiClientSecure client;
      client.setInsecure();  // Disable SSL certificate verification

      if (!client.connect(serverName, port)) {
        Serial.println("Connection failed!");
        return false;
      }

      String timestampString = file.name();
      // Serial.println(timestampString.c_str());
      timestampString.replace("_", "T");
      // Serial.println(timestampString.c_str());

      timestampString = timestampString.substring(15);
      // image.00000000.2000-00-01_454902.jpg
      // image.00000000.2000-00-01T454902.jpg
      // 01234567890123456789012345678901234567890123456789
      // 0000000000111111111122222222223333333333
      //                ^

      // Serial.println(timestampString.c_str());

      // 2000-00-01T454902.jpg
      // 01234567890123456789012345678901234567890123456789
      // 0000000000111111111122222222223333333333

      timestampString = timestampString.substring(0, 13) + ":" + timestampString.substring(13, 15) + ":" + timestampString.substring(15, 17) + "Z";
      // 2000-00-01T45:49:02.jpg
      // 01234567890123456789012345678901234567890123456789
      // 0000000000111111111122222222223333333333
      // ------------- -- --Z
      // Serial.println(timestampString.c_str());

      // https://forum.arduino.cc/t/sending-video-avi-and-audio-wav-files-with-arduino-script-from-esp32s3-via-http-post-multipart-form-data-to-server/1234706
      // https://stackoverflow.com/questions/53264373/try-to-send-image-file-to-php-with-httpclient

      String start_request = "--" + boundary + "\r\n";
      start_request += "Content-Disposition: form-data; name=\"SerialNumber\"\r\n\r\n";
      start_request += MACAddress;
      start_request += "\r\n";
      start_request += "--" + boundary + "\r\n";
      start_request += "Content-Disposition: form-data; name=\"Timestamp\"\r\n\r\n";
      start_request += timestampString;
      start_request += "\r\n";
      start_request += "--" + boundary + "\r\n";
      start_request += "Content-Disposition: form-data; name=\"File\"; filename=\"";
      start_request += file.name();
      start_request += "\"\r\n";
      start_request += "Content-Type: image/png\r\n\r\n";

      // Serial.print(start_request);

      String end_request = "\r\n--" + boundary + "--\r\n";

      int fileLength = file.size();
      int contentLength = start_request.length() + fileLength + end_request.length();

      client.printf("POST /api/Image HTTP/1.1\r\n");
      client.printf("Host: %s\r\n", serverName);
      client.printf("Content-Type: multipart/form-data; boundary=%s\r\n", boundary.c_str());
      client.printf("Content-Length: %d\r\n", contentLength);
      client.printf("Connection: close\r\n\r\n");

      client.print(start_request);

      uint8_t buffer[CHUNK_SIZE];
      while (file.available()) {
        size_t len = file.read(buffer, sizeof(buffer));
        client.write(buffer, len);
      }
      client.print(end_request);

      file.close();


      // Read the response from the server
      bool okResponse = false;
      bool NotFoundResponse = false;
      while (client.connected() || client.available()) {
        if (client.available()) {
          String line = client.readStringUntil('\n');
          if (line.indexOf("HTTP/1.1 200 OK") != -1) {
            okResponse = true;
            break;
          }
          if (line.indexOf("HTTP/1.1 404 Not Found") != -1) {
            NotFoundResponse = true;
            break;
          }
          Serial.println(line);
        }
      }
      client.stop();

      if (okResponse) {
        // Serial.println("Deleting file....");
        // Serial.println(pendingFilename);
        ++filesUploaded;
        flash(0, 0, 255, 1);

        if (!SD_MMC.remove(pendingFilename)) {
          logError("Failed to delete file");
        }
      } else {

        flash(255, 0, 0, 1);

        if (NotFoundResponse) {
          Serial.println("404 - check device is registered.");
        } else {
          Serial.println("Error sending data.");

          // TO DO - reject file here probably
        }
      }
    }
  }

  return filesToUpload - filesUploaded;
}
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
void loop() {
  displayStatus();

  delay(1000);

  logRTC();
  enableWakeupAndGoToSleep();
}

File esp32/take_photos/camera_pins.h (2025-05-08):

#if defined(CAMERA_MODEL_WROVER_KIT)
#define PWDN_GPIO_NUM    -1
#define RESET_GPIO_NUM   -1
#define XCLK_GPIO_NUM    21
#define SIOD_GPIO_NUM    26
#define SIOC_GPIO_NUM    27

#define Y9_GPIO_NUM      35
#define Y8_GPIO_NUM      34
#define Y7_GPIO_NUM      39
#define Y6_GPIO_NUM      36
#define Y5_GPIO_NUM      19
#define Y4_GPIO_NUM      18
#define Y3_GPIO_NUM       5
#define Y2_GPIO_NUM       4
#define VSYNC_GPIO_NUM   25
#define HREF_GPIO_NUM    23
#define PCLK_GPIO_NUM    22

#elif defined(CAMERA_MODEL_ESP_EYE)
#define PWDN_GPIO_NUM    -1
#define RESET_GPIO_NUM   -1
#define XCLK_GPIO_NUM    4
#define SIOD_GPIO_NUM    18
#define SIOC_GPIO_NUM    23

#define Y9_GPIO_NUM      36
#define Y8_GPIO_NUM      37
#define Y7_GPIO_NUM      38
#define Y6_GPIO_NUM      39
#define Y5_GPIO_NUM      35
#define Y4_GPIO_NUM      14
#define Y3_GPIO_NUM      13
#define Y2_GPIO_NUM      34
#define VSYNC_GPIO_NUM   5
#define HREF_GPIO_NUM    27
#define PCLK_GPIO_NUM    25

#define LED_GPIO_NUM     22

#elif defined(CAMERA_MODEL_M5STACK_PSRAM)
#define PWDN_GPIO_NUM     -1
#define RESET_GPIO_NUM    15
#define XCLK_GPIO_NUM     27
#define SIOD_GPIO_NUM     25
#define SIOC_GPIO_NUM     23

#define Y9_GPIO_NUM       19
#define Y8_GPIO_NUM       36
#define Y7_GPIO_NUM       18
#define Y6_GPIO_NUM       39
#define Y5_GPIO_NUM        5
#define Y4_GPIO_NUM       34
#define Y3_GPIO_NUM       35
#define Y2_GPIO_NUM       32
#define VSYNC_GPIO_NUM    22
#define HREF_GPIO_NUM     26
#define PCLK_GPIO_NUM     21

#elif defined(CAMERA_MODEL_M5STACK_V2_PSRAM)
#define PWDN_GPIO_NUM     -1
#define RESET_GPIO_NUM    15
#define XCLK_GPIO_NUM     27
#define SIOD_GPIO_NUM     22
#define SIOC_GPIO_NUM     23

#define Y9_GPIO_NUM       19
#define Y8_GPIO_NUM       36
#define Y7_GPIO_NUM       18
#define Y6_GPIO_NUM       39
#define Y5_GPIO_NUM        5
#define Y4_GPIO_NUM       34
#define Y3_GPIO_NUM       35
#define Y2_GPIO_NUM       32
#define VSYNC_GPIO_NUM    25
#define HREF_GPIO_NUM     26
#define PCLK_GPIO_NUM     21

#elif defined(CAMERA_MODEL_M5STACK_WIDE)
#define PWDN_GPIO_NUM     -1
#define RESET_GPIO_NUM    15
#define XCLK_GPIO_NUM     27
#define SIOD_GPIO_NUM     22
#define SIOC_GPIO_NUM     23

#define Y9_GPIO_NUM       19
#define Y8_GPIO_NUM       36
#define Y7_GPIO_NUM       18
#define Y6_GPIO_NUM       39
#define Y5_GPIO_NUM        5
#define Y4_GPIO_NUM       34
#define Y3_GPIO_NUM       35
#define Y2_GPIO_NUM       32
#define VSYNC_GPIO_NUM    25
#define HREF_GPIO_NUM     26
#define PCLK_GPIO_NUM     21

#define LED_GPIO_NUM       2

#elif defined(CAMERA_MODEL_M5STACK_ESP32CAM)
#define PWDN_GPIO_NUM     -1
#define RESET_GPIO_NUM    15
#define XCLK_GPIO_NUM     27
#define SIOD_GPIO_NUM     25
#define SIOC_GPIO_NUM     23

#define Y9_GPIO_NUM       19
#define Y8_GPIO_NUM       36
#define Y7_GPIO_NUM       18
#define Y6_GPIO_NUM       39
#define Y5_GPIO_NUM        5
#define Y4_GPIO_NUM       34
#define Y3_GPIO_NUM       35
#define Y2_GPIO_NUM       17
#define VSYNC_GPIO_NUM    22
#define HREF_GPIO_NUM     26
#define PCLK_GPIO_NUM     21

#elif defined(CAMERA_MODEL_M5STACK_UNITCAM)
#define PWDN_GPIO_NUM     -1
#define RESET_GPIO_NUM    15
#define XCLK_GPIO_NUM     27
#define SIOD_GPIO_NUM     25
#define SIOC_GPIO_NUM     23

#define Y9_GPIO_NUM       19
#define Y8_GPIO_NUM       36
#define Y7_GPIO_NUM       18
#define Y6_GPIO_NUM       39
#define Y5_GPIO_NUM        5
#define Y4_GPIO_NUM       34
#define Y3_GPIO_NUM       35
#define Y2_GPIO_NUM       32
#define VSYNC_GPIO_NUM    22
#define HREF_GPIO_NUM     26
#define PCLK_GPIO_NUM     21

#elif defined(CAMERA_MODEL_AI_THINKER)
#define PWDN_GPIO_NUM     32
#define RESET_GPIO_NUM    -1
#define XCLK_GPIO_NUM      0
#define SIOD_GPIO_NUM     26
#define SIOC_GPIO_NUM     27

#define Y9_GPIO_NUM       35
#define Y8_GPIO_NUM       34
#define Y7_GPIO_NUM       39
#define Y6_GPIO_NUM       36
#define Y5_GPIO_NUM       21
#define Y4_GPIO_NUM       19
#define Y3_GPIO_NUM       18
#define Y2_GPIO_NUM        5
#define VSYNC_GPIO_NUM    25
#define HREF_GPIO_NUM     23
#define PCLK_GPIO_NUM     22

#define LED_GPIO_NUM      33

#elif defined(CAMERA_MODEL_TTGO_T_JOURNAL)
#define PWDN_GPIO_NUM      0
#define RESET_GPIO_NUM    15
#define XCLK_GPIO_NUM     27
#define SIOD_GPIO_NUM     25
#define SIOC_GPIO_NUM     23

#define Y9_GPIO_NUM       19
#define Y8_GPIO_NUM       36
#define Y7_GPIO_NUM       18
#define Y6_GPIO_NUM       39
#define Y5_GPIO_NUM        5
#define Y4_GPIO_NUM       34
#define Y3_GPIO_NUM       35
#define Y2_GPIO_NUM       17
#define VSYNC_GPIO_NUM    22
#define HREF_GPIO_NUM     26
#define PCLK_GPIO_NUM     21
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

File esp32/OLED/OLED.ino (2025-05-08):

#include <Arduino.h>
#include <U8x8lib.h>
#include <Wire.h>


const int buttonPin = 1;     // the number of the pushbutton pin
int buttonState = 0;         // variable for reading the pushbutton status

// #define PIN_WIRE_SCL D5 // where D5 is the pin name for I2C SCL (clock) signal
// #define PIN_WIRE_SDA D4 //where D4 is the pin name for I2C SDA (data) signal

// U8X8_SSD1306_128X64_NONAME_HW_I2C u8x8(/* clock=*/ PIN_WIRE_SCL, /* data=*/ PIN_WIRE_SDA, /* reset=*/ U8X8_PIN_NONE);   // OLEDs without Reset of the Display

U8X8_SSD1306_128X64_NONAME_HW_I2C u8x8(/* reset=*/ U8X8_PIN_NONE);   // OLEDs without Reset of the Display

void setup(void) {
  u8x8.begin();
  u8x8.setFlipMode(1);   // set number from 1 to 3, the screen word will rotary 180

    // initialize the LED pin as an output:
  pinMode(LED_BUILTIN, OUTPUT);
  // initialize the pushbutton pin as an input:
  pinMode(buttonPin, INPUT_PULLUP);
}

void loop(void) {
  u8x8.setFont(u8x8_font_chroma48medium8_r);
  u8x8.setCursor(0, 0);
  u8x8.print("Hello World!");

    // read the state of the pushbutton value:
  buttonState = digitalRead(buttonPin);

  // check if the pushbutton is pressed. If it is, the buttonState is HIGH:
  if (buttonState == HIGH) {
    // turn LED on:
    digitalWrite(LED_BUILTIN, HIGH);
  } else {
    // turn LED off:
    digitalWrite(LED_BUILTIN, LOW);
  }

}

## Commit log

2022-01-05 testing in progress - camera not working at the moment so turning off
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2022-01-26 Tweaking DeviceID field type
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2022-01-30 fix api request values
    [log.py]
2022-01-30 add temperature warning logging
2022-01-30 raise error if non 200 response code from api
    [log.py]
2022-01-31 shutdown even if camera error occurs
2022-01-31 wait before poweroff in test.py
2022-02-01 fix datetime NameError and log errors
    [coreScript.py]
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2022-02-01 add temperature warning log
2022-02-01 fix requests undefined error
    [coreScript.py]
2022-02-01 ensure no memory error with multple photo calls
    [coreScript.py]
2022-02-01 fix camera double instancing
    [coreScript.py]
2022-02-05 Fixing timing issues locally
    [coreScript.py]
2022-02-07 Tweak coreScript to log telemetry if camera fails
    [coreScript.py]
2022-02-07 Destorying camera to reduce power consumption
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2022-02-24 #21 - image upload and ignore telemetry failure
    [coreScript.py]
2022-04-05 Fixing #23 (well... mitigating)
    [coreScript.py]
2022-04-07 Error handling for camera
    [coreScript.py]
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2022-06-17 pijuice fault tolerance - maybe
    [coreScript.py]
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2022-08-15 Optimsiations/better handling of low disk space issues - not tested yet
    [uploadPending.py]
2022-08-15 typo - getting tired of this
2022-10-03 Timelapse calcs and parts list
    [Timelapse_calc.xlsx]
2023-01-24 Add no devices message
2023-01-25 Filter organisations view to only include organisations that the user is a part of
2023-02-15 pi camera v3 in progress
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2023-03-06 Troubleshooting telemetry save issue
    [saveTelemetry.py]
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2023-03-27 Sleep on low battery
2023-03-27 Tweaking low battery behaviour - ensuring battery not present doesn't cause going to sleep.
    [saveTelemetry.py]
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2023-04-03 90mm models
    [camera mount.stl, enclosure.90mm.stl, end cap.90mm.stl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]
2023-04-04 Updating Systen Power Switch to 2100mA, and switching off when shutting down.
2023-04-04 Turning system power on at start, and changing voltage check to 3v
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2023-04-11 Leave telemetry in place if network error
    [uploadPending.py]
2023-04-12 Telemetry view - battery voltage
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2023-04-13 Tweaking battery mount
    [enclosure.90mm.stl]
2023-04-17 FlashForge-PETG default GCODE
    [top cap.90mm.g]
2023-04-17 PETG Attempt 1
    [top cap.90mm.g]
2023-04-17 Adjusting base print speed 50mm -> 30mm/s
    [top cap.90mm.g]
2023-04-18 Readding Pi mount
    [enclosure.90mm.stl]
2023-04-18 Slicing adjustments: - Switched base speed back up from 30mm/s to 50mm/s - Interior visible shell 70% -> 40% of base speed - Shell print order from "anti-overrush deceleration" to from "inner to oute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
    [top cap.90mm.g]
2023-04-20 Tweaking exterior speed to 30% (15mm/s) to try and avoid stringing - PETG attempt 4 slower exterior
2023-04-24 PolarCloud slicer using PETG Attempt 5 profile, 3 shell thickness and 0.3mm resolution
    [top cap.90mm.g]
2023-04-25 Enclosure mount - first attempt
    [enclosure.90mm.stl]
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2023-04-29 Mount and 110mm enclosure
    [enclosure.110mm.stl, mount.g, mount.stl]
2023-05-03 turnOnSystemPowerSwitch retries & power off modem
2023-05-03 110mm top and base caps
    [end cap.110mm.stl, top cap.110mm.stl]
2023-05-03 110mm caps GCode
    [top cap.110mm.g]
2023-05-04 Assembly notes in progress
2023-05-05 Assembly notes in progress...
2023-05-12 Old code no longer working. Removed
    [savePhotos.py]
2023-05-22 DateTime localisation fix Adding camera preview to telemetry page Allowing for old imagery to be shown
2023-05-26 Fixing turnOnSystemPowerSwitch() to try for 1 minute, not 1 hour
    [uploadPending.py]
2023-05-26 inidcateStatus to turn power switch on
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2023-05-26 Red LED 10s -> 5s when turning off power switch
2023-06-14 Safety wakeup in case Pi crashes
    [saveTelemetry.py]
2023-06-16 Detecting failure to upload imagery for 10 minutes and restarting
    [saveTelemetry.py, uploadPending.py]
2023-06-19 Switching off support mode
2023-06-28 Updating low voltage threashold for powering up modem from 3.0 to 3.2V
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2023-07-13 More wake up troubleshooting... - is it powering off in the middle of a restart?
2023-07-19 Tweaking sleep decision - fixing error
    [saveTelemetry.py]
2023-07-31 Extra telemetry display, and prevent shutdown if in support mode
    [saveTelemetry.py]
2023-08-02 Stay awake if charging
2023-08-13 Showing retired devices' events
2023-08-14 Stay on if powered
2023-08-15 First go at SIM7600 power up & connect script
2023-08-15 SetSystemPowerSwitch/powerup/down 7600 - needs tidying.
2023-09-03 Possible cause of multiple power up/sdown of SIM7600X?
2023-09-20 Fixing SMS decoding issue
    [SIM7600X.py, handleSMS.py]
2023-11-26 Camera flip for sedicam_v2_LiFePO4
2023-11-29 Tweaking shutdown/power off timing to account for powerDownSIM7600
2023-11-29 upload timings & remove HandleSMS from LiFePO4 cameras
2023-11-29 Low battery shouldn't cause 10m sleep if we're charging.
2023-11-30 flash LED D2, and making eink and image preview configurable
2023-11-30 Oooops - removed line by mistake
    [updateStatus.py]
2023-11-30 LED indication of uploads
2023-11-30 Tweaking/fixing detection of internet connection failure
    [uploadPending.py]
2023-12-10 First attempt exiting hibernation mode on button press
2023-12-11 Tweaking camera flip
2023-12-18 updateStatus - not updating LEDs if not in support mode.
2023-12-28 forgot to import SocketHandler
2024-01-05 add typing to socket logger script
2024-01-05 change debug printing to logging
2024-01-15 Device trends - showing images only (vs pending), and image thumbnails
2024-02-05 Map view - mostly working - need to add all cameras to single page.
2024-02-06 Device Servicing and Wide Angle
2024-02-16 Device - Short Description
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2024-03-14 Copy of smaple code from https://github.com/limengdu/SeeedStudio-XIAO-ESP32S3-Sense-camera/tree/main/take_photos
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2024-03-22 Simple image saving - issues when powered by battery
    [OLED.ino, take_photos.ino]
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2024-04-15 esp32 stuff in progress....
2024-04-15 Whilst sleeping due to low power, stay awake for first 10 minutes of the hour to give a chance to upload
2024-04-15 Whilst sleeping - prevent sleep if support is True + fixing 10 minutes past hour logic
    [saveTelemetry.py]
2024-04-16 Detect battery being disconnected and RTC reset
    [saveTelemetry.py]
2024-04-19 Device Trends improvements - supress warnings from support/service/hibernate/powered off devices
2024-04-22 Switch off wakeup alarm explicitly if not being set
2024-04-22 Stop unexpected break out of power off caused by power off at night
2024-05-02 host names as cameras updated
2024-05-28 RTC stuff - plus editor seems to have changed whietspace.
    Boot count not working, and RTC rest when power lost.
    [take_photos.ino]
2024-05-29 String buffer issue - was causing error: stack smashing protect failure
    [take_photos.ino]
2024-05-30 MAC address working - time formatted correctly - but image not uploading - giving 400.
    [take_photos.ino]
2024-05-31 Failed attempt with http.getStreamPtr()
    [take_photos.ino]
2024-05-31 Still not working - some files uploaded but appear corrupted, and others still causing errors:
    Failed to read the request form. The stream exceeded the data limit 16384.
    Failed to read the request form. Line length limit 15573 exceeded.
    [take_photos.ino]
2024-06-04 Image flip, upload most recent first, and batch size of 10.
    [take_photos.ino]
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2024-06-04 Event Detail - added 5 minute context either side of event, and added pause/play/navigate buttons
2024-06-07 Scrolling telemetry - in progress... before switch to from/to date
2024-06-09 ESP32 Telemetry - in progress - doesn't compile yet. Backing up
    [take_photos.ino]
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2024-06-11 DeviceTrends - day shading and colour/highlight of chart
2024-06-12 Low power tweaks - Set default watchdog to 1 minute - Fixed 60 hour watchdog and switched to 2 hours (was supposed to be 1 hour) - Changed to hibernate mode at 10% - Tweaked startup sequence to delay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
    [saveTelemetry.py]
2024-06-12 modem power and install script
2024-06-12 script reboot for power tweaks
2024-06-12 Ensure we reset watchdog if going to 10 min sleep
    [saveTelemetry.py]
2024-06-14 Battery percentage hack for ESP32S3
2024-06-14 Voltage hack to LatestTelemetry and a bit of caching
2024-06-15 Battery percent hack fix
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2024-06-24 TPL5110_Reset_PIN seems to be working, but possibly not waking? RTC was intermittently working correctly with dev board.
    [take_photos.ino]
2024-06-24 Reset pin doesn't seem to like A1 or D1 - change to D7 (lower right) - seems happier
    [take_photos.ino]
2024-06-28 Battery level - not sure it's correct as it's reporting 100% with no battery
    [take_photos.ino]
2024-07-18 Sample code from Waveshare for #85
2024-10-14 Skipping SIM7600 stuff if we're not using SIM7600
    [SIM7600X.py]
2024-11-07 Unsecuring GetImageAtOrAround & making Live View button pass through api-key if being used
2024-11-13 Removing retired devices from events list
2024-11-29 Tweak / syntax error
    [helpers.py, testPhase.py]
2024-11-30 Fixing timezone suncalc issue - a bit cludgy
    [helpers.py, testPhase.py]
2024-12-06 Fixing long exposure issue - default argument was getting set once on startup
    [helpers.py, savePhotos.py]
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2025-05-29 Device trends - make Admin only, and show retired devices. Telemetry controller - remove surrounding dates for performance Updating install notes Resolving #87 - suncalc install issue
2025-06-05 Fixing DeviceTrends link
2025-07-16 DeviceTrends -> Edit device page
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2026-05-08 Amp -> mA, volts -> mV
2026-05-08 batteryStatus - getting to upload and display
2026-05-09 Troubleshooting pvpi alarm not working
    [saveTelemetry.py]
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2026-05-10 Claude's attempt to fix the failure to wake
    [saveTelemetry.py]
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2026-05-11 Revert "Troubleshooting alarm - is in set in UTC?"
    This reverts commit 8114529e84e281953f914cb9c7147a4afa069a66.
    [saveTelemetry.py]
2026-05-17 Removing supportMode check for low power behaviour to protect battery
2026-05-18 Detecting low battery by voltage rather than estimated soc
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2026-06-03 Powering up SIM7600 prior to calling receiveSMS
2026-06-03 Handle rec_buff is None - e.g. no waveshare board?
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2026-06-23 Tweaking usb power / power switch code to be compatible with PiJuice approach
2026-06-24 Correcting previous re typo
    [uploadPending.py]
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
